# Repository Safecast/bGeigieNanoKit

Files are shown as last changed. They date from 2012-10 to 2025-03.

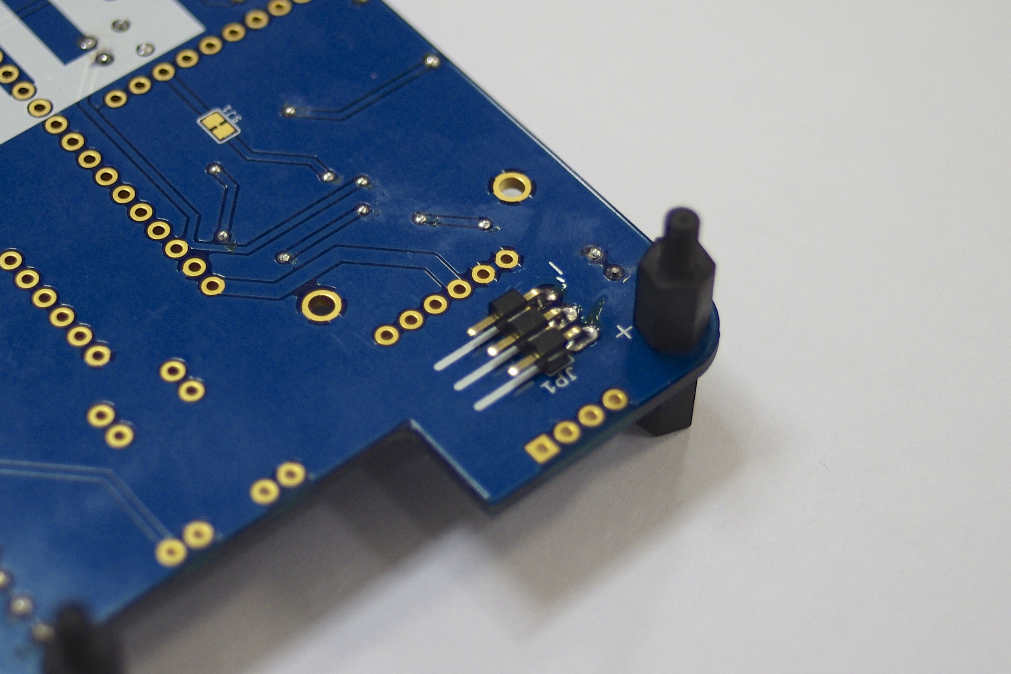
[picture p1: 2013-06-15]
nano manual named pics/iRover_header_tip.jpg

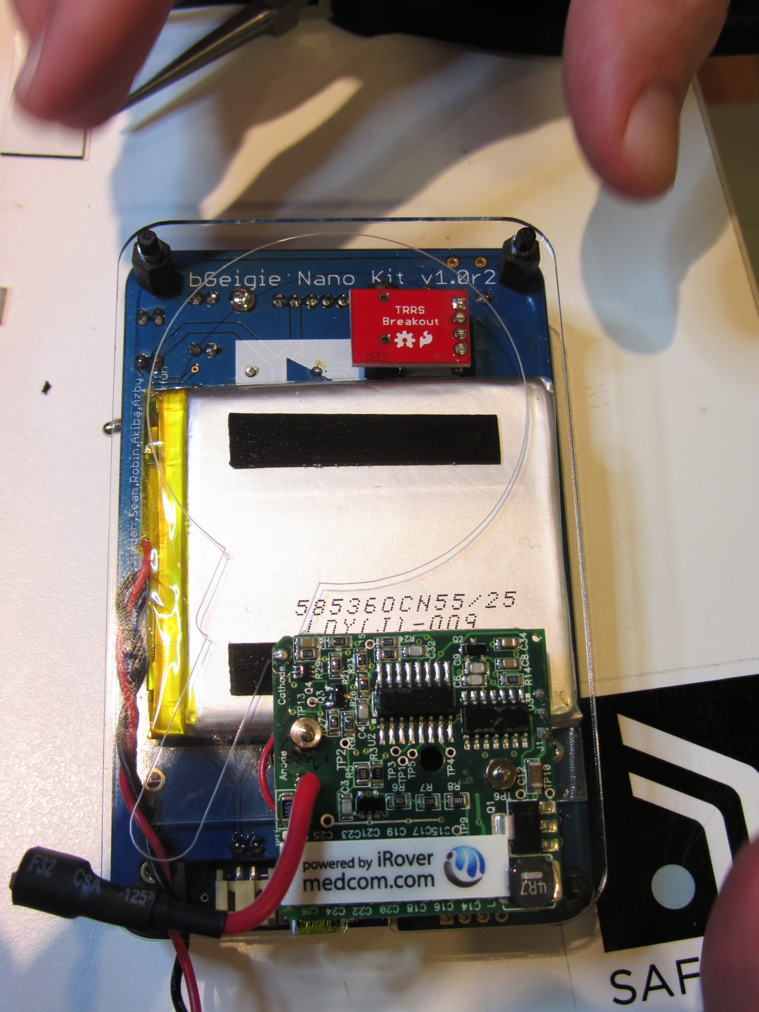
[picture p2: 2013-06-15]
nano manual named pics/iRover_placement_over_battery.jpg

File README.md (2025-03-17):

## bGeigie Nano Kit Operating Instructions (Updated March 2025)

# Table of Contents

1.  [Introduction](#introduction)
2.  [Powering the Device On](#powering-the-device-on)
3.  [Switching Between Modes](#switching-between-modes)
4.  [Measuring Ionizing Radiation in Logging Mode](#measuring-ionizing-radiation-in-logging-mode)
5.  [Measuring Ionizing Radiation in Surface Mode](#measuring-ionizing-radiation-in-surface-mode)
    1. [Alarm](#alarm)
    2. [Data Log](#data-log)
6.  [Uploading Data to the Safecast Database With the Safecast API](#uploading-data-to-the-safecast-database-with-the-safecast-api)
7.  [Uploading Data to Other Datasets](#uploading-data-to-other-datasets)
8. [Using Safecast With Mobile Apps](#using-safecast-with-mobile-apps)
9. [Troubleshooting](#troubleshooting)
    1. [Troubleshooting the iSafecast Geiger Bot App for iOS](#troubleshooting-the-isafecast-geiger-bot-app-for-ios)
    2. [Troubleshooting the iSafecast Geiger Bot App's API](#troubleshooting-the-isafecast-geiger-bot-apps-api)
    3. [Troubleshooting Other Issues](#troubleshooting-other-issues)
        1. [Firmware](#firmware)
    4. [Cleaning](#cleaning)
10. [Warranty Information](#warranty-information)
11. [Hardware Cautions](#hardware-cautions)
12. [Resources and Support](#resources-and-support)

## Introduction
The Safecast bGeigie Nano kit is a *geo-tagged mobile sensor of ionizing radiation*. It is equipped with Internet data sharing capability and optional wireless capability. 

The term "radiation" refers to energy emitted by a source. This includes light, heat, microwaves, and other types of energy. Ionizing radiation is a type radiation that has so much energy that it removes electrons from the atoms and molecules that make up air, water, and living tissue. This activity can harm the molecules in our bodies, leading to diseases like cancer. Radiation can come from either natural or human-made sources. Natural sources include radioactive rocks, elements, and a radioactive gas called radon. Human-made sources include nuclear power plants and medical diagnostic tests, such as x-rays.

The bGeigie Nano measures alpha, beta, and gamma radiation. 

| Type | Description |
| ---- | --- |
| Alpha Radiation | Alpha particles are charged particles that have a large mass and charge. As a result, they don't penetrate materials as easily as other types of ionizing radiation. They also don't travel very far. |
| Beta Radiation | Beta particles are similar to electrons. They are lighter than alpha particles and travel farther, up to a few feet through air. |
| Gamma Radiation | Gamma particles are the most powerful form of ionizing radiation. They travel very far at the speed of light and penetrate most materials easily. Thick layers of concrete, lead, steel, or similar materials are required to stop gamma particles. |

The Nano's maximum operating range is about 350,000cpm, or 1mSv/h (1 millisievert per hour dose rate or 1000µSv/h microsieverts per hour). 

The Nano can be mounted on a car window, or used for static or spot radiation detection. Nano users can submit their mobile radiation measurements to Safecast, an online global mapping system developed by Safecast and MIT Media Lab. 

The Nano also records location, date, and time. The location data allows Safecast to map the measurements and understand the distribution of ionizing radiation. Safecast uses the date and time information to track how ionizing radiation concentrations change over time. The do-it-yourself kit enables customization, cost savings, and learning. 

## Powering the Device On

To turn the unit on, slide the switch at the lower right to the up position. 

The SAFECAST logo will appear on the display for approximately one second. The next start-up screen displays the name of model (bGeigie Nano), the firmware version number, battery charge level, basic settings, and the user’s name (or other customizable information).  

## Switching Between Modes

* The bGeigie Nano has two operating modes, "display" and "recording". To alternate between them, use the toggle switch at the upper right. Label on the transparent top panel: (to the right) "bq/m^2; uS/h", (to left) "log; cpm".

+ The “up” position (to the right) switches the unit into display mode (in which there is no data logging). The fields on the OLED indicate uSv/h dose-rate (Cs137), max dose-rate, dosimeter, Bq/m2 display (Cs137), time stamp, and alarm. 

+ The “down” position puts the Nano into recording mode. The OLED shows indicators for CPM and µSv/h, the number of satellites locked, altitude (meters), distance traversed (km), total duration of measurement (h:m), and time stamp (dd:hh:mm:ss). When the Nano is in recording mode, the OLED shows whether a micro-SD memory card is currently inserted. 

## Measuring Ionizing Radiation in Logging Mode

While in recording mode, the OLED display also shows a GPS lock indicator. When the device locks onto a GPS signal, it will show the number of satellites found, and a small red LED will glow. If the device isn't getting a lock, try placing it near a window for a few minutes.

The small red LED will only glow if the GPS is locked, the SD card is present, the battery has more than 10% charge left, the unit has been on for one minute, and the Geiger tube is providing a pulse. It can be dimmed by setting DIP switch #2 to "Off."

The speaker "clicks" and a small blue LED blinks with each pulse from the Geiger tube. It can be dimmed by setting DIP switch #1 to "Off."

The red LED on the GPS unit blinks every 1 second when the GPS is not locked. Once locked, it blinks every 10 seconds.

The date and time are in __UTC__ (formerly called GMT), rather than local time. The __date/time stamp__ refreshes when log data is written to the card. The LOG's file name is based on the time stamp   (e.g., 21080716.LOG).  The UTC log filename may be +/- one day off from the local date of the measurement, depending on the difference between time zones and distance from the International Date Line (IDL). The file metadata is not updated, which means the log's file creation date may appear with a default date, such as 01/01/2000. For this reason, we recommend that you sort your logs by filename instead of the date field.  When uploading a log, please enter its metadata in the required fields, and submit it for approval. 

**GPS Reset Procedure** (ver 1.3.0 and later)

To reset the GPS device: 

1) Turn off the bGeigie
2) Remove the SD card
3) Turn the bGeigie back on and leave it on for one minute 

    After approximately 10 seconds, the display will show the message "NO SD CARD/GPS Reset." Note that powering the unit on without the SD card will cause an error and **re-initialize the unit, including the GPS controller**.

4) Turn the device off again
5) Insert the SD card

## Measuring Ionizing Radiation in Surface Mode

Use surface mode to detect surface contamination. Removing the Nano from its case while in surface mode can increase the Nano's ability to detect alpha and beta radiation.

1. Remove the Nano from its case (with or without the rubber liner). Use both thumbs to push the unit in and then swivel it out. When you reinsert the Nano into the case later on, you can do it either above or inside the removable rubber liner.

While in uSv/Bq mode, the display also shows the peak dose rate (in uSv/h), total accumulated dose (in uSv), and CPM. 

The mode switch sets the bGeigie Nano into "Log Mode" (switch down "log cpm"). In Log Mode, the largest area of the display ("the big numbers") shows the count rate in CPM, and data will be written to the SD card.  In "Survey Mode" (switch up "Bq/m2 uSv/h"), the main part of the display will show the dose rate in microsieverts per hour.

- To measure the uSv dose rate accurately, put the Nano in the case, hold it 1m above the ground, tilt it around 45 degrees, and then wait for approximately one minute for a stable reading.

- To measure bQ accurately, take the Nano out of the case, keep it within 5cm to 1cm from the surface, and wait approximately one minute for a stable reading. Then, read the value on the second line in Bq/m2. The Nano will emit a speaker sound to aid in finding hotspots.

- The dose rate is based on the assumptions that the Nano is in its case; it is about 1 meter (3ft) away from any object or surface; any gamma rays are of moderate energy (600~700KeV); and the unit has met the previous conditions for at least one minute.

- Also in Survey Mode, the second line on the display ("the small numbers") will rotate through several other values. One of those will be Bq/m2. That is only a locally displayed interpretation of the data, and requires very different conditions to be correct: the Nano is _out_ of its case and held 1cm (~half inch) from a surface contaminated with radio cesium. This usage probably only works in Fukushima and Chernobyl.

### Limitations  

The grid on the pancake sensor is only useful when you remove the unit from the case to look for surface contamination. The grid itself has a very small shielding effect, mostly for alpha/beta and weak gamma radiation. The effect is minimal, and can be ignored.

When averaging readings from two different Nanos, you should only compare long-term counting (e.g. number of counts for 10 minutes).
 
### Alarm
- A speaker "clicks" and a small blue LED “Count” blinks with each pulse from the Geiger tube. It can be dimmed by setting DIP switch #1 to "Off."
- A small Red LED “Log/Alarm” flickers on pulse, and remains lit on alarm. It will only glow if the GPS is locked, the SD card is present, the battery has more than 10% charge left, the unit has been on for one minute, and the Geiger tube is providing a pulse. It can be dimmed by setting DIP switch #2 to "Off."
- The Piezo buzzer may not loud enough for all users. There are solder pads available on the Nano main board for an optional audio-out connector that can be used to connect an amplifier or sound recorder to get louder clicks, if desired.

### Data Log

In recording mode, the data log file writes to the micro-SD card. A key to the fields in the Data Log is available in the [bGeigie library README.md by fakufaku](https://github.com/Safecast/SafecastBGeigie). 

The data is formatted similarly to the NMEA sentences that GPS uses. It begins with a dollar sign ($) and ends with an asterisk (*). A checksum follows the star.

>Radiation Data Sentence: This is the basic message containing the geo-located radiation measurement.

>EXAMPLE:

>$BNRDD,300,2012-12-16T17:58:31Z,30,1,116,A,4618.9612,N,00658.4831,E,443.7,A,5,1.28*6D

**KEY**

| Field | Description | Example|
| ----- | --- | ---- |
| Header | the device model header | Mini=BMRDD, Nano=BNRDD, NX=BNXRDD |
| Device ID | the device serial number | 300 |
| Date  | the date, formatted according to the ISO-8601 standard, usually in UTC | 2012-12-16T17:58:31Z |
| Radiation 1 minute  | the number of pulses given by the Geiger tube in the last minute | 30 |
| Radiation 5 seconds  | the number of pulses given by the Geiger tube in the last 5 seconds | 1 |
| Radiation total count | the total number of pulses recorded since startup |  116  |
| Radiation count validity flag  | 'A' indicates the counter has been running for more than one minute, and the one-minute count is not zero. Otherwise, the flag is 'V' (void) | A |
| Latitude | as given by GPS; the format is ddmm.mmmm, where dd is decimal degrees and mm.mmmm is decimal minutes |  4618.9612 |
| Hemisphere |  'N' (north), or 'S' (south) | N |
| Longitude | as given by GPS; he format is dddmm.mmmm where ddd is decimal degrees and mm.mmmm is decimal minutes | 00658.4831 |
| East/West | 'W' (west) or 'E' (east) from the Prime Meridian | E |
| Altitude |  the altitude (above sea level), as given by the GPS, in meters | 443.7 |
| GPS validity | 'A' = Available or OK, 'V' = Void or invalid | A |
| Number of satellites | the number of satellites used by the GPS | 5 |
| HDOP | the Horizontal Dilution of Precision (HDOP), or relative accuracy of the horizontal position | 1.28 |
|Checksum |  | *6D |

*(For possible updates, see the current [README.md](https://github.com/Safecast/SafecastBGeigie/blob/master/README.md) in the technical GitHub repository)*

The data log file name is comprised of three parts: The DID number, the month the log was initiated, and the day the log was initiated. For example, "21080716.LOG" is the data log for unit 2108 from 16 July. Due to space constraints, the file date property is 01/01/2000. However, every line has UTC time date stamp reading.  The log file name may appear to be a day off due to time zone differences.

A data log or section begins with several comment lines, which begin with hash signs (#).

EXAMPLE:

>\# NEW LOG

>\# format=1.2.9nano

>\# deadtime=on

>$BNRDD,2108,2013-12-06T13:03:58Z,22,2,115,A,3145.7607,N,03510.1975,E,734.90,V,3,908*64

One of the comment lines contains the deadtime. [Deadtime](http://en.wikipedia.org/wiki/Dead_time) is "the time after each event during which the system is not able to record another event."  You can find the *ENABLE_LND_DEADTIME compensation formula* in the [bGeigieNano.ino master repository](https://github.com/Safecast/bGeigieNanoKit/blob/master/src/bGeigieNano.ino). 

### Uploading Data to the Safecast Database With the Safecast API

Your device is designed to submit data to the Safecast database through the Safecast API. To enable data submission, you’ll need to obtain an API key. The key is a credential that gives you access to the API, much like a username and password give you access to an email account.

You can [register on the Safecast site](https://api.safecast.org/en-US/users/sign_up) to get an API key. 

You can learn about how the Safecast API works by visiting the [API documentation](https://api.safecast.org/).

### Uploading Data to Other Datasets

Nano data can be submitted to other radiation mapping datasets. For example, the free [Geiger Bot iOS app](https://sites.google.com/site/geigerbot/) allows you to upload data to servers other than the [Safecast API dataset](https://api.safecast.org/). To do so, you'll need to configure the app with the details of your device, the particular sensor, data format, connection, and other information.  

### Using Safecast With Mobile Apps 

The official (currently not availble)[Safecast app for iOS](https://itunes.apple.com/us/app/safecast/id571167450?mt=8) brings our extensive dataset of radiation measurements to your mobile device, and provides a full toolset to help you perform measurements with your own instrument such as a Geiger or scintillation counter (not included). The app functions as a virtual Geiger counter, allowing you to see your location on a map while displaying radiation readings that have been taken nearby. The app is currently for iOS only. 

In addition, the Safecast Drive app [Android](https://github.com/Safecast/bGeigie-Drive) enables you to:

- Connect with your bGeigieNano (if you have the [bGeigeCast](https://bgeigiezen.safecast.jp/store-2/bgeigiecast-build-for-bgeigienano/) module installed), record data, and upload the data to Safecast directly, without removing your MicroSD card
- Access previous logs and update their status

**Common Issues**

1. Wrong cable - A "null modem" cable that swaps wires internally may cause problems. The cable should be straight/passthrough.
2. Input voltage too high - Interferes with the audio route and the audio engine's watchdog timer.
3. Mic-ground in the cable not shorted correctly - The app will report an audio route change to "Headphones" on the console. The audio route required for a line input cable is "Headset."

>>Nick Dolezal is working hard on the new version of the Safecast app (which will allow on demand refreshing of the map data) decided to whip up these alternate visualizations of the Safecast data. These maps show the frequency of samples taken – NOT READINGS OF THOSE SAMPLES – just showing how often a specific place has been measured. In this example, a location (like Fukushima) that has been measured repeatedly would show hot. Thought this was a really interesting look at the work Safecast has done over the last 2+ years

#### Troubleshooting the iSafecast Geiger Bot App's API

On the main numeric display of the app, you can tap on the top part of the screen to show detailed log messages containing information on connection attempts, and which input device is selected. If successful, the API upload will return HTTP 201 CREATED.

**Verify Input**

1. Tap the min/max arrow button in the lower-right hand corner of the map to resize it into a small window. The interface will display fixed buttons at the bottom, and four possible display screens at the top. These four screens are "Main Numeric Display," "CPS/CPM graph," "Audio input monitor graph," and "Map."

2. Tap the "<" button next to the white page dots under the map. The audio input monitor will appear.

3. Verify that the counts from the Onyx appear and that they're correct. The black line represents the input. The stationary red line represents the threshold the input volume must exceed for it to be counted. The black line will appear blue when it has been counted as a pulse.

If you're unable to verify input, you may have a defective serial cable. A "Geiger Pulse" setting on the Onyx of other than the default value of 6 may also cause problems. 

4. Configure the App's Settings

a. Tap the "Settings" icon on the fixed button panel (the machine gear). Scroll to the bottom of the list and select "Safecast."
b. Enter your API key. Change the upload interval as desired, but do not change the Safecast device back to Nano. 

#### Troubleshooting Other Issues

If you experience problems with the display, check all solder joints carefully to verify that you haven't missed a joint, or that you don't have a cold solder joint. These issues can cause the display to act unpredictably.

You can report bugs and other issues at the [issues page](https://github.com/Safecast/bGeigieNanoKit/issues) of the Safecast GitHub repository. Volunteer users report problems and bugs in the devices discussion group. 

##### Firmware
* For the current version of the firmware, see the the .hex file in the [bGeigieNanoKit repository](https://github.com/Safecast/bGeigieNanoKit).

* To learn how to update the firmware of the Fio via FTDI, see the ["How to Update the Firmware" page](https://github.com/Safecast/bGeigieNanoKit/wiki/How-to-Update-the-Firmware) of this wiki.

### Cleaning

To clean the unit:

1. Remove the Nano from the case. Never wet the Nano's interior. 
2. Use a soft brush and air blower on the Nano, carefully. A vacuum may be another option (electronics labs use unheated air blowers for dusting off parts.)
3. Rinse the liner in clean water, if necessary. 
4. The case may be rinsed with a clean, slightly damp microfiber cloth. 
5. Turn the screen display off and wait until it's cool before wiping the LEDs. Wipe the screen using light pressure.  Use clean, lint-free cotton, microfiber cloths or low-lint wipes. 

### Warranty Information

For warranty information, email [contact@safecast.org](contact@safecast.org). 

**Calibration** 

“The sensor is pre-calibrated. The calibration of the unit for Bq for Cs assumes the grid is in front of the pancake. The difference is around 5%. For gamma only, the grid has a negligible effect on the measured value.

The uSv/h conversion from CPM is calibrated assuming the grid is on the tube. As all Safecast measurements are done with the pancake WITH grid, please keep the grid on the tube. The grid itself will not block alpha or beta radiation, but will reduce the sensitivity slightly, as the grid covers a small portion of the sensor. In practice, the difference with and without grid will be around 4-5% for a beta source, and less for a gamma source, according to bGeigie Nano user Jam.

The software we have preloaded on the device takes the sensor type into account and calibrates readings for Cs137. All bGeigie Nanos have the same configuration and can be compared against one other. A bGeigie Nano's calibration should never change, unless the device is broken. 

### Hardware Cautions

- The Pelican micro case is shockproof and water-resistant. However, it is not waterproof and it cannot be used underwater. Condensation can build up inside the case, due to temperature differences. While this condensation will evaporate with time, you can also remove it by opening the unit and drying it with fiber-free cloth. 

- Do not use the unit outside of its water-resistant case with wet hands, in the rain, or close to a dripping tap. 

- The Micro-SD cannot be read through a USB port. Use a micro-SD card reader instead.

**Battery Cautions:** 

Charge the unit with the mini-USB cable. The yellow LED will dim once the unit is fully charged. A full charge takes 5-6 hours. The bGeigie Nano runs approx 35-40 hours on a full charge in recording mode. 

The main battery indicator is the icon at the bottom right of the display. The percent of battery charge appears on the startup screen.

**NEVER charge the bGeigie while the unit is on.** The power MUST be turned OFF before charging to avoid permanent damage to the charge circuit. 

+ Replace a broken battery (that has a detached wire) with one that has the same rating (2000mAh 3.7V Lithium Polymer (Li-Po, Li-Poly). The Nano charge circuit may overheat if you use a larger battery.

+ A Li-Po battery can be hazardous if the mylar membrane is punctured. Please handle batteries carefully! 

**SENSOR Cautions:**

Although the Nano sensor inside its closed Pelican micro-case is well protected from shock and pressure transients, sudden changes in pressure (such as slamming a car door) may damage the sensor. The pressure inside the tube is very low, and the membrane is under constant tension from atmospheric pressure. Being at altitude *reduces* the strain on it. Because the membrane is mica (basically extremely thin glass), it is low-density and very brittle. A sharp shock can shatter it, and it will pop if something pokes it. 

- To avoid damage to the pancake sensor, NEVER touch the membrane! 

**Onyx Hardware Precautions:**

To keep the Onyx™ in good condition, handle it with care, and observe the following precautions:

- Do not contaminate the Onyx™ by touching it to radioactive surfaces or materials. Instead, hold it just above the surface that is suspected of contamination to take readings. 

- Do not leave the Onyx™ in temperatures over 122° F (50° C), or in direct sunlight for extended periods of time. 

- If the surface of the mica on your pancake detector becomes scratched or loses its coating, avoid making measurements with the detector window in direct sunlight, as this could affect the readings. 

- Do not put the Onyx™ in a microwave oven. It cannot measure microwaves, and you may damage it or the oven. 

#### Resources and Support

- [Nano catch-all landing page](https://safecast.org/bgeigie-nano/)

- [Safecast website](https://safecast.org/) - articles, news, notices, API uploads, crowdsourced radiation data and maps, and more

- [Safecast Devices Discussions and Support group](https://groups.google.com/forum/?hl=en#!forum/safecast-devices)

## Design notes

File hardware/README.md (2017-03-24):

# HW development for bGeigieNanoKit has moved
## New V1.0r4 boards eagle files are in bGeigieNanoKit v1.0r4 folder 
## Older development can be found here [SafecastEagleHW] (https://github.com/Safecast/SafeCastEagleHW)

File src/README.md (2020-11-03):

# Welcome to bGeigie Nano Kit project  
[Main bGeigie Nano page](http://blog.safecast.org/bgeigie-nano/)  
Assembly and Operations Manual can be found on the [Wiki](https://github.com/Safecast/bGeigieNanoKit/wiki)  
  
The Safecast bGeigie Nano is a mobile, GPS enabled, logging, radiation sensor. It is designed for mounting on the outside of a car window but can be used on bicycles, trains, planes, and other modes of transportation.  
  
It can also be used for taking static readings and contamination findings. In logging mode, the Nano takes a measurement every 5 seconds and logs the time and location coordinates.  

# Acknowledgements
This work would not exist without the original development by [bidouilles] (https://github.com/bidouilles/bGeigieNano) and contributions of other [safecast] (https://github.com/Safecast/bGeigieNano) developers.

# Requirements
* bGeigieNanoKit can be bought online from [KitHub](https://shop.kithub.cc/products/safecast-bgeigie-nano)
* for programing/updating software you need a FTDI cable drivers are at http://www.ftdichip.com/Drivers/VCP.htm
* solder iron
* time to make the kit (3-4 hours is normal)

# Build process 
(Needs compiler for example Crosspack-AVR on Mac)
http://www.ladyada.net/learn/avr/setup-mac.html

## Using the Makefile
    export ARDUINODIR=/home/geigie/arduino-1.0.1/
    export SERIALDEV=/dev/ttyUSB0
    export BOARD=fio
    cp -r libraries /home/geigie/arduino-1.0.1/
    make
    make upload

## Using the prebuilt image
You can use directly the prebuilt image to flash the Arduino Fio. Here is an example with Arduino Fio connected to ttyUSB0:

    /usr/bin/avrdude -DV -p atmega328p -P /dev/ttyUSB0 -c arduino -b 57600 -U flash:w:bGeigieNano.hex:i
    
Or Windows Users can download a small program called Xloader (http://russemotto.com/xloader/) and can directly flash a HEX file to the bGiegieNano (assuming you have a FDTI connection. Can be bought at many places like Adafruit, Seeedstudio, Switch-science etc.
Download and installed X-loader. Do not use the USB charging port on the Nano, but the 6 pin FTDI connector on the edge of the CPU board.
Purchase a   https://www.sparkfun.com/products/9873      FTDI breakout adapter.
 
When you plug this little FTDI breakout board onto the 6 pin header and then plug in via a usb cable into your computer, the Nano will power up by itself (even though the power switch is off).  Be careful here as you can plug it in upside down, so match the pins on the FTDI board with the pins on the cpu module.
 
Monitor the device manager com ports to see the device appear and what com # Windows assigned to the device.
 
Then Run X-loader, select com port, browse to HEX file, and I selected in the drop down Duemilanove/nano(ATmega328) device.  Leave the baud rate at 57600 and hit upload.   When it is done, the Nano rebooted/restarted all by itself and is running the new code.     Remove the FTDI board and usb cable to computer, and the Nano will power off. 

# Assembly

## Pins assignment

# Power consumption

* **Fio**: 0.045mA sleep, 6mA at run time
* **OpenLog**: 2mA idle, 6mA at maximum recording rate
* **Adafruit Ultimate GPS**: 25mA acquisition, 20mA tracking
* **Monochrome OLED 128x32 0.91"**: 4mA 50% turn-on, 7.8mA 100% turn-on

## Estimation
The total current used at run time can be estimated around 36mA (= 6+6+20+4) per second which will result in a consumption of 0.01mAh (= 36mA/3600). So
the total log duration if using a battery of 1300mAh will be (1300/.01)/3600 = 36.11 = **36h06m**

## Summary table

| Battery capacity (mAh) | Estimated log duration (days hh:mm) |
| :---: | :---: |
| 1300 | 1d 12:06 |
| 2600 |  3d 00:13 |
| 6600 |  7d 15:19 |

# Usage
Once powered on the bGeigieNano will initiliaze a new log file on the SD card, setup the GPS and start counting the CPM.

# Sample log

    # NEW LOG
    # format=1.0.0nano
    $BNRDD,204,2012-09-20T16:53:58Z,776,63,33895,A,5641.7788,N,1411.8820,E,9861.20,A,109,9*46
    $BNRDD,204,2012-09-20T16:54:03Z,771,61,33956,A,5642.2047,N,1412.9433,E,9862.60,A,109,9*4D
    $BNRDD,204,2012-09-20T16:54:08Z,773,70,34026,A,5642.6305,N,1414.0053,E,9865.00,A,109,9*40
    $BNRDD,204,2012-09-20T16:54:13Z,768,59,34085,A,5643.0562,N,1415.0662,E,9866.80,A,108,9*4D
    $BNRDD,204,2012-09-20T16:54:18Z,765,59,34144,A,5643.4820,N,1416.1277,E,9868.10,A,108,9*4D
    $BNRDD,204,2012-09-20T16:54:23Z,776,70,34214,A,5643.9077,N,1417.1884,E,9870.40,A,90,10*4E
    $BNRDD,204,2012-09-20T16:54:28Z,790,69,34283,A,5644.3330,N,1418.2491,E,9871.30,A,90,10*44
    $BNRDD,204,2012-09-20T16:54:33Z,792,77,34360,A,5644.7576,N,1419.3115,E,9871.40,A,90,10*41
    $BNRDD,204,2012-09-20T16:54:38Z,800,73,34433,A,5645.1819,N,1420.3749,E,9872.60,A,90,10*4C
    $BNRDD,204,2012-09-20T16:54:43Z,784,57,34490,A,5645.6060,N,1421.4371,E,9873.10,A,89,10*4A
    $BNRDD,204,2012-09-20T16:54:48Z,787,58,34548,A,5646.0298,N,1422.4998,E,9874.10,A,89,10*40
    $BNRDD,204,2012-09-20T16:54:53Z,792,76,34624,A,5646.4534,N,1423.5620,E,9874.80,A,98,9*73
    $BNRDD,204,2012-09-20T16:54:58Z,804,75,34699,A,5646.8769,N,1424.6242,E,9874.30,A,98,9*74
    $BNRDD,204,2012-09-20T16:55:03Z,808,65,34764,A,5647.3011,N,1425.6873,E,9877.10,A,98,9*7F
    $BNRDD,204,2012-09-20T16:55:08Z,793,55,34819,A,5647.7236,N,1426.7514,E,9876.30,A,89,10*49
    $BNRDD,204,2012-09-20T16:55:13Z,799,65,34884,A,5648.1464,N,1427.8159,E,9876.10,A,98,9*7F
    $BNRDD,204,2012-09-20T16:55:18Z,795,55,34939,A,5648.5688,N,1428.8810,E,9877.80,A,98,9*7B
    $BNRDD,204,2012-09-20T16:55:23Z,774,49,34988,A,5648.9898,N,1429.9472,E,9878.50,A,85,10*46
    $BNRDD,204,2012-09-20T16:55:28Z,768,63,35051,A,5649.4098,N,1431.0137,E,9877.40,A,224,8*4A
    $BNRDD,204,2012-09-20T16:55:33Z,754,63,35114,A,5649.8297,N,1432.0798,E,9876.30,A,223,8*4F
    $BNRDD,204,2012-09-20T16:55:38Z,752,71,35185,A,5650.2496,N,1433.1447,E,9873.20,A,106,9*4C
    $BNRDD,204,2012-09-20T16:55:43Z,753,58,35243,A,5650.6698,N,1434.2092,E,9871.30,A,106,9*40
    $BNRDD,204,2012-09-20T16:55:48Z,765,70,35313,A,5651.0904,N,1435.2737,E,9869.50,A,106,9*4B

# Notes
## OpenLog config

The OpenLog should start listening at 9600bps and in Command mode. Here is the content of the CONFIG.TXT file you have to create on the microSD card:

    9600,26,3,2

## SAFECAST.TXT explanation.

The content of the SAFECAST.TXT file can be altered. Please be carefull not to insert CR/LF (windows edittor does that automatically)

    cpmf      cpm factor
    bqmf      bq/m2 factor
    nm        name  
    did       devide id  
    gt        geiger type  
    gm        geiger mode  
    al        alarm threshold  
    cn        country code  
    tz        timezone  
    st        sensor type   
    ss        sensor shield  
    sh        sensor height  
    sm        sensor mode  
    dose      Reset total dose  

## SoftwareSerial update

To make sure all of the NMEA sentences can be received correctly, we will need to update the _SS_MAX_RX_BUFF definition from arduino-1.0.1/libraries/SoftwareSerial/SoftwareSerial.h header file. Here is the modification:

    //#define _SS_MAX_RX_BUFF 64 // RX buffer size -- Old Value is 64
    #define _SS_MAX_RX_BUFF 128 // RX buffer size for TinyGPS

# Licenses
 Licenses for this repository can be found at [here][10]
 
 * [InterruptHandler and bGeigieMini code][5] - Copyright (c) 2011, Robin Scheibler aka FakuFaku
 * [TinyGPS][6] - Copyright (C) 2008-2012 Mikal Hart
 * [Makefile][8] - Copyright (c) 2012, Tim Marston

  [1]: https://github.com/sparkfun/OpenLog "OpenLog"
  [2]: https://www.adafruit.com/products/661 "Monochrome 128x32 OLED"
  [3]: https://www.sparkfun.com/products/10116 "Arduino Fio"
  [4]: http://www.lndinc.com/products/17/ "LND-7317"
  [5]: https://github.com/fakufaku/SafecastBGeigie-firmware "SafecastBGeigie-firmware"
  [6]: http://arduiniana.org/libraries/tinygps/ "TinyGPS"
  [7]: https://www.adafruit.com/products/746 "Ultimate GPS"
  [8]: http://ed.am/dev/make/arduino-mk "Arduino Makefile"
  [9]: http://www.pelican.com/cases_detail.php?Case=1010 "Pelican 1010"
  [10]: https://blog.safecast.org/faq/licenses/

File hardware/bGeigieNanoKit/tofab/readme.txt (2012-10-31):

Safecast
P/N bGeigie

Quantity: 10
Layers: 2
Copper: 1oz. base copper weight
Thickness: 0.062" FR4
Solder mask: blueOB
Silkscreen: white

Notes: 
N/A

Printouts:
bGeigieNanoKit.pdf - PDF of schematic
bGeigieNanoKit_brd.pdf - PDF of layout
bGeigieNanoKit_gerbers.pdf - PDF of gerbers

Apertures:
bGeigieNanoKit.gpi - Gerber Plot info

Board stackup:
bGeigieNanoKit.sst - Silkscreen Top
bGeigieNanoKit.smt - Solder Mask Top
bGeigieNanoKit.spt - Solder Paste Top
bGeigieNanoKit.top - Top
bGeigieNanoKit.bot - Bottom
bGeigieNanoKit.smb - Solder Mask Bottom

Drill info:
bGeigieNanoKit.dri - Drill rack
bGeigieNanoKit.drd - Excellon Drill

Assembly info:
bGeigieNanoKit.asm - Assembly drawing
bGeigieNanoKit.hls - Holes
bGeigieNanoKit.bom - Bill of materials

Misc:
bGeigieNanoKit.gwk - GC preview workspace
bGeigieNanoKit.rep - Eagle Statistics report for board
bGeigieNanoKit.cnt - Simple stats, counts of pads, components, pads, ...

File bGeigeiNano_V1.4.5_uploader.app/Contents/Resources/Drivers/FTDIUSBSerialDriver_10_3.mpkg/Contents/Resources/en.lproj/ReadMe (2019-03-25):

{\rtf1\ansi\ansicpg1252\cocoartf1038\cocoasubrtf360
{\fonttbl\f0\fswiss\fcharset0 ArialMT;}
{\colortbl;\red255\green255\blue255;}
\paperw12240\paperh15840\margl1440\margr1440\vieww9000\viewh9000\viewkind0
\pard\tx1440\tx2880\tx4320\tx5760\tx7200\ql\qnatural

\f0\fs36 \cf0 FTDIUSBSerialDriver ReadMe\

\fs24 \
FTDIUSBSerialDriver is an implementation of a serial driver for FTDI USB devices on Mac OS X.  It supports FT8U232AM, FT8U245AM, FT232BM, FT245BM, FT2232, FT232R, FT245R, FT2232H, FT4232H, FT232H and FT X Series devices.\
\

\fs28 Revision History\
\

\fs24 v2.2.17	(24th February 2012)\
	Corrected issue with custom port names.\
	Release for Lion.\
\
v2.2.16	(28th February 2011)\
	Added support for FT232H.\
	Force FT232R/FT245R endpoint size to 64 bytes.\
\
v2.2.15	(3rd February 2011)\
	Corrected baud rate requests using sub-integer divisors.\
\
v2.2.14	(25th August 2009)\
	Release for Snow Leopard.\
\
v2.2.13	(25th August 2009)\
	HiddenPort property now set as standard.\
\
v2.2.12	(7th July 2009)\
	Includes x86_64 support.\
\
v2.2.11	(17th April 2009)\
	Removed user notification dialog box.\
\
v2.2.10	(6th August 2008)\
	Added support for FT2232H and FT4232H.\
\
v2.2.9	(8th January 2008)\
	Added option to select serial port base name.\
\
v2.2.8	(9th November 2007)\
	Fixed open() problem with FT8U232AM.\
\
v2.2.7	(22nd August 2006)\
	Fixed send break problem.\
\
v2.2.6	(21st July 2006)\
	Fixed flow control problem.\
	Fixed close port problem after stall.\
\
v2.2.1	(14th April 2006)\
	Universal binary.\
\
v2.1.1	(14th April 2006)\
	Fixed problem with modem status.\
\
v2.1.0	(19th December 2005)\
	Added option to alias all standard baud rates to same value.\
\
v2.0.1	(24th August 2005)\
	Fix intermittent problem with receive data.\
\
v2.0.0	(15th August 2005)\
	Full release; new driver design.\
\
v2.0.0b18	(9th August 2005)\
	Beta release; new driver design.\
\
v1.1.2	(19th July 2005)\
	Fixed panic that could occur on opening device.\
\
v1.1.0	(30th June 2005)\
	Supports FT2232C.\
\
v1.0.10	(17th June 2005)\
	Fixed disconnect problem on 10.4.\
\
v1.0.9	(18th December 2003)\
	Fixed problem where B50 and B75 could not be selected.\
\
v1.0.8	(18th August 2003)\
	Supports non-standard baud rates.\
\
v1.0.7	(16th June 2003)\
	Fixed modem control line problem.\
	Fixed send break problem.\
\
v1.0.6	(7th March 2003)\
	Supports higher baud rates.\
\
v1.0.5	(13th January 2003)\
	Purge FIFOs on acquire port.\
\
v1.0.4	(17th December 2002)\
	Fixed CTS change state.\
\
v1.0.3	(9th December 2002)\
	Fixed flow control.\
\
v1.0.2	(6th December 2002)\
	Fixed USB surprise removal problem.\
	Fixed support for RTS/CTS flow control.\
\
v1.0.0	(5th November 2002)\
	Full release.\
	Supports re-enumeration during reboot.\
\
v1.0.0b6	(3rd November 2002)\
	Supports multiple device IDs.\
	Fixed device naming problem.\
\
v1.0.0b4	(12th September 2002)\
	Packaged for distribution and installation.\
\
\

\fs28 Contact Us\
\

\fs24 For more information, visit the FTDI web site at : http://www.ftdichip.com\
\
\
\
\
\
	\
}

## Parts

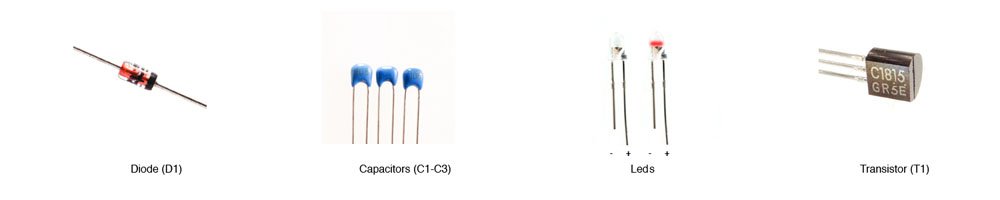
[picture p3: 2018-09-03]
nano manual named pics/manual update Aug 2018 small JPEG selects/006-SmallComponents011000px.jpg

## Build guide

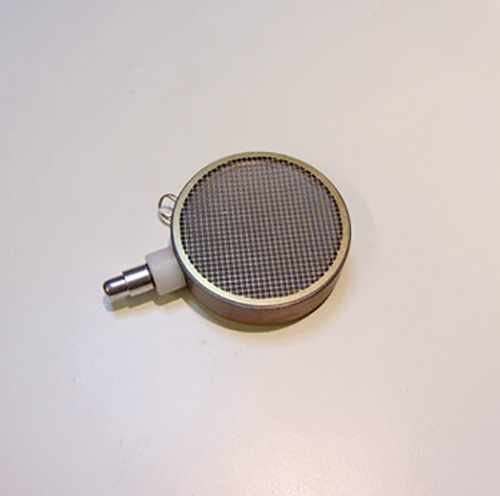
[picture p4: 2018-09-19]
nano manual named pics/manual update Aug 2018 small JPEG selects/sensor-screen-small01[new].jpg

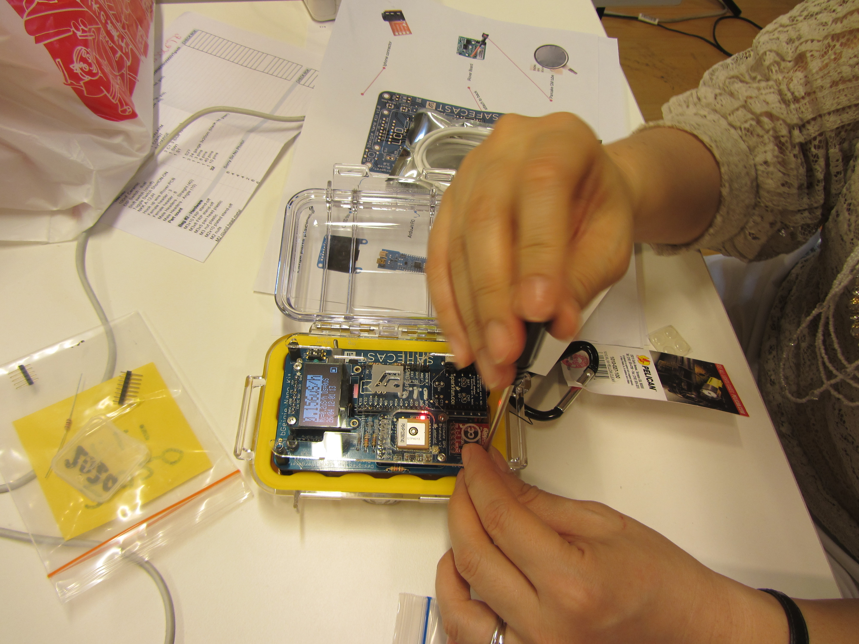
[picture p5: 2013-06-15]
nano manual named pics/front_plate_assembly.jpg

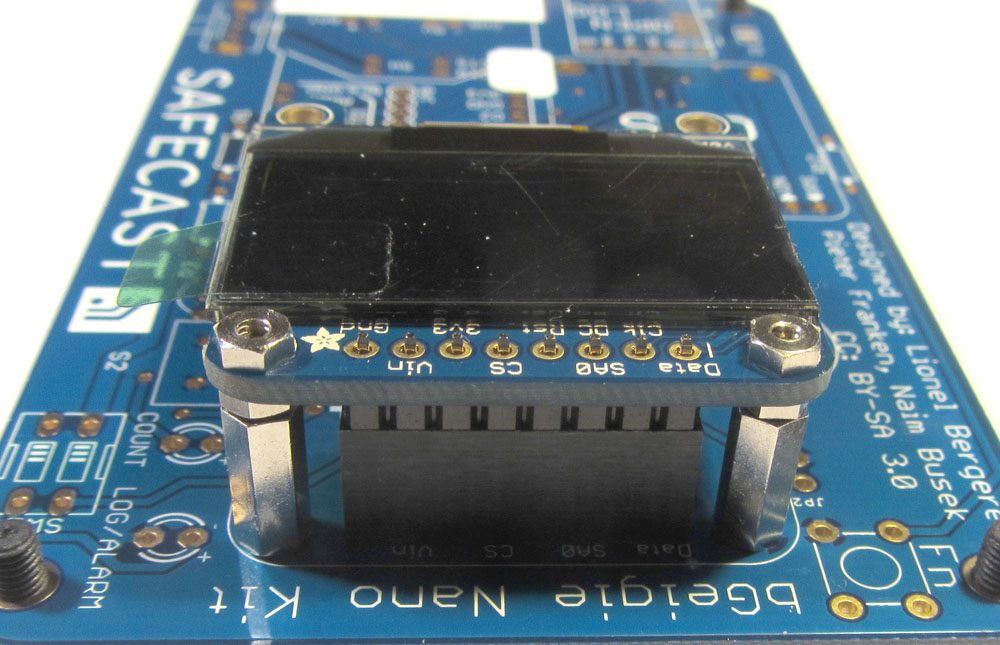
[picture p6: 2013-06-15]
nano manual named pics/lcd_placement_back.jpg

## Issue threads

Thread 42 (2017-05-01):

where is on and off positions of switches?

holretz, 2017-05-01:
It is written several times that circuits could be damaged if the power switch is not turned off, also the small under  the board with the sparkfun.com inscription should be turned off. But I can't find any description what the on and off positions are. So in order not to damage anything the project is temporarily haltet.
Can anyone by words or pictures or any other method tell me what are the on and off-positions of these switches ?  (f.ex. when the small switch is viewed from the side with the "safecast" text, it should be in the rightmost position to be switched off....or the leftmost....).

Schmidt
Greenland

dmwco, 2019-04-17:
The location of the on and off positions of the POWER SWITCH are (at least as of my kit, in April 2019) engraved on the top plastic plate.  I agree it's very hard to tell from the documentation.

3uky, 2020-05-25:
rightmost

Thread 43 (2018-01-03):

way to improving GPS Signals on bgeige nano

Lugulbanda, 2018-01-03:
hi short question, is there a way to improve that sattelite location for the bgeige nano,
i noticed that i sometimes have lots of measuringpoinst getting flagged out, some times not a single one sometimes half or more of the hole measurment walk/drive, i think most is because of blockign throught strucktures, like tunnels Roofs were the car is staying under, while getting food or fuel, so my questions

is there a way to strengthen the signalantenna?
on wich GPS is the Nano working?
i know there are new chips out wich dont adjust only on one system only, and use glonas gallileo or the chinese gps...
i know special the normal GPS is damped if, some Warstrickes are done in certain regions,
if there is a softwareupdate, for the nano were can i find it, if there is a improved singal calculation ?

seanbonner, 2018-01-04:
There is a little connector for an antenna on the GPS module if you feel the need to attach an antenna, but we use that Ultimate GPS breakout board and chip because it’s head and shoulders better than everything else we tried. There’s no new firmware to make it better, any GPS will stop working when you are inside a structure because it’s recalculating your position all the time and if it can’t see any satellites then it will not connect to any to get a reading. If you are having problems with your GPS getting readings when you are outside walking then you might just need to reset it, take the SD card out, turn the bGeigie on for 1 minute and then turn off and put SD card back in, that’ll force a hard reboot.

-s

Sean Bonner
Co-Founder, Director of Global Operations
Safecast.org | pgp key

On January 4, 2018 at 1:28:15 AM, Lugulbanda (notifications@github.com) wrote:

hi short question, is there a way to improve that sattelite location for the bgeige nano,
i noticed that i sometimes have lots of measuringpoinst getting flagged out, some times not a single one sometimes half or more of the hole measurment walk/drive, i think most is because of blockign throught strucktures, like tunnels Roofs were the car is staying under, while getting food or fuel, so my questions

is there a way to strengthen the signalantenna?
on wich GPS is the Nano working?
i know there are new chips out wich dont adjust only on one system only, and use glonas gallileo or the chinese gps...
i know special the normal GPS is damped if, some Warstrickes are done in certain regions,
if there is a softwareupdate, for the nano were can i find it, if there is a improved singal calculation ?

—
You are receiving this because you are subscribed to this thread.
Reply to this email directly, view it on GitHub, or mute the thread.

Lugulbanda, 2018-01-04:
thx for the info for reboot, problem is u notice it first if ur at home and look what u measured so far, and then its to late, when this xxx points are flagged out because of no GPS, and there is a lot more GPS over us then only one system...

seanbonner, 2018-01-04:
We are not using “one GPS system” this is an Ultimate GPS chip which can get a signal from any GPS satellite so it works very well everywhere in the world. The display will tell you if you don’t have GPS lock, but again if you are outside then it will work perfectly, inside no GPS will work. If it’s outside and not working then you might have a different problem going on with the soldering or something, but it’s not lack of GPS reception.

On January 4, 2018 at 4:15:47 PM, Lugulbanda (notifications@github.com) wrote:

thx for the info for reboot, problem is u notice it first if ur at home and look what u measured so far, and then its to late, when this xxx points are flagged out because of no GPS, and there is a lot more GPS over us then only one system...

—
You are receiving this because you commented.
Reply to this email directly, view it on GitHub, or mute the thread.

thinrope, 2018-01-04:
@Lugulbanda, yes there exists other non-GPS navigational systems (GNSSes), most useful being GLONASS, but the large field deployment and reliability tests of this particular unit has proven good enough for most purposes. When we test units inside buildings (office, home), we connect additional antenna to the uFL connector with a long cable and set the antenna near a window.
There is always an ongoing "navigational race" and may be one day in the future we can update the design with a navigational module that supports other GNSSes like GLONASS, Galileo, BeiDou, etc. Given the openness of the project, feel free to experiment yourself!

Lugulbanda, 2018-01-05:
thx :)

Closed 2018-01-05.

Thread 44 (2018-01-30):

Drive with ios APP strange Measurement

Lugulbanda, 2018-01-30:
today i made a drive, and uploaded it form my iphon, and as i wanted to edit its metadata, i notices something strange... https://api.safecast.org/en-US/bgeigie_imports/33852

Attention! This log file contains: 「Invalid timestamp(s): 1331, which may signify spatial error.」 「Invalid GPS location(s): 1082 flagged by device.」

3003-0130.LOG
Number Of Lines
0
Number Of Measurements
0

on the end of the drive, i noticed the app signals me GPS Signal not found, but this drive was open wide on air, i reseted the device a few times, also with sd card out, but the GPS didnt came back then as i was thinking something is not right the device and app were working like everyday...

any clue what could chause that ?

thinrope, 2018-01-30:
I looked at the data you submitted to the API as [33852/3003-0130.LOG](https://safecast-production.s3.amazonaws.com/uploads/bgeigie_import/source/33852/3003-0130.LOG) and indeed it contains very wrong timestamps...
````
$BNRDD,3003,2007-00-00T11:24:08Z,29,5,9991,A,5034.2987,N,00830.4857,E,138.40,V,8,103*58
$BNRDD,3003,2007-00-00T11:24:13Z,30,4,9995,A,5034.2861,N,00830.4760,E,139.40,V,8,105*5A
$BNRDD,3003,2004-00-00T11:24:18Z,30,2,9997,A,5034.2562,N,00830.4656,E,139.10,V,8,105*59
$BNRDD,3003,2004-00-00T11:24:23Z,29,3,10000,A,5034.2220,N,00830.4546,E,139.50,V,8,103*66
````

Was the file edited in some way (I don't see the usual header)? Did you submit it via https://api.safecast.org/en-US/bgeigie_imports/new with a browser or some other app?

Since the coordinates look OK most of the time, I am suspecting the GPS didn't catch the timestamp properly on init but decided to start logging.

What firmware are you using (should be displayed on power on)? Where from did you download it?

Lugulbanda, 2018-01-31:
Hi,

1.

no i just startet my bgeige nano, like everytime, then start my ios app, and after connection bootup is finished i press start measure..

2.

after i was on the drive back i took a small rest, and as i wanted to continue the drive i noticed the app had stopped the measurement,

because i noticed the ios app was in the discard upload map mode...

3.

so i pressed upload, and then the cloud button again..

4.

as i wanted to finish the rest of the drive, and started the the drive ap again i got the message "no GPS" , wich was imposible cuz my rest was open in the wide with no high mountains around me...

 5.

so i reseted the app, i reseted the nano, nothing same error, i took out the sd card, reseted it again and still no GPS, so i let e nano hang out and started the drive without starting of the app, as suddently the GPS came back and i made the short measurement after that one,

----------------------------------------
 

on that day i took 4 measurements, 3 were totaly ok no problems

only this one,

and this one was like the others directly uploaded from the ios drive-App,

without any changes in the data, 

actualy i droped my micro sd holder somewere. so i cant check if i had the button for store on nano active, if the holder appears, i take a look into the SD Card and if a file is present i will upload it to the github...

best wishes,

Frank

but ps, i dont know who had the problem, the ios app the nano or the ios drive app, but for some reason the ios drive app had the message NO GPS Signal. maybe a ios problem, as soon i find my SD holder i maybe

can digg deeper to give u more info...

Gesendet: Dienstag, 30. Januar 2018 um 21:50 Uhr
Von: "Kalin KOZHUHAROV" <notifications@github.com>
An: Safecast/bGeigieNanoKit <bGeigieNanoKit@noreply.github.com>
Cc: Lugulbanda <Starlord@gmx.de>, Author <author@noreply.github.com>
Betreff: Re: [Safecast/bGeigieNanoKit] Drive with ios APP strange Measurement (#44)

I looked at the data you submitted to the API as 33852/3003-0130.LOG and indeed it contains very wrong timestamps...

$BNRDD,3003,2007-00-00T11:24:08Z,29,5,9991,A,5034.2987,N,00830.4857,E,138.40,V,8,103*58
$BNRDD,3003,2007-00-00T11:24:13Z,30,4,9995,A,5034.2861,N,00830.4760,E,139.40,V,8,105*5A
$BNRDD,3003,2004-00-00T11:24:18Z,30,2,9997,A,5034.2562,N,00830.4656,E,139.10,V,8,105*59
$BNRDD,3003,2004-00-00T11:24:23Z,29,3,10000,A,5034.2220,N,00830.4546,E,139.50,V,8,103*66

Was the file edited in some way (I don't see the usual header)? Did you submit it via https://api.safecast.org/en-US/bgeigie_imports/new with a browser or some other app?

Since the coordinates look OK most of the time, I am suspecting the GPS didn't catch the timestamp properly on init but decided to start logging.

What firmware are you using (should be displayed on power on)? Where from did you download it?

—
You are receiving this because you authored the thread.
Reply to this email directly, view it on GitHub, or mute the thread.

Lugulbanda, 2018-02-01:
[30030130.log](https://github.com/Safecast/bGeigieNanoKit/files/1684485/30030130.log) thats the file from my nano SD Card

thinrope, 2018-02-01:
I see your device is:
````
# format=1.3.4nano
# deadtime=on
````
and here is the error (flipping `2018-01-30T17:07:54Z` into `2000-03-00T17:07:54Z`), while `GPS=A` with 7 satellites in view... then back to normal 28*5=140s later
````
$BNRDD,3003,2018-01-30T17:07:44Z,23,2,62,A,5051.6589,N,00804.8337,E,274.20,A,7,104*4B
$BNRDD,3003,2018-01-30T17:07:49Z,26,5,67,A,5051.6766,N,00804.8567,E,274.30,A,7,104*40
$BNRDD,3003,2000-03-00T17:07:54Z,25,2,69,A,5051.6950,N,00804.8819,E,274.30,A,7,104*41
$BNRDD,3003,2000-03-00T17:07:59Z,27,2,71,A,5051.7119,N,00804.9018,E,274.50,A,7,104*4D
$BNRDD,3003,2000-03-00T17:08:04Z,31,5,76,A,5051.7368,N,00804.8930,E,273.40,A,7,104*4D
$BNRDD,3003,2000-03-00T17:08:09Z,30,4,80,A,5051.7675,N,00804.8697,E,272.90,A,7,104*4E
$BNRDD,3003,2000-03-00T17:08:14Z,34,6,86,A,5051.7977,N,00804.8355,E,272.50,A,6,117*4B
$BNRDD,3003,2000-03-00T17:08:19Z,32,1,87,A,5051.8332,N,00804.8152,E,272.00,A,6,117*42
$BNRDD,3003,2000-03-00T17:08:24Z,29,0,87,A,5051.8667,N,00804.7902,E,271.50,A,7,104*45
$BNRDD,3003,2000-03-00T17:08:29Z,29,0,87,A,5051.9038,N,00804.7628,E,271.70,A,7,104*40
$BNRDD,3003,2000-03-00T17:08:34Z,34,6,93,A,5051.9440,N,00804.7606,E,270.70,A,7,104*45
$BNRDD,3003,2000-03-00T17:08:39Z,35,2,95,A,5051.9820,N,00804.7774,E,270.00,A,7,104*42
$BNRDD,3003,2000-03-00T17:08:44Z,34,1,96,A,5052.0175,N,00804.8009,E,270.00,A,7,104*48
$BNRDD,3003,2000-03-00T17:08:49Z,31,2,98,A,5052.0489,N,00804.8344,E,270.60,A,7,104*47
$BNRDD,3003,2000-03-00T17:08:54Z,29,0,98,A,5052.0739,N,00804.8724,E,270.30,A,7,104*4F
$BNRDD,3003,2000-03-00T17:08:59Z,28,1,99,A,5052.0813,N,00804.9018,E,269.70,A,7,104*41
$BNRDD,3003,2000-03-00T17:09:05Z,25,2,101,A,5052.0806,N,00804.9145,E,269.40,A,7,127*78
$BNRDD,3003,2000-03-00T17:09:10Z,21,0,101,A,5052.0730,N,00804.9627,E,269.00,A,7,184*7E
$BNRDD,3003,2000-03-00T17:09:15Z,17,2,103,A,5052.0688,N,00805.0282,E,267.30,A,8,94*4D
$BNRDD,3003,2000-03-00T17:09:20Z,18,2,105,A,5052.0737,N,00805.1001,E,268.70,A,8,94*44
$BNRDD,3003,2000-03-00T17:09:25Z,20,2,107,A,5052.0825,N,00805.1729,E,273.50,A,7,184*7E
$BNRDD,3003,2000-03-00T17:09:30Z,25,5,112,A,5052.0915,N,00805.2492,E,276.60,A,7,184*78
$BNRDD,3003,2000-03-00T17:09:35Z,24,5,117,A,5052.0997,N,00805.3192,E,279.60,A,7,184*78
$BNRDD,3003,2000-03-00T17:09:40Z,25,3,120,A,5052.1078,N,00805.3885,E,282.70,A,7,185*7B
$BNRDD,3003,2000-03-00T17:09:45Z,30,6,126,A,5052.1181,N,00805.4591,E,284.20,A,7,185*72
$BNRDD,3003,2000-03-00T17:09:50Z,32,4,130,A,5052.1409,N,00805.5246,E,284.80,A,8,93*4B
$BNRDD,3003,2000-03-00T17:09:55Z,32,0,130,A,5052.1761,N,00805.5779,E,288.70,A,8,93*4D
$BNRDD,3003,2000-03-00T17:10:00Z,38,7,137,A,5052.2185,N,00805.6287,E,291.40,A,7,185*75
$BNRDD,3003,2000-03-00T17:10:05Z,38,2,139,A,5052.2620,N,00805.6815,E,293.60,A,7,127*7A
$BNRDD,3003,2000-03-00T17:10:10Z,41,3,142,A,5052.2975,N,00805.7395,E,294.30,A,7,127*72
$BNRDD,3003,2018-01-30T17:10:15Z,41,2,144,A,5052.3214,N,00805.8075,E,293.60,A,7,185*7D
$BNRDD,3003,2018-01-30T17:10:20Z,41,2,146,A,5052.3385,N,00805.8805,E,291.70,A,7,127*74
````
Note that the XOR checksum (last 2 chars after *) is correct for all lines, thus (almost) eliminating Fio->SDcard error. It is a bug in the firmware :-(

I had another read of the code and I see something we added to TinyGPS.cpp which can be suspect...
https://github.com/Safecast/bGeigieNanoKit/blob/master/TinyGPS.cpp#L218
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
Lugulbanda, 2018-02-05:
ahm whats the difference into the batterie?

Gesendet mit der GMX Mail App

Am 01.02.18 um 12:25 schrieb Kalin KOZHUHAROV

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

thinrope, 2018-02-05:
The difference is ... I don't know. I am suspecting it may change the way GPS is being reset and the code I highlighted may do something else. But most devices are without a battery, as requested in the build instructions, so having a battery is "not well tested case".

Lugulbanda, 2018-02-05:
hm iam not shure what u mean, i just build in the GPS Module wich came with the nano, i didnt attach any other battery then the nano battery itself on the board.

Lugulbanda, 2018-02-08:
i uploaded the nano savelog, and saw the hole measurement wich chaused the problem was not present, so the only thing wich may be part of the Problem was, the right top switsch was set to Microsievert, and not logging, maybe this chaused the error in the Log on the iphone drive, is it possible??
that if the switsch is set to no write down data,  prevents the nano from writing gps data to the iphone ios drive app?

thinrope, 2018-02-08:
I am not sure the iOS app cares about the switch position...
May be @Frangible can confirm?

Lugulbanda, 2018-02-10:
dont think we have to contact @Frangible, i can simply pull out 2 drives in a street were i wasntn present , wone with set on and one with set off write data switsch, maybe thats the reasson for 2 annother meassurement i had in the past were the GPS was also very strange, just wait i think next week at a new customer i have a good chance for a short testdrive :) i will upload both measurements so we can see if there is a corelation to the swisch

Lugulbanda, 2018-02-19:
i uploaded both the one i measured with the app, and the one i did on that day, from the nano, its clearly seen the switsch was in position not write on nano for that drive, with the maximum error, but.. on the other hand the upload from the nano on that day shows a long drive with only 21 measurements wich is also very strange...

Lugulbanda, 2018-02-19:
all the measurements i did after that day looking good, always 100 plus measurements, even on short drives.. no clue what was causing that on that day, i think i will do tomorrow a drive, with the switch again on position µS not write down data... and will watch what comes out...

Lugulbanda, 2018-03-23:
hi i resumed my memory of that day, i guess the Problem was i switsched the write data switsch on the nano to mµsievert for a surfacemeasurement and forgot to switsch it back to write mode, thats, why my upload from the nano direc has not a single data of that drive... 30030130 from nano upload, looks like the switsch not only prevent data from wirte to sd card, it also stops the timelogdata from transfering to the ios drive app.... @Azby @thinrope

Lugulbanda, 2018-04-14:
wrote it in the problemematic uploads, i think i found the issue, if u work with IOS Drive app and shut down the Nano over a longer time and then activate it again, cuz of the not shut down IOS Drive App wich isnt doing a fresh new Handshake,  there is a bad feedbackloop wich builds up over time untill it distrubs the GPS Data and Sattellite find, tryed it alot of times, and now can say its repeatable and its lead to all those Errors on GPS i had, if i work only with the nano no problems, if i workd with nano and drive app, its important that both have a fres reset on the next measurement... if not something strange happens that enven desturb the GPS funktion on the nano...

Lugulbanda, 2018-05-10:
https://github.com/Safecast/Drive-ios/issues/12 @Azby @matschaffer @thinrope @Frangible @seanbonner

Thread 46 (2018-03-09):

Wrong overlay text on the PCB ?

oz1cxp, 2018-03-09:
Hi

I just bought a kit from kithub, and have soldered the passive component on the pcb, and then i find a problem.
I have been working in electronics for 40+ years, so i know colorcodes by heart, and just placed the resistors according to the text on the PCB, but then when i compared to the picture in the wiki of a PCB with resistors, R8 and R9 are swapped. I have placed them correct according to the text on the PCB, but not according to the placement guide in the wiki, so am I right in thinking that the text is wrong on the PCB ?

jamoross, 2018-03-23:
oz1cxp -

The text is not wrong on the PCB. The positions of R8 and R9 got swapped some time ago.  The image you saw was likely of a unit with a mainboard version V1.0r2, I'm guessing you have the most recent board (V1.1r5) with R8 to the right of R9 (farther from the buzzer).

oz1cxp, 2018-03-27:
thank you, yes it seems like  have a newer PCB than shown in the assembly wiki. I finished the build and it works fine.

Closed 2018-03-27.

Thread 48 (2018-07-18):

bBeigie Nano Mac Uploader 1.4.1 Issue

diehl, 2018-07-18:
Hello,

When I run the latest uploader, I'm seeing the following in the details. Any suggestions?
```
TERM environment variable not set.
Safecast

Firmware Uploader Mac

The following is a list of the available serial ports:

No relevant port
```

diehl, 2018-07-18:
Well I realized one issue. I shouldn't be plugging it into the computer with the power switch set to the on position. Now I'm seeing the following:
```
TERM environment variable not set.
Safecast

Firmware Uploader Mac

The following is a list of the available serial ports:

1. /dev/tty.usbserial-FT9QCYW2

One relevant port so selecting it automatically : /dev/tty.usbserial-FT9QCYW2
1. bGeigieNano.hex
TERM environment variable not set.
Safecast firmware Updater

Writing - bGeigieNano.hex
to port - /dev/tty.usbserial-FT9QCYW2
IC      - atmega328p

avrdude: stk500_recv(): programmer is not responding

avrdude done.  Thank you.
```

robouden, 2018-07-18:
Chris,

Did you remove the BLE Xbee?

regards
rob

Regards,
Rob Oudendijk Yuka Hayashi
http://yr-design.biz   http://oudendijk.biz  http://about.me/robouden
tel +81 80-22605966  Skype: robouden  Facebook:robouden
<http://on.fb.me/QeKw2P> linkedin:robouden
<https://www.linkedin.com/in/roboudendijk>

On Wed, Jul 18, 2018 at 1:18 PM Chris Diehl <notifications@github.com>
wrote:

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

diehl, 2018-07-20:
Thanks Rob. That's exactly the step I was missing.

Best regards,

Chris

Closed 2018-07-20.

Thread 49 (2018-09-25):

Code correction needed? - bGeigie-nano.ino  missing two braces at end of Main loop.

dbgitter, 2018-09-25:
Reviewing the code revealed that first and second braces for Main loop were not matched (using ultraedit ctrl-B to match braces).  Adding two right braces at the end of the loop allowed all braces to match.

fakufaku, 2018-09-25:
Hi @dbgitter , thanks for pointing this out. This is very puzzling. Indeed, it seems if two braces are missing it shouldn't compile at all.

The confusion with the braces matching might be due to the large number of #if/#endif statements throughout the code.
I think the outer brace of the (Main) `loop` (line 611) is matched with the opening brace of the `for` loop line 453. However, the matching closing brace of this for loop is in fact on line 477. Within this `for` loop, the following piece of code
```
 460 #if ENABLE_SOFTGPS
 461     while (gpsSerial.available())
 462     {
 463       char c = gpsSerial.read();
 464 #else
 465     while (Serial.available())
 466     {
 467       char c = Serial.read();
 468 #endif
```
adds two opening braces, but only one of these is used at compile time due to the pre-compiler options. This might be what throws off the parenthesis matching algorithm of the text editor.

dbgitter, 2018-09-25:
Sorry, I’m not familiar with the details of conditional compile statements as used here, but I would think the braces should go in and out of the code in pairs.
And because no one really ever knows exactly how a compiler may be affected by errors this may cause a seemingly random error every once in a while when a block of code is added or removed.

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

robouden, 2018-09-25:
There is are some very long routines with if in there. If as Robin
mentioned the options are selected in the config file. It all should be
fine. Compiling would be stopped when it was not correctly close.

regards
rob

Regards,
Rob Oudendijk Yuka Hayashi
http://yr-design.biz   http://oudendijk.biz  http://about.me/robouden
tel +81 80-22605966  Skype: robouden  Facebook:robouden
<http://on.fb.me/QeKw2P> linkedin:robouden
<https://www.linkedin.com/in/roboudendijk>

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

fakufaku, 2018-09-25:
@dbgitter Sorry, I made a small terminology mistake, this is not a precompiler, but a preprocessor ("The" C preprocessor). It will parse the code and do some automatic modifications based on instructions starting with a `#` (`#define`, `#include`, etc). In the case of `#if`/`#else` statement, either set of instructions will be removed _prior_ to compilation. At compile time, all braces are thus matching in the above code statement.

As Rob emphasized, were some parenthesis missing, the compiler should fail with some error. Was it the case for you ?

The above code fragment provides evidence for one extra opening brace, and I'm pretty sure that if we look close enough, we can find the second one.

dbgitter, 2018-09-26:
Would appreciate any comments on the code snippet for the Main loop attached.  I placed closing comments on all the conditional statement blocks so they can be better understood.  Please have a look and let me know if any are incorrect.  Thanks.

[mainloopdbgitter.txt](https://github.com/Safecast/bGeigieNanoKit/files/2418293/mainloopdbgitter.txt)

dbgitter, 2018-09-26:
@robouden Attached is a snippet of the Main loop with closing comments added for all the conditional blocks.  Could you please have a look and comment on any that are wrong?  Thank you.
[mainloopdbgitter.txt](https://github.com/Safecast/bGeigieNanoKit/files/2418424/mainloopdbgitter.txt)

fakufaku, 2018-09-27:
@dbgitter That makes the code much easier to read! Thanks for doing that. I checked the file you provided and it seemed correct to me.

robouden, 2018-09-27:
@dbgitter thanks. Yes, much nicer. Good job!!

dbgitter, 2018-09-27:
@robouden @fakufaku   You are most welcome!  My original intent was to try to make a small version of the code to load into an Arduino NANO that I could program with the Arduino IDE so I could troubleshoot my bgeigie nano kit #3106.  The kit works and Safecast data was uploaded, but the display is intermittent.  Do either of you know who might be able to help with signal tracing?

robouden, 2018-09-27:
@bdgitter... I made much smaller versions with using ASCII only versions.
That leaves about 7K over and complies fine in Arduino IDE 1.8.5. It also
allows for full 128x64 use of the SSD1306. Also allows you to add other
sensors like gas/temp/humidity/shocks sensors etc.  Let me know me know if
you want to have the code.

regards
rob

Regards,
Rob Oudendijk Yuka Hayashi
http://yr-design.biz   http://oudendijk.biz  http://about.me/robouden
tel +81 80-22605966  Skype: robouden  Facebook:robouden
<http://on.fb.me/QeKw2P> linkedin:robouden
<https://www.linkedin.com/in/roboudendijk>

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

dbgitter, 2018-09-28:
@robouden Yes that would be very helpful to have a smaller scale set of software that works with the Arduino IDE.
Thank you.

Dan

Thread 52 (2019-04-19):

It doesn't work after a few hours of operation.

AshiChu, 2019-04-19:
A few hours worked nicely OLED displayed a record on MicroSD worked. Now, but the OLED does not display and LED flashes on the GPS module. And the red LED does not light on the main board with Atmel chip. Charging works and battery voltage is 3.8V when charging is disconnected.

hinner, 2019-04-19:
Is it any difference with or without SD-card? Is something written to
the card? Does the blue LED flash from time to time and ticking is
audible? GPS flashing LED does not mean anything special but tells you
there is no problem with DC. If there is something written to the
SD-card and the blue LED flashes, check OLED display connection. If not,
check processor soldering.

Happy easter

Kajetan
–
Dr. K. Hinner, Dr. Hinner GmbH, Kochelseestr. 11, D-81371 München,
St.-Nr: 143/130/60382
       --- Unternehmensberatung mit Schwerpunkt IT - IT-Sicherheit -
Datenrettung  ---
                 -- Handel mit EDV und -Teilen, Windows Server - Linux -
IT-Speziallösungen --
                 -  HR München, HRB 242301 Geschäftsführer: Dr. Kajetan
Harald Hinner -

Am 19.04.19 um 08:57 schrieb AshiChu:
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

AshiChu, 2019-04-20:
I desoldered apart the main board and the Arduino Fio board and the Arduino Fio board doesn't really react. The red LED is off only the orange LED is on when charging. I don't own FTDI serial converter so I ordered and try to do upgrade FW according to instructions. Maybe the Arduino Fio board will start working.

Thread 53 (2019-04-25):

Problems with my device

Lugulbanda, 2019-04-25:
hi i have issues with my device, last year i did the update, everything looks ok that time, then i got ill and as i was otw to my health center i tryed a few measurements, but all were very strange, first i regotniced the blue flash didnt appear and the green light also not appered, so i took out the SD Card reseted the device, and restarted it again, but with not much effort, i drove 5 hours, and collected 2k Data, wich cant be, i did a few measurements in the City i was in the hospital, but also not much measurments, today i traveled back and again i got nearly no measurments, and strangely a full measurement set from 10AM to 2 PM was completly missing, i have no idea whats wrong with my device but the issues make all measurements nearly meaningless..

Lugulbanda, 2019-04-25:
41495 | 2019/04/25 12:57 +0000 | Lugulbanda | 30030404.log | 16 | Processed (Not Approved) |   |  
41496 | 2019/04/25 12:58 +0000 | Lugulbanda | 30030410.log | 0 | Processed (Not Approved) |   |  
41497 | 2019/04/25 12:58 +0000 | Lugulbanda | 30030411.log | 8 | Processed (Not Approved) |   |  
41498 | 2019/04/25 12:59 +0000 | Lugulbanda | 30030412.log | 9 | Processed (Not Approved) |   |  
41499 | 2019/04/25 12:59 +0000 | Lugulbanda | 30030414.log | 164 | Processed (Not Approved) |   |  
41500 | 2019/04/25 13:00 +0000 | Lugulbanda | 30030416.log | 47 | Processed (Not Approved) |   |  
41501 | 2019/04/25 13:00 +0000 | Lugulbanda | 30030420.log | 297 | Processed (Not Approved) |   |  
41502 | 2019/04/25 13:01 +0000 | Lugulbanda | 30030424.log | 27 | Processed (Not Approved) |   |  
41503 | 2019/04/25 13:01 +0000 | Lugulbanda | 30030425.log | 129 | Processed (Not Approved)

the measurement 41495 was a 5 hour traindrive, and 41503 to

i had some issues in the past on my device to, but not that much since i upgraded the FW on it...

Lugulbanda, 2019-04-25:
i remember i saw in the past a blue flash from time to time on the sd card, atm tho only thing that flashes is the red counter LED, and from time to time the FIX LED on the GPS, but no longer the blue flash from the SD Card, the log alarm light comes sometimes and is mostly off, if i start the device, i see thr right green and blue led on the SD card flashing, and th GPS is blinking Red, if i remember the past the green log light was allways on, now its sometimes on mostly not and the blue light from the SD Card is allways off.

Lugulbanda, 2019-04-25:
FW Version 1.4.2 Bgeige Nano. cc by sa 3.0 b geige nano kit  v1.1r4a

Lugulbanda, 2019-04-28:
if i remember from the past the device has some issues if u drive with high speed and i think thats some issue with GPS and how u get the GPS Signal, some Messurements in Bad Kissingen were between higher Houses in small streets, but to see on both travels with the Train seeing nearly 5 measurement points, and a 5h Dataset with 2k size cant be...

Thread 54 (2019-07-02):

Read data live from serial/uart

Engineer-of-Stuff, 2019-07-02:
I'd like to read the data collected live via serial/uart instead of having to collect the SD card. Is this possible (maybe by modifying firmware)?

Engineer-of-Stuff, 2019-07-05:
Bump???

cw1812, 2020-09-02:
The function is already there. Look for Serial.print() or Serial.println()inside the main file bGeigieNano.ino you will see what will send.

robouden, 2020-09-02:
So you can install a bGiegieCast (soon tp be released [)](https://github.com/Safecast/bGeigieCast) or BLEBee and read the data thought BLEE, WiFI or both.

robouden, 2020-09-02:
[https://github.com/Safecast/bGeigieCast](https://github.com/Safecast/bGeigieCast)

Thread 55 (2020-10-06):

SAFECAST.TXT setting

cw1812, 2020-10-06:
Hi there,

Anyone can tell how to setup SAFECAST.TXT? tried google but no result.

Thanks.

nokton, 2020-10-07:
Below is the file format and explanation for the most relevant parameters. The definition should be on GitHub as well.

SAFECAST.TXT

==============
nm=NNNNNNN
did=XXXX
gt=0
gm=0
cpmf=334
cpmn=Cs137
bqmf=37
bqmn=Cs137
al=100
tz=9
cn=JPN
st=0
ss=0
sh=100
sm=0
cw=60
================

Nm - your name without a space - shows up when booting up
did - the device ID - should match the number on the bGeigie top plate

cpmf - conversion factor for CPM
cpmn - nuclide for cpm conversion factor
bqmf - conversion factor for Becquerel/cm2
Bqmn - nuclide for Becquerel conversion factor
al - level at which ALARM LED starts to blink (in CPM)

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

cw1812, 2020-10-26:
I know "al=100" is alarm level.

I can guess "tz=9" and "cn=JPN" refer to time zone.

But seems no reference to other setting...

robouden, 2020-11-02:
cw1812,

Sorry for the late reply. I had to dig into the source code to figure out myself what the other options are. Hereby the part of the code that "decode" the SAFECAST.TXT file. Check the DEBUG_PRINTLN statements in bold for the "cpmf" part of the file:

   _//
    // Process matching keys
    //
    if(strcmp(key, "**cpmf**") == 0) {
      // Update cpm factor
      float factor = atoi(value);
      if (mConfig.cpm_factor != factor) {
        mConfig.cpm_factor = factor;
        config_changed = true;
        DEBUG_PRINTLN("   **- Update cpm factor**");
      }
    }
    else if(strcmp(key, "bqmf") == 0) {
      // Update bq/m2 factor
      float factor = atoi(value);
      if (mConfig.bqm_factor != factor) {
        mConfig.bqm_factor = factor;
        config_changed = true;
        DEBUG_PRINTLN("   - Update bq/m2 factor");
      }
    }
    else if(strcmp(key, "nm") == 0) {
      // Update name in EEPROM
      if (strcmp(mConfig.user_name, value) != 0 ) {
        strcpy(mConfig.user_name, value);
        config_changed = true;
        DEBUG_PRINTLN("   - Update name in EEPROM");
      }
    }
    else if(strcmp(key, "did") == 0) {
      // Update device id in EEPROM
      if (mConfig.device_id != (unsigned int)atoi(value)) {
        mConfig.device_id = atoi(value);
        config_changed = true;
        DEBUG_PRINTLN("   - Update devide id in EEPROM");
      }
    }
    else if(strcmp(key, "gt") == 0) {
      // Update geiger type in EEPROM
      if (mConfig.type != atoi(value)) {
        mConfig.type = atoi(value);
        config_changed = true;
        DEBUG_PRINTLN("   - Update geiger type in EEPROM");
      }
    }
    else if(strcmp(key, "gm") == 0) {
      // Update geiger mode in EEPROM
      if (mConfig.mode != atoi(value)) {
        mConfig.mode = atoi(value);
        config_changed = true;
        DEBUG_PRINTLN("   - Update geiger mode in EEPROM");
      }
    }
    else if(strcmp(key, "al") == 0) {
      // Update alarm threshold in EEPROM
      if (mConfig.alarm_level != (unsigned int)atoi(value)) {
        mConfig.alarm_level = atoi(value);
        config_changed = true;
        DEBUG_PRINTLN("   - Update alarm threshold in EEPROM");
      }
    }
    else if(strcmp(key, "cn") == 0) {
      // Update country code in EEPROM
      value[3] = '\0'; // force 3 characters code
      if (strcmp(mConfig.country_code, value) != 0 ) {
        strcpy(mConfig.country_code, value);
        config_changed = true;
        DEBUG_PRINTLN("   - Update country code in EEPROM");
      }
    }
    else if(strcmp(key, "tz") == 0) {
      // Update timezone in EEPROM
      if (mConfig.timezone != atoi(value)) {
        mConfig.timezone = atoi(value);
        config_changed = true;
        DEBUG_PRINTLN("   - Update timezone in EEPROM");
      }
    }
    else if(strcmp(key, "st") == 0) {
      // Update sensor type in EEPROM
      if (mConfig.sensor_type != atoi(value)) {
        mConfig.sensor_type = atoi(value);
        config_changed = true;
        DEBUG_PRINTLN("   - Update sensor type in EEPROM");
      }
    }
    else if(strcmp(key, "ss") == 0) {
      // Update sensor shield in EEPROM
      if (mConfig.sensor_shield != atoi(value)) {
        mConfig.sensor_shield = atoi(value);
        config_changed = true;
        DEBUG_PRINTLN("   - Update sensor shield in EEPROM");
      }
    }
    else if(strcmp(key, "sh") == 0) {
      // Update sensor height in EEPROM
      if (mConfig.sensor_height != (unsigned int)atoi(value)) {
        mConfig.sensor_height = atoi(value);
        config_changed = true;
        DEBUG_PRINTLN("   - Update sensor height in EEPROM");
      }
    }
    else if(strcmp(key, "sm") == 0) {
      // Update sensor mode in EEPROM
      if (mConfig.sensor_mode != atoi(value)) {
        mConfig.sensor_mode = atoi(value);
        config_changed = true;
        DEBUG_PRINTLN("   - Update sensor mode in EEPROM");
      }
    }

regards,
Rob Oudendijk

robouden, 2020-11-02:
**cw1812,**

I took the code out and left the comments (much easier to read):

"cpmf"    "   - Update cpm factor"
"bqmf"    "   - Update bq/m2 factor"
"nm"      "   - Update name in EEPROM"
"did"     "   - Update devide id in EEPROM"
"gt"      "   - Update geiger type in EEPROM"
"gm"      "   - Update geiger mode in EEPROM"
"al"      "   - Update alarm threshold in EEPROM"
"cn"      "   - Update country code in EEPROM"
"tz"      "   - Update timezone in EEPROM"
"st"      "   - Update sensor type in EEPROM"
"ss"      "   - Update sensor shield in EEPROM"
"sh"      "   - Update sensor height in EEPROM"
"sm"      "   - Update sensor mode in EEPROM"
"dose"    "   - Reset total dose in EEPROM"

Closed 2021-02-05.

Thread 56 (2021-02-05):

Cannot compile

cw1812, 2021-02-05:
Cannot compile with arduino software. Here is the error:

Sketch uses 33942 bytes (110%) of program storage space. Maximum is 30720 bytes.text section exceeds available space in board

Global variables use 1317 bytes (64%) of dynamic memory, leaving 731 bytes for local variables. Maximum is 2048 bytes.
Sketch too big; see http://www.arduino.cc/en/Guide/Troubleshooting#size for tips on reducing it.
Error compiling for board Arduino Fio.

robouden, 2021-02-05:
Correct. Can not do that. You need to use the make file. Or use the branch I made for ACSII use only that is 11k smaller.[https://github.com/Safecast/bGeigieNanoKit/tree/ASCII_new]( https://github.com/Safecast/bGeigieNanoKit/tree/ASCII_new)

Or follow the guide in the read me.:

```
export ARDUINODIR=/home/geigie/arduino-1.0.1/
export SERIALDEV=/dev/ttyUSB0
export BOARD=fio
cp -r libraries /home/geigie/arduino-1.0.1/
make
make upload
```

cw1812, 2021-02-05:
Hi robouden,

The ASCII_new work for me.

Thanks for your effort!

robouden, 2021-02-05:
But the display is not "standard" if you flash the file to the bGeigieNano.

robouden, 2021-02-05:
The ASCII new version is a work in progress to ad shock sensor for bGeigeiCast dimming of the display.

Closed 2021-02-05.

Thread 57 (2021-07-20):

Compling on Mac BigSur and Windows 10

robouden, 2021-07-20:
It seems our software repo is a way of alignment of the current versions of the most used OS's.
We need to fix this if we want other developers to work with the repo.

dittohead, 2024-02-17:
@robouden
faced with issue, that can't build FW with arduino 1.0.1, coz it not support in Macos 10.4
will try some refactoring for able to work with modern version (1.8)

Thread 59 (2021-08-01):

bGeigie Nano 1.4.3 not locking GPS

pawelngei, 2021-08-01:
I just bought and assembled a bGeigie Nano kit following [the assembly manual](https://github.com/Safecast/bGeigieNanoKit/wiki/Assembly-Manual) and flashed it with 1.4.3 firmware (last version from 8 days ago). I ran the [power on test](https://github.com/Safecast/bGeigieNanoKit/wiki/Assembly-Manual#power-on-test) successfully.

After installing the tube and inserting the SD card I can't get the GPS to lock to any satellite. I left the bGeigie outside for 20 minutes - nothing, in any of the modes. Tried resetting the GPS a few times (by removing the SD card), to no avail. Copied the SD configs from [this repo](https://github.com/Safecast/bGeigieNanoKit/tree/master/SD%20card), no change.

The red FIX LED on the GPS module keeps blinking. All the other functions seem to work properly.

What is the proper way to debug it? Is it possible to re-flash the GPS firmware?

jamoross, 2021-08-01:
Hello -

If the red LED on the GPS unit is blinking slowly (1sec on, 1sec off) then
it is in acquisition mode and should eventually get a location fix.  The
parameter settings the bGeigie sends it after a reset control how it
communicates and saves its place for a “warm start”.  After reset, or just
not being turned on for many days, it must do a “cold start” and needs a
wide clear view of the sky.

It’s possible an external antenna would help it get an initial fix, but
that’s not necessary.   I would put it outside in a wide open space, on a
roof if in a city, and let it sit. The bGeigie should not be in log mode
(put the mode switch up).

It’s also possible you have a defective GPS module but it would be the
first.  I’ve seen bad displays, FIOs, and plenty of bad logger modules, but
not a GPS.  Always a first time I guess…

If there is a Bluetooth module, remove it until the GPS gets a first fix.
Also make sure there are no SD card errors as that can cause the main
processor to repeatedly reset the GPS controller.

Let me know how it goes.

- jam

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

pawelngei, 2021-08-01:
Thanks a lot @jamoross !

Once I set it to the Surface Mode (up), the GPS no longer blinks every few seconds, but the LOG red LED on the motherboard does. A short video:

https://user-images.githubusercontent.com/4021653/127784926-784e3614-7b9a-4353-9815-8467882aede6.mp4

Is this normal for the device?

jamoross, 2021-08-01:
No, that is definitely not normal.  It looks like the FIO is constantly
resetting itself. I’d check all your connections looking for “cold” solder
joints and inadvertent bridges.

I’m also worried that the component leads weren’t trimmed short enough on
the back of the main board and something is shorting out.

- jam

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

pawelngei, 2021-08-02:
Thank you @jamoross !

How can I know FIO is resetting? Is the red light indicating a restart? Blinking of the other components?

I cut all the components leads, re-soldered one resistor and it's not blinking as often. I'll keep it on today and see if it'll find a satellite.

In the Surface mode, is the second line supposed to be blinking constantly?

Short vids of my today's down mode:

https://user-images.githubusercontent.com/4021653/127841227-9306ece1-f0d8-4965-9098-6e87d5232f93.mp4

And up mode:

https://user-images.githubusercontent.com/4021653/127841278-253fa072-2b34-420e-837f-3f27203ba581.mp4

pawelngei, 2021-08-02:
(the screen flickering above is caused by the camera, the screen looks okay to the human eye).

Another interesting thing I noticed: In LOG mode, each "minute" is counted each 2-3 seconds, so after 3 hours it's showing about 60h.

pawelngei, 2021-08-02:
Looking at https://youtu.be/AgJoYGkN70E?t=50 , in the Surface mode the second line on the display changes every few seconds, while in my hardware it keeps flickering. Is the hardware clock broken? Is it a firmware issue?

https://user-images.githubusercontent.com/4021653/127909667-84c2b563-3e47-4c72-a2b2-dffdce0376ae.mp4

robouden, 2021-08-03:
Seeing the flicking, and the time issues with logging I am wondering what firmware did you use? Did you compile by yourself the code from a few days ago?

Regards,
Rob

pawelngei, 2021-08-03:
Thanks @robouden ! I used the .hex available in Github from this commit: https://github.com/Safecast/bGeigieNanoKit/commit/69b7a3aa9df2c30b8ecb55c01f806e7af7c3ccef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

Should I compile it myself, or try the new .hex from yesterday?

pawelngei, 2021-08-03:
Update: it looks like flashing the new firmware 1.4.4 fixed the issue. The screen no longer flickers and the GPS works correctly. The only issue is that switching between modes takes a few seconds.

robouden, 2021-08-03:
Happy V1.4.4 works. You seem to be the first one to use it.
Switching mode is delay is "normal". Due to the 5 seconds updates on the main code.

Regards,
Rob

robouden, 2021-08-03:
> Update: it looks like flashing the new firmware 1.4.4 fixed the issue. The screen no longer flickers and the GPS works correctly. The only issue is that switching between modes takes a few seconds.

You used this hex?https://github.com/Safecast/bGeigieNanoKit/blob/master/.pio/build/fio/firmware.hex

pawelngei, 2021-08-03:
@robouden correct! It might be that the previous one was flashed wrong too, not necessarily broken.

I just completed a walk with this one and the log seems to be correct.

pawelngei, 2021-08-03:
I just submitted my first set of coordinates at https://api.safecast.org/en-US/bgeigie_imports/52867 ! Thank you all for the help!

For all the future visitors in this thread, what I learned:

- If the GPS doesn't lock in after half an hour, something is probably wrong.
- The bGeigie Surface Mode second line is not supposed to flicker. Check the time in the Logging mode, it might mean that it's off.
- Firmware 1.4.3 might potentially not work on some devices / I might have flashed it wrong.
- Upgrading to 1.4.4 helped me
- I upgraded from https://github.com/Safecast/bGeigieNanoKit/blob/master/.pio/build/fio/firmware.hex file with a command `avrdude -DV -p atmega328p -P /dev/ttyUSB0 -c arduino -b 57600 -U flash:w:firmware.hex:i` (please remember to download the raw HEX file, not the html with it).
- The bottom of the bent connectors used to program Arduino Fio should be cut so that they don't touch the motherboard
- The 3-5s lag when switching between Logging and Surface mode is normal
- If the GPS works but you can't see any radiation readings, check the iRover connection as per [this image](https://raw.githubusercontent.com/Safecast/bGeigieNanoKit/master/nano%20manual%20named%20pics/manual%20update%20Aug%202018%20small%20JPEG%20selects/016-TripleConnect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).

I think with that, we can close the issue

hinner, 2021-08-04:
Thank you for this summary!

All the best,

Kajetan

Am 03.08.21 um 23:13 schrieb Paweł Ngei:
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

Closed 2021-08-03.

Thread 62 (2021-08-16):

Problema con GPS

kevinangulo99, 2021-08-16:
Buenas noches, tengo problema al iniciar el interfaz, conecto la sd, prendo el dispositivo pero no me reconoce el GPS, lo dejo un tiempo pero no registra, adjunto imagen del error.
Si me pueden brindar alguna ayuda o solución lo agradezco.
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

nokton, 2021-08-16:
Hi Kevin,

Can you start the bGeigie while there’s no SD card inserted. You should see a message “GPS Reset” - please wait for a minute. Them switch off, insert SD card and go outside. Switch on and wait till you get a GPS lock - it may take unto 20-30 min depending on location, weather, time and access to open sky.

Let us know if that solved the problem.

Best,
Pieter

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

kevinangulo99, 2021-08-18:
Thank you very much, the problem is solved.

nokton, 2021-08-18:
That’s great and we look forward to see your measurements come in on api.safecast.org!

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

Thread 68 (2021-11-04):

connect safecas with internet

kevinangulo99, 2021-11-04:
Hello, my name is Kevin Angulo, I am a co-investigator of a project of sensing radiation in Antarctica with a safecast nano kit device.
We are trying to make an internet connection to this sensor, and we are trying to do it by replacing the Xbee Bluetooth, by an Xbee wifi, which already has, however, we have not been able to interpret the code of the safe to modify it and make the connection to the web page that we are also creating to make this scientific station.
I would be very grateful for any hint or support to be able to complete this mission, since the scientific station that is going to be made should be ready by the end of this month and it has not been possible to be concretized.
Thank you very much for your attention, I remain attentive to the answer.

robouden, 2021-11-05:
Hi Kevin,

Think what you need is a  [bGeigieCast ](https://github.com/Safecast/bGeigieCas).
Soon to be released. If you need one in a hurry I can build one for you.

Regards,
Rob Oudendijk

kevinangulo99, 2021-11-11:
Great, I'm interested, I have the bGeigie Nano, I do not know if you can make an improvement to this that I already have or an update to make it a little faster, if you want to share me your WhatsApp number to talk a little better, or I share mine for better communication and to define something.
My WhatsApp number is ((+57) 320 240 0661) I look forward to your response thank you very much.

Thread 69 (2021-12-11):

Request detail specification for Small Part

vin89423, 2021-12-11:
I am looking for small parts from my local market but I am little bit confused.

- Resistors, there is multiple size of resistors with the same ohm. May I confirm that it is 1/4W resistor.

- Capacitors, I find there is 50V, 100V and 500V of 100nF Ceramic Capacitor, I cannot find any detail specification in project wiki. May I know the correct Volt used on this project.

Many thanks.

Closed 2021-12-14.

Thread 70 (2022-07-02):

Question: where can I buy bgeigie nano?

margre8, 2022-07-02:
Dear Safecast developers,

I would like to buy the Safecast bgeigie nano kit but when I try to look at kithub shop I am constantly unable to connect with the server and it looks like the shop does not work. Is the shipping of the kit suspended or is there some other way?

Thank you for help

robouden, 2022-07-03:
Dear Magre8,

- Are you in  a hurry to get one?
- We could offer a bGeigieZen that is already build by me, and working correctly for measurements and for creating bGeigieNano  compatible  log file. (still very beta), but much more modern and flexible to work with and off it at about the same price as bGeigieNano as mentioned on GitHub. You may need to update the firmware later to get the updates. But that should be very easy. Just a USC C cable and one file, More information at [](https://bgeigiezen.safecast.jp/). Website for bGeigieZen is also still in development.
- Let me know what you want to do.

Regards,
Rob Oudendijk

margre8, 2022-07-03:
@robouden I appreciate your offer, but I am not currently hurry to get one because I have one device borrowed. May I contact you later if I would buy bGeigieZen?
I would like to ask you, am I understand that the bGeigieZen will replace the bGeigie nano and this is the reason why bGeigie nano is not for sale?

Thank you for your Willingness

robouden, 2022-07-03:
You can contact me anytime.

The reason that the bGeigieNanokit is not available is that the parts are hard to get these days. And also Kithub stopped completely. Owner closed it.

Yes, bGeigieZen will replace the bGeigieNano.

Regards,
rob Oudendijk

margre8, 2022-07-03:
Thank you for answer, if I would like to contact you regarding bGeigieZen should I use another GitHub issue, or via Safecast website?

robouden, 2022-07-03:
You can contact me through any of my emails.

Regards,
Rob

Regards,
Rob Oudendijk Yuka Hayashi
https://yr-design.biz <http://yr-design.biz/>   https://oudendijk.biz
<http://oudendijk.biz/>  https://about.me/robouden
<http://about.me/robouden>
tel +81 80-22605966  Skype: robouden  Facebook:robouden
<http://on.fb.me/QeKw2P> linkedin:robouden
<https://www.linkedin.com/in/roboudendijk>

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

Closed 2023-08-23.

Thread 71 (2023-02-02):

http://nano.safecast.org/ is down

abitrolly, 2023-02-02:
Link http://nano.safecast.org/ that is written in repository description doesn't work anymore.

robouden, 2023-02-02:
Thanks for noting it. Now it is fixed.

abitrolly, 2023-02-02:
Still down for me. Maybe needs some time to update.

robouden, 2023-02-02:
That site is not there anymore. A new link is in the description now.[Click here](https://safecast.org/devices/bgeigie-nano/)

abitrolly, 2023-02-02:
Oh. I see now. Then it is fixed. )

Closed 2023-02-02.

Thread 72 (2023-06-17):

Mac App not working

cw1812, 2023-06-17:
Hi there,

Is there any advice for the "Bad CPU type in executable" error?

Thanks.
____________________________________________________________________________________________________
TERM environment variable not set.
Safecast

Firmware Uploader Mac

The following is a list of the available serial ports:

1. /dev/tty.usbserial-AQ00PL19

One relevant port so selecting it automatically : /dev/tty.usbserial-AQ00PL19
1. firmware.hex
TERM environment variable not set.
Safecast firmware Updater

Writing - firmware.hex
to port - /dev/tty.usbserial-AQ00PL19
IC      - atmega328p

/private/var/folders/f1/4br1j83n78l1r1rtpck4gyrc0000gn/T/AppTranslocation/07ADACCA-1224-4FA2-B575-8EE18E49CE57/d/bGeigeiNano_V1.4.5_uploader.app/Contents/Resources/script: line 175: /private/var/folders/f1/4br1j83n78l1r1rtpck4gyrc0000gn/T/AppTranslocation/07ADACCA-1224-4FA2-B575-8EE18E49CE57/d/bGeigeiNano_V1.4.5_uploader.app/Contents/Resources/bin/avrdude: Bad CPU type in executable

____________________________________________________________________________________________________

robouden, 2023-06-17:
Hi,

What Mac OSX version?

Regards,
rob Oudendijk

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

dittohead, 2024-02-15:
got same on 14.2.1 intel

robouden, 2024-02-15:
ditohead,

Seems you are using an older version (32 bit only) of the uploader script.  Can you try the V1,4,5 uploader for Mac? That should be 64 bit.

Regards,
Rob

dittohead, 2024-02-16:
thats for 1.4.5
I pull `Resources` folder and replace avrdude, with fresh one, but now got problem with
```
avrdude: stk500_recv(): programmer is not responding
avrdude: stk500_getsync() attempt 1 of 10: not in sync: resp=0x00
```

robouden, 2024-02-16:
Arsen,

You do seem to understand a bit about programming.
Can you try to extract the binary and use avrdude to flash the Nano?

Regards
Rob Oudendijk

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

dittohead, 2024-02-16:
@robouden

I just try to start avrdude from 1.4.5 uploader, but receive

```
bad CPU type in executable: ./avrdude
```

Quick googling says, that for ARM macbooks need to be install Rosetta2, but for Intel this is solution is not suitable.
Quick way to fix:
1. Unpack 1.4.5 uploader
2. `cd ./Resources/bin`
3. Put into `/bin` fresh `avrdude` and `avrdude.conf` (I take from Arduino app v6.3, trying using v7.3 from brew , but it don't have config for arduino programmer in `avrdude.conf`, and config from 1.4.5 uploader not suitable for 7.3)
4. `cd ..`
5. `chmod +x script`
6. `./script`
...
Voila!

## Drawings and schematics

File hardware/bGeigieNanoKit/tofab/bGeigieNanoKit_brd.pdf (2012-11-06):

ON

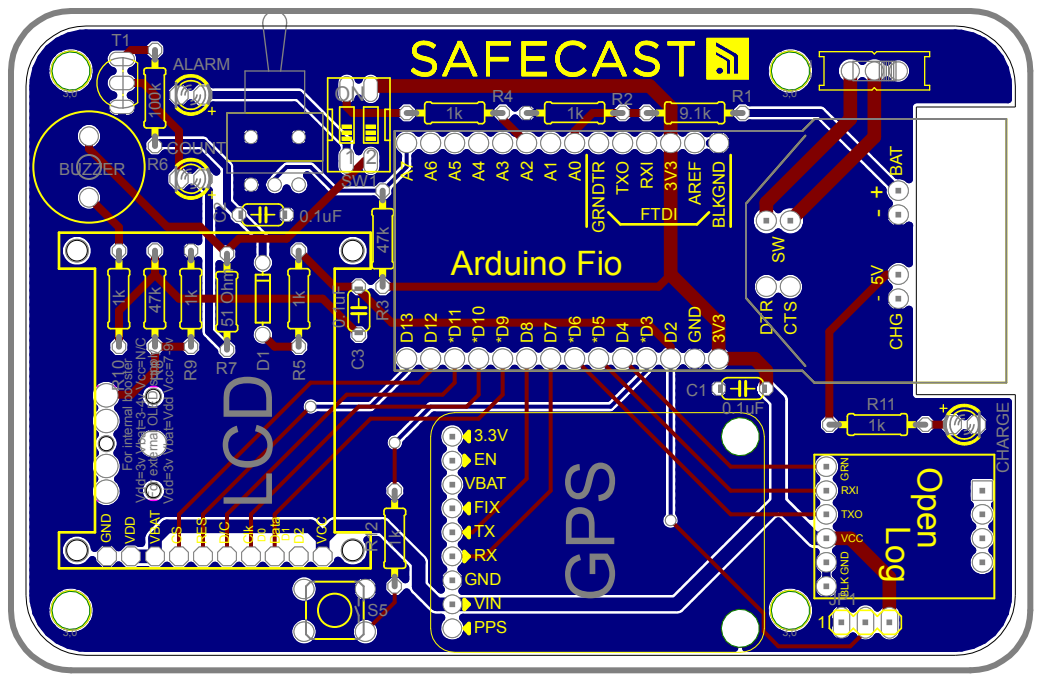
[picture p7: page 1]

Vdd=3v Vbat=Vdd Vcc=7-9v

For external OLED supply

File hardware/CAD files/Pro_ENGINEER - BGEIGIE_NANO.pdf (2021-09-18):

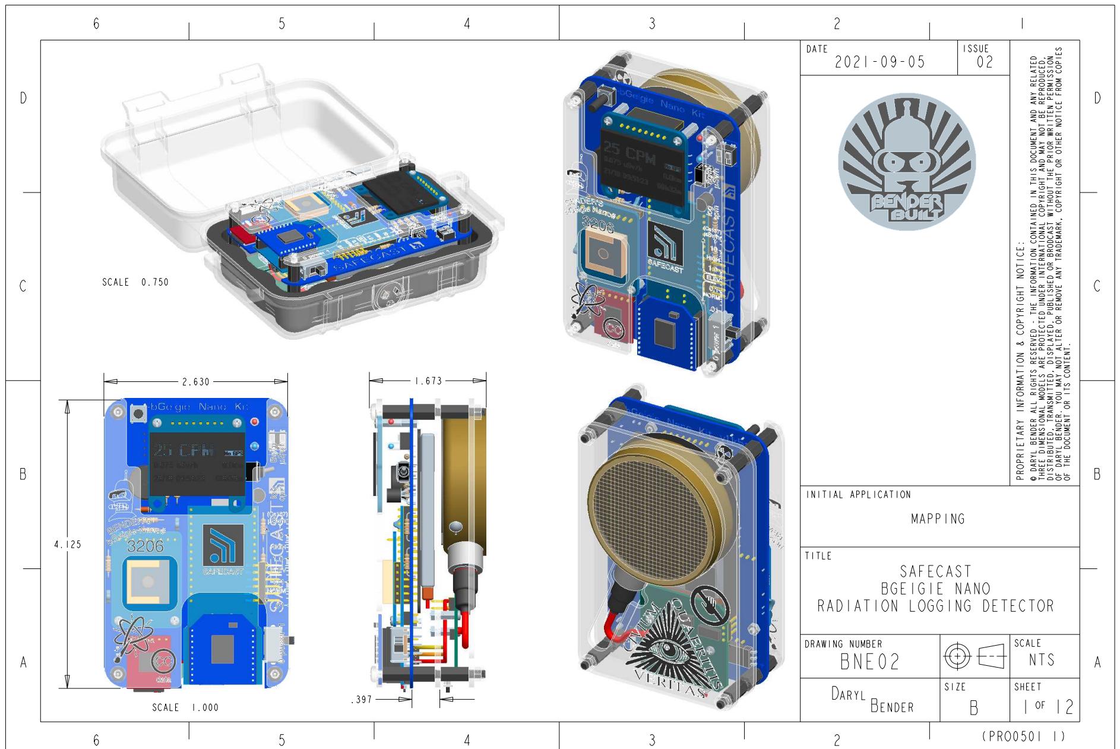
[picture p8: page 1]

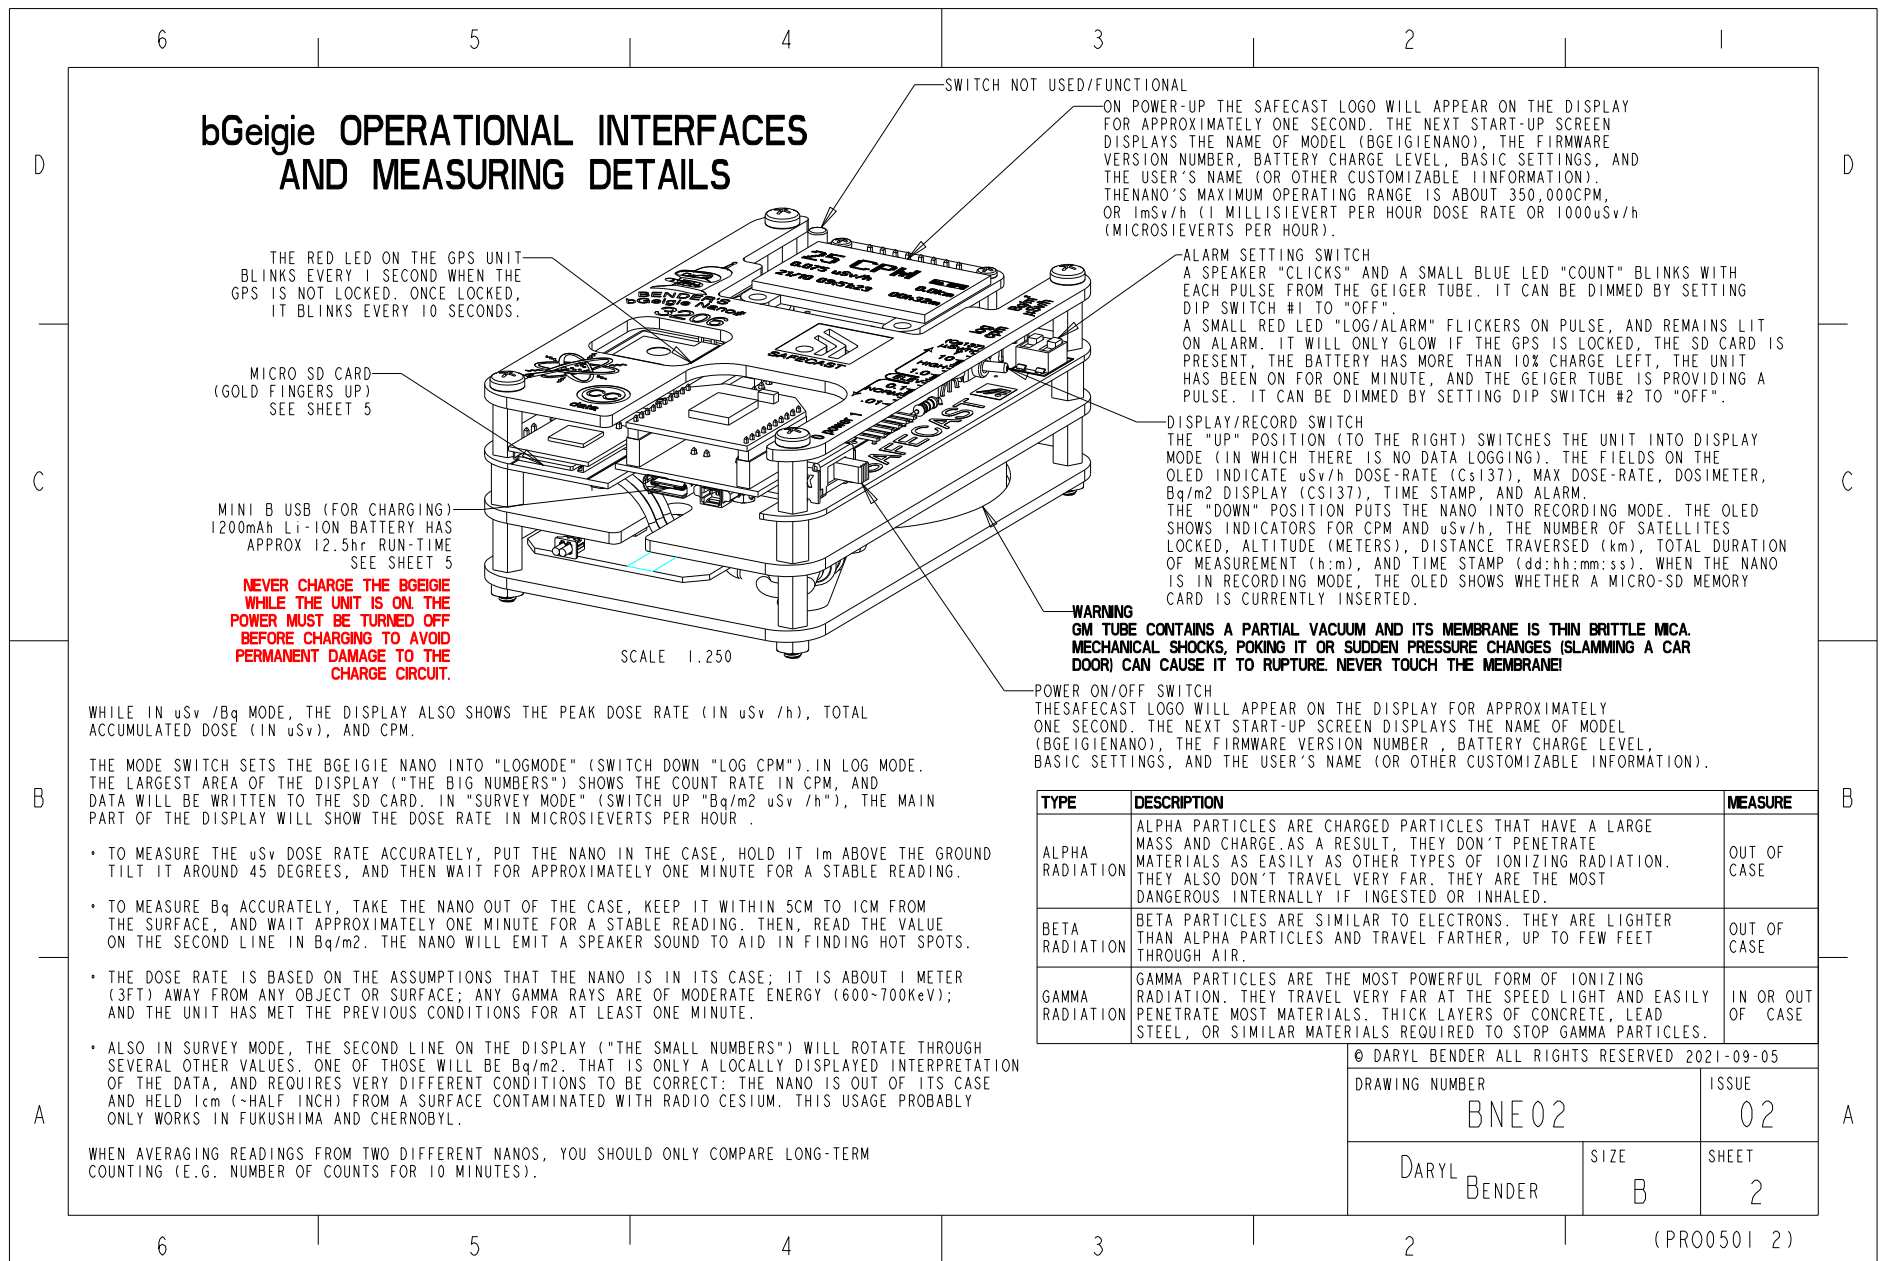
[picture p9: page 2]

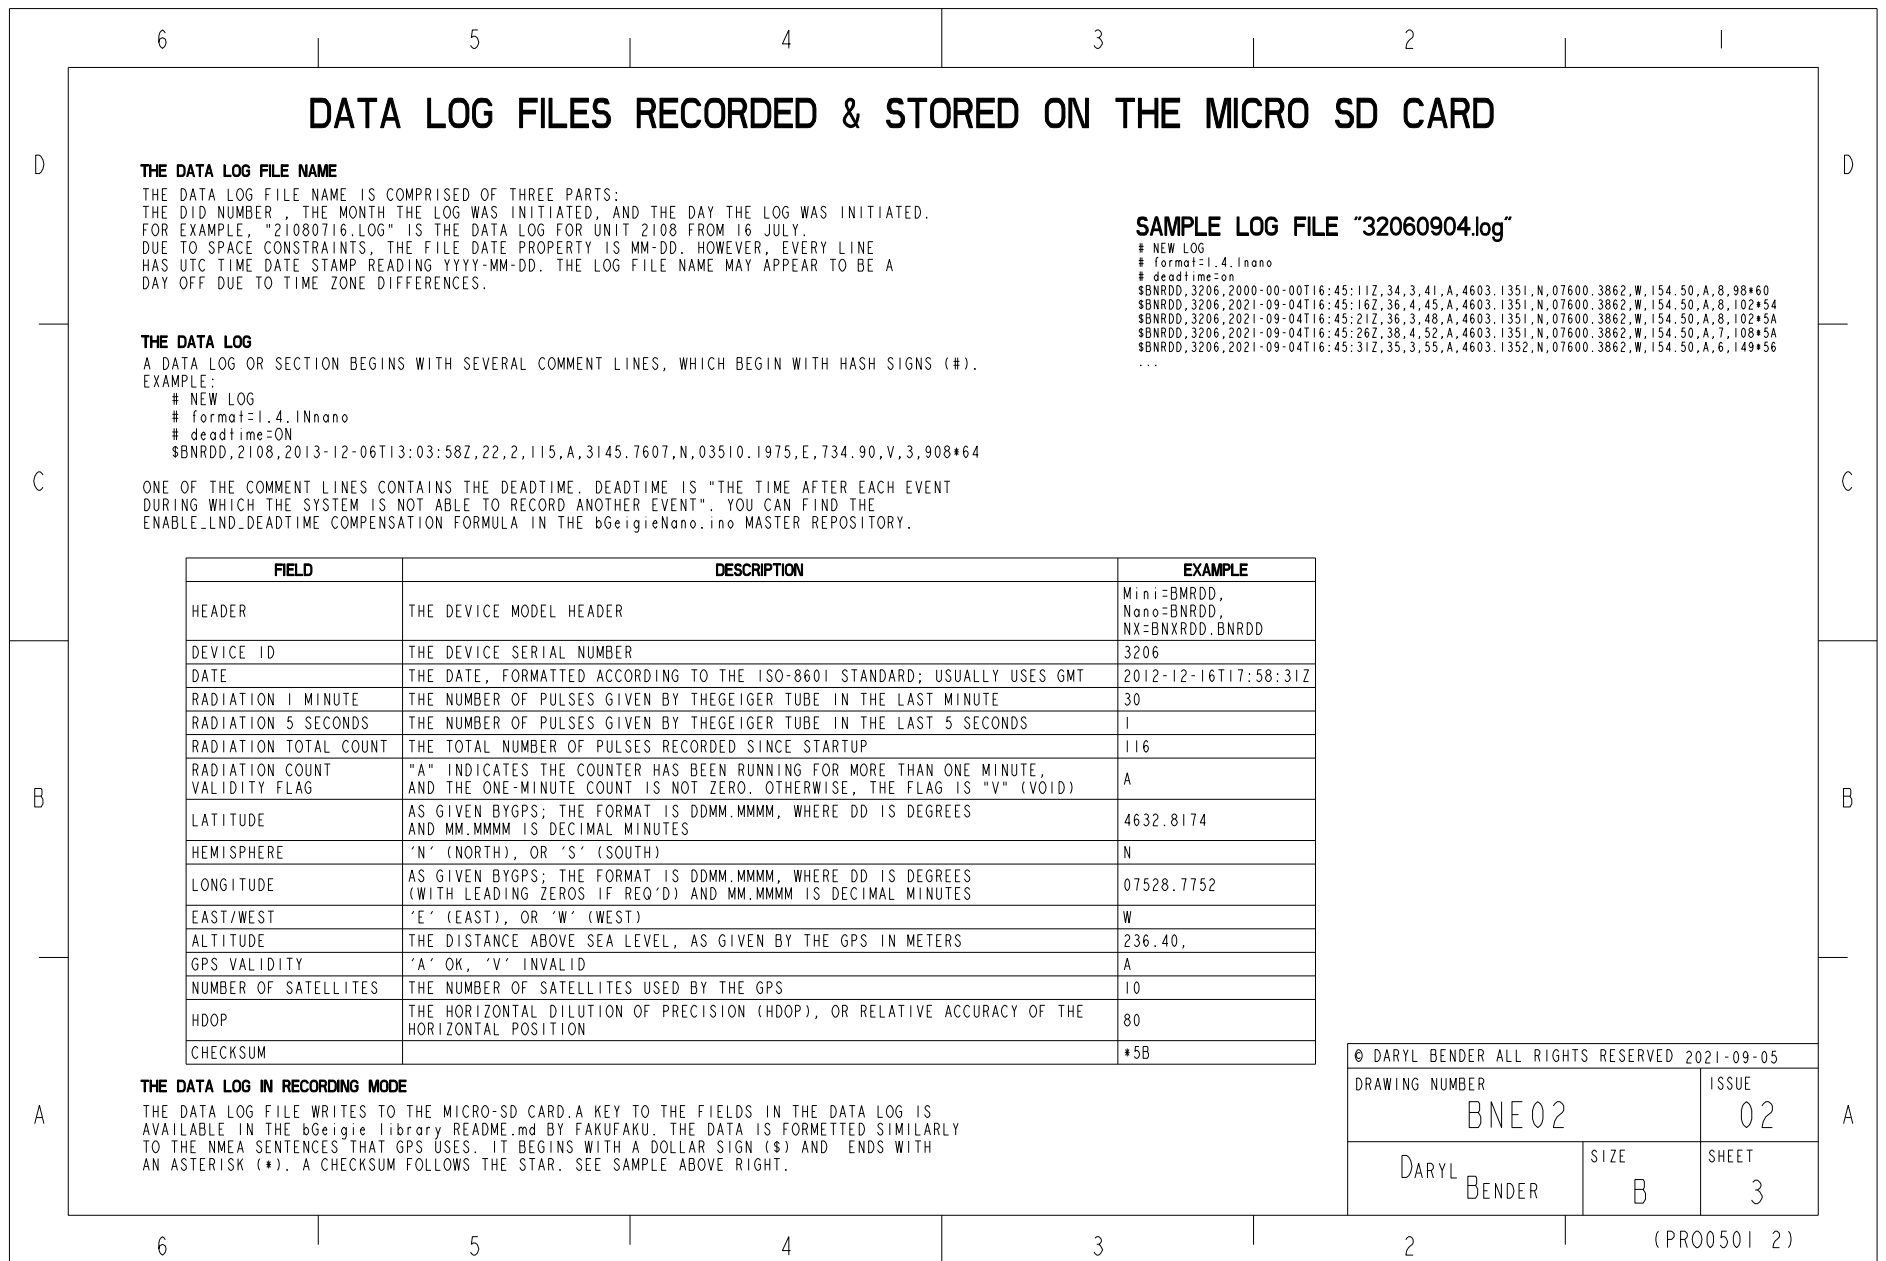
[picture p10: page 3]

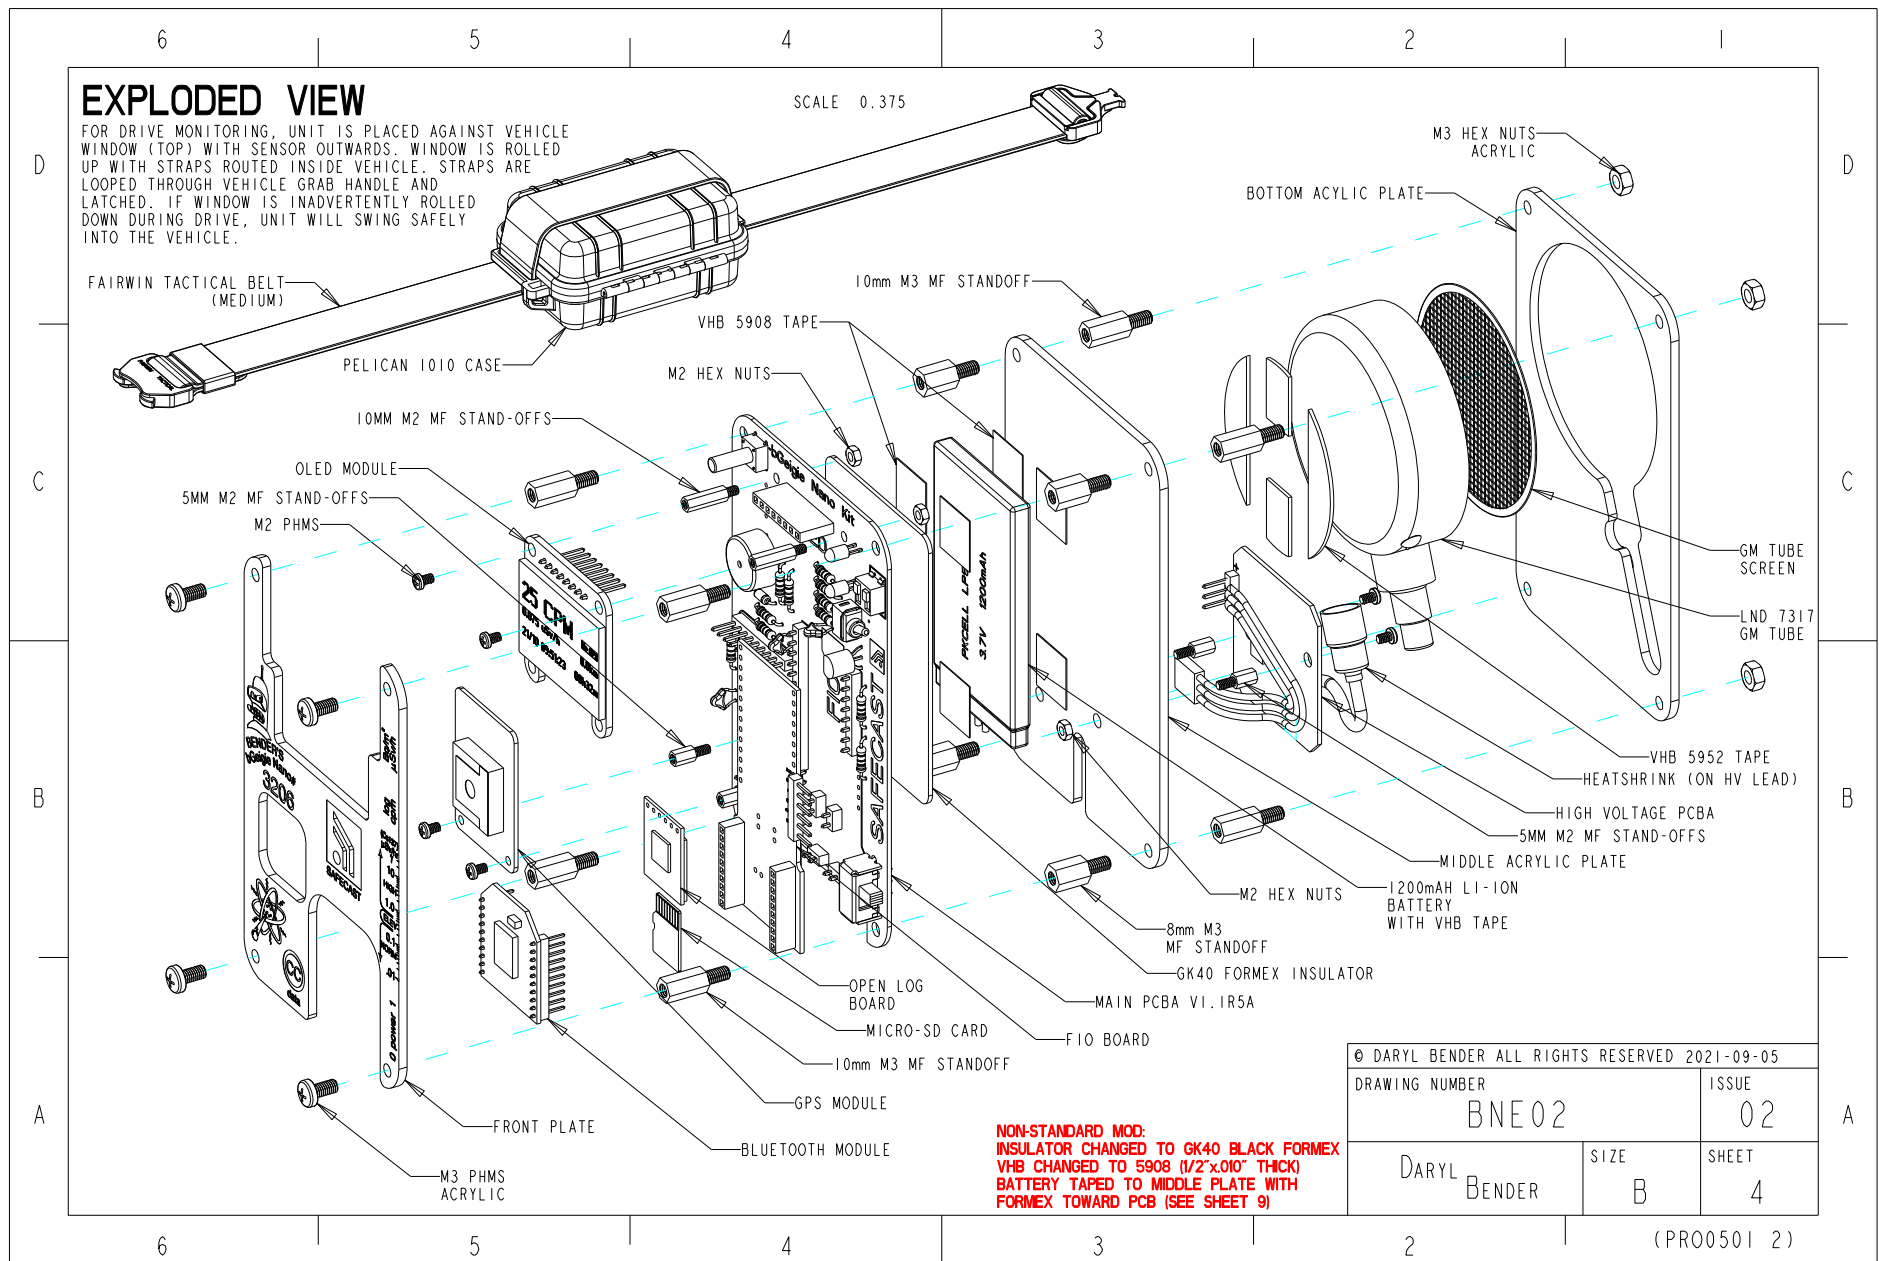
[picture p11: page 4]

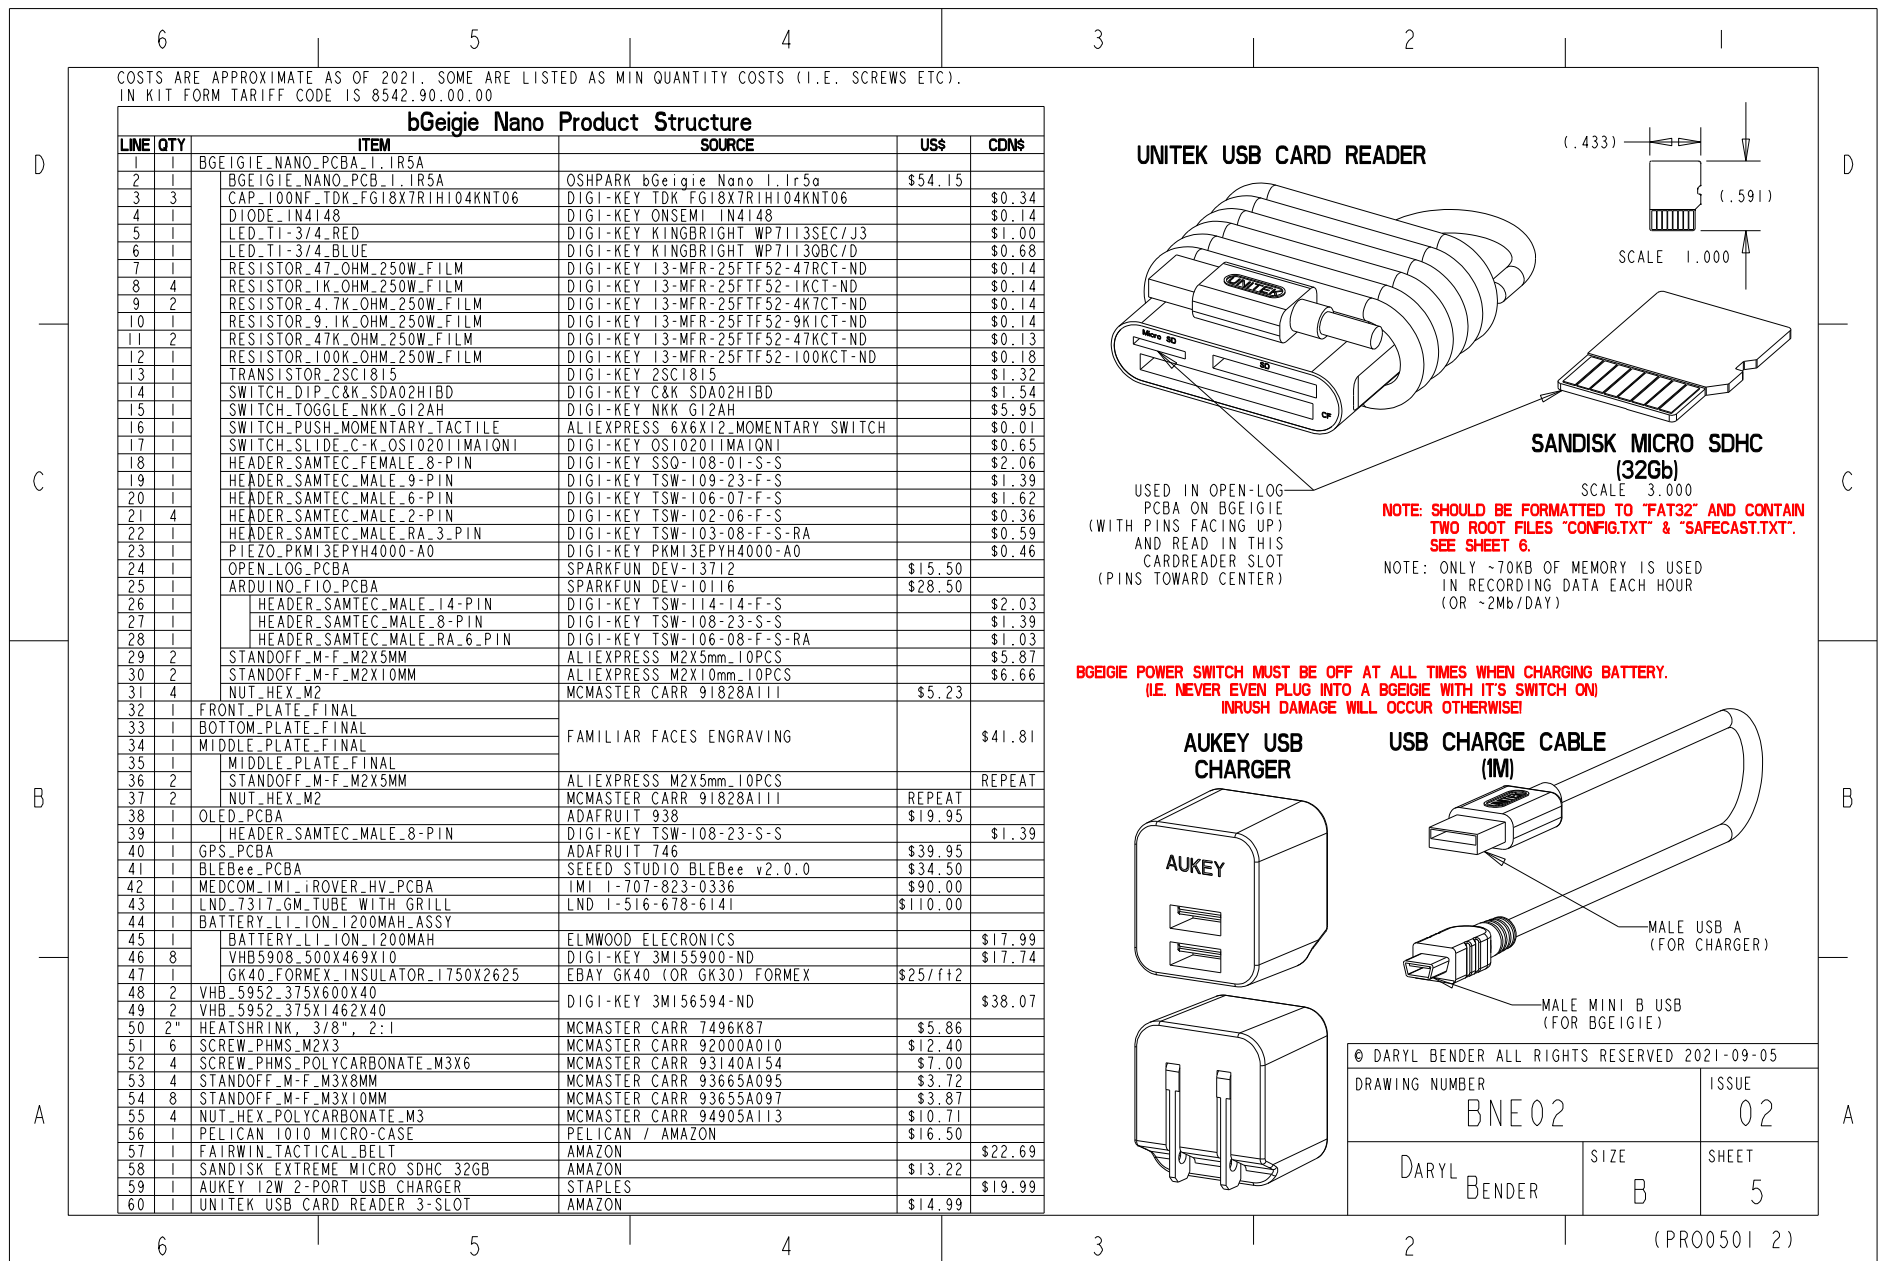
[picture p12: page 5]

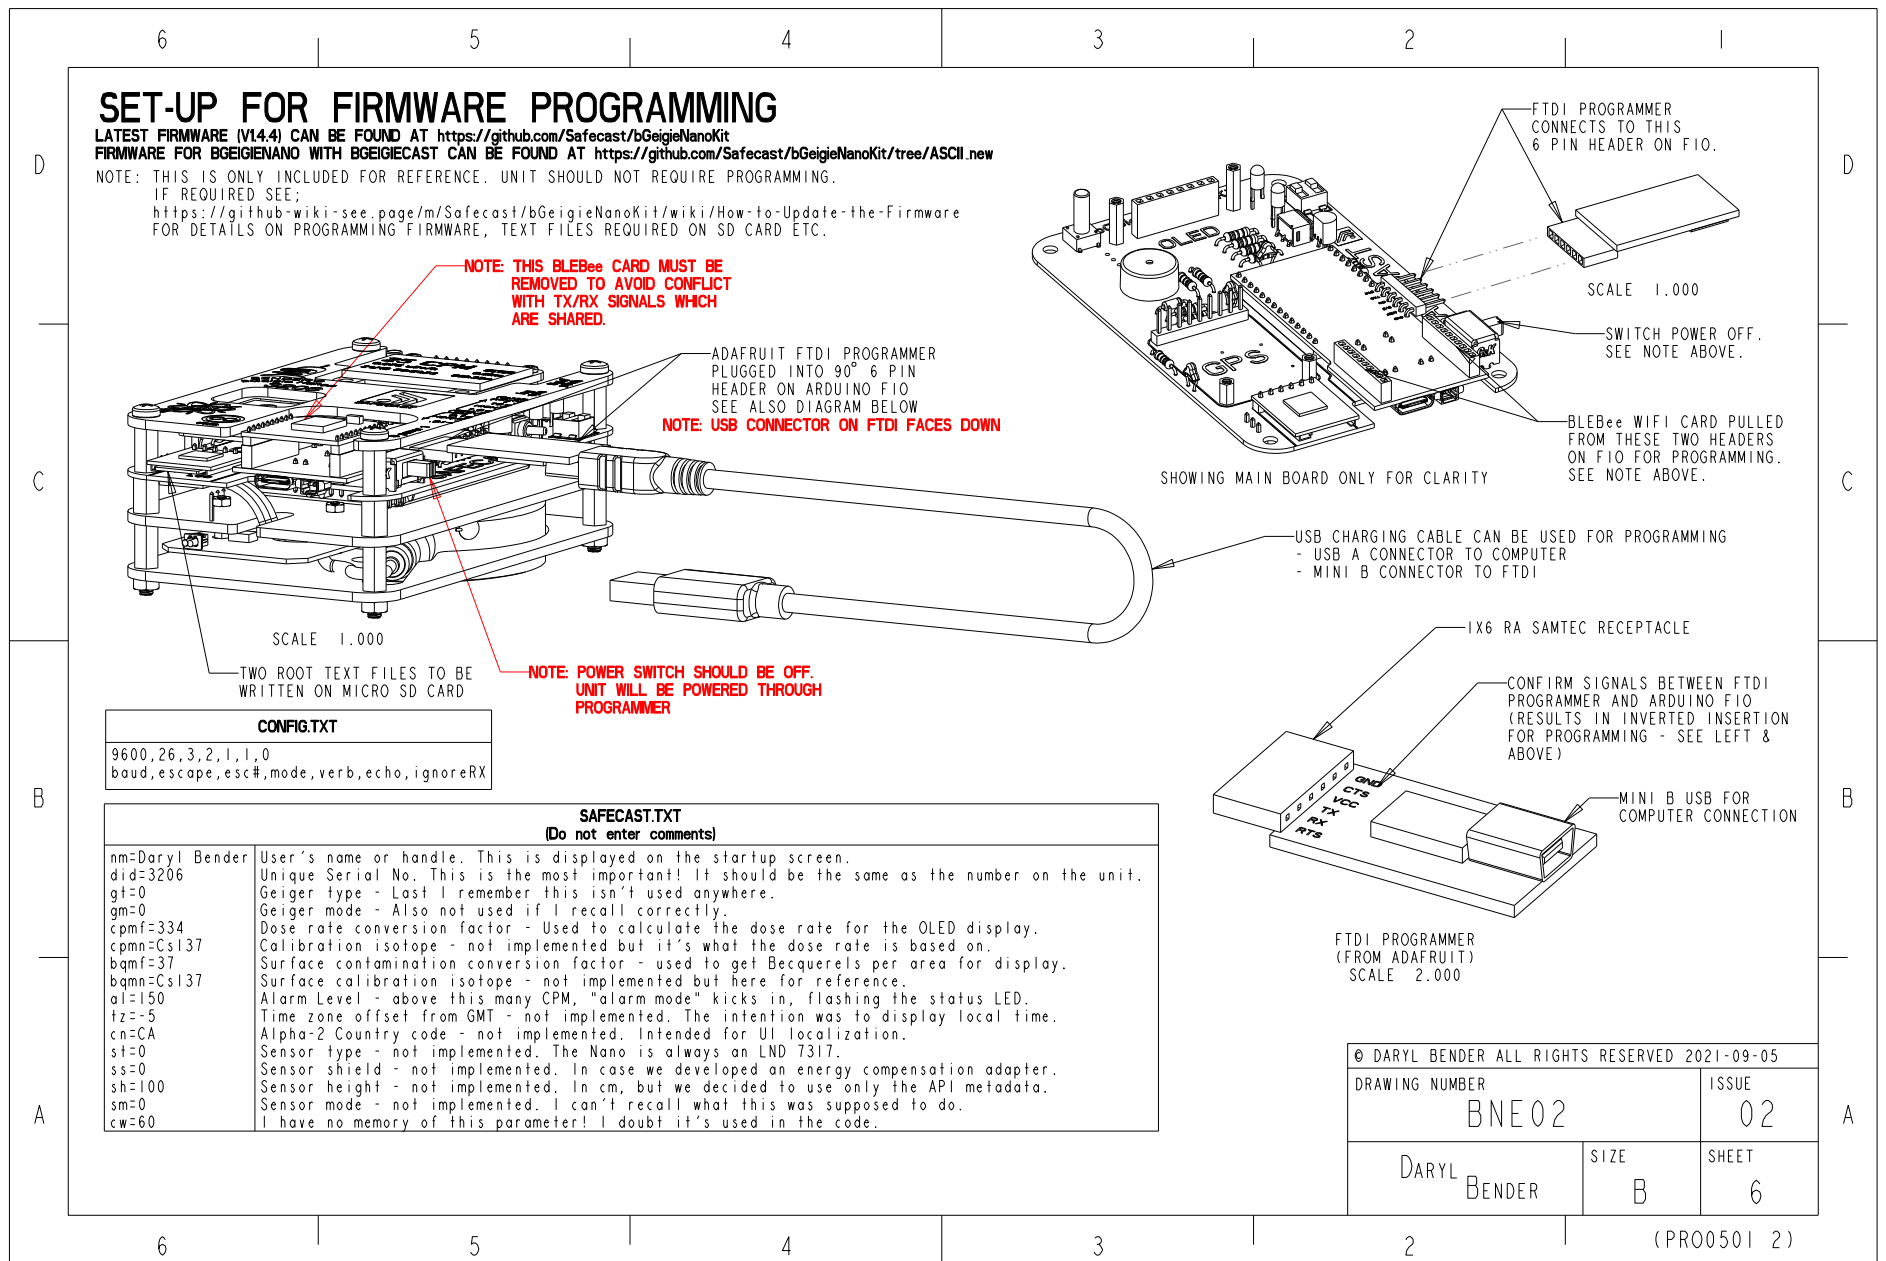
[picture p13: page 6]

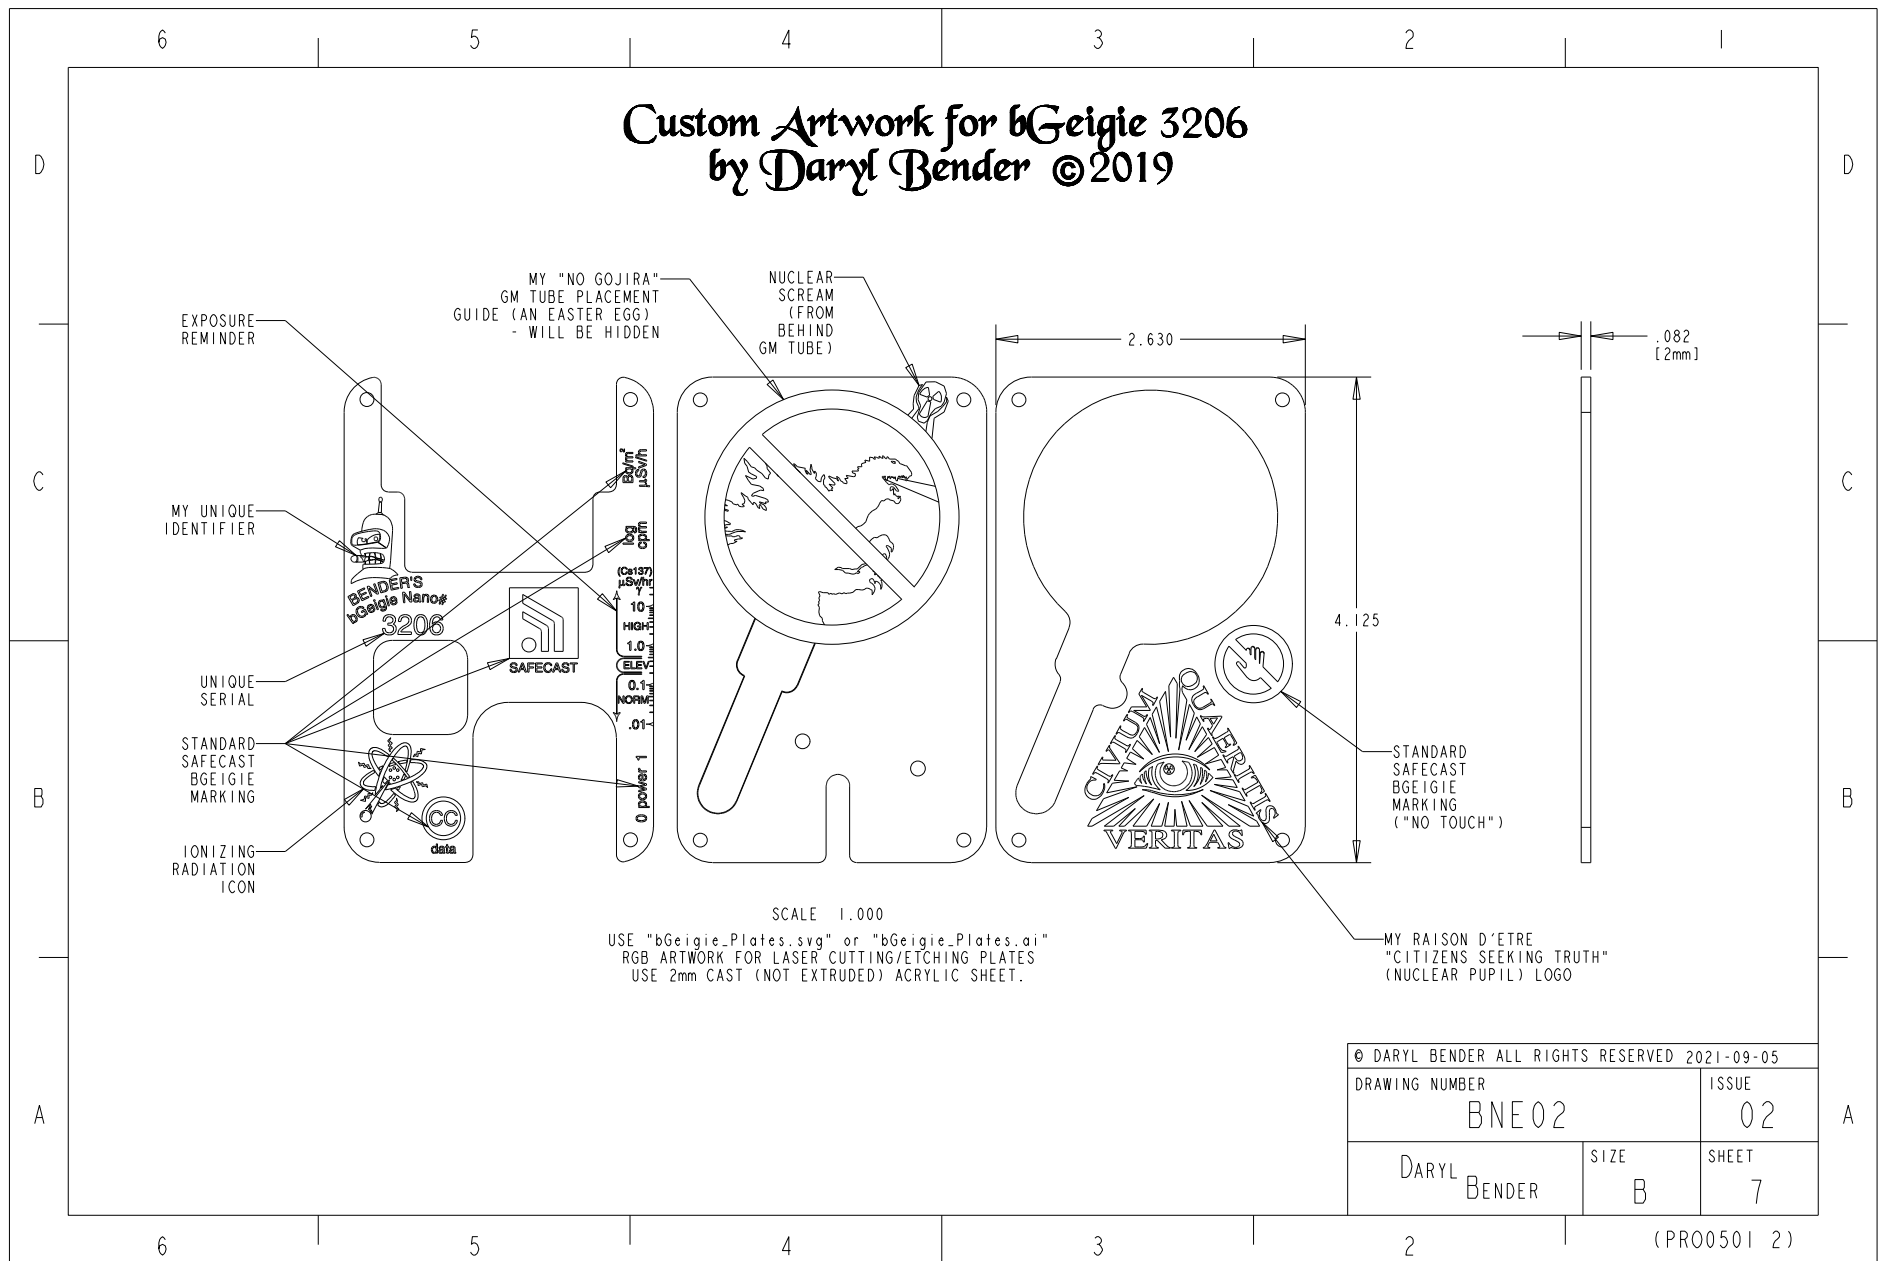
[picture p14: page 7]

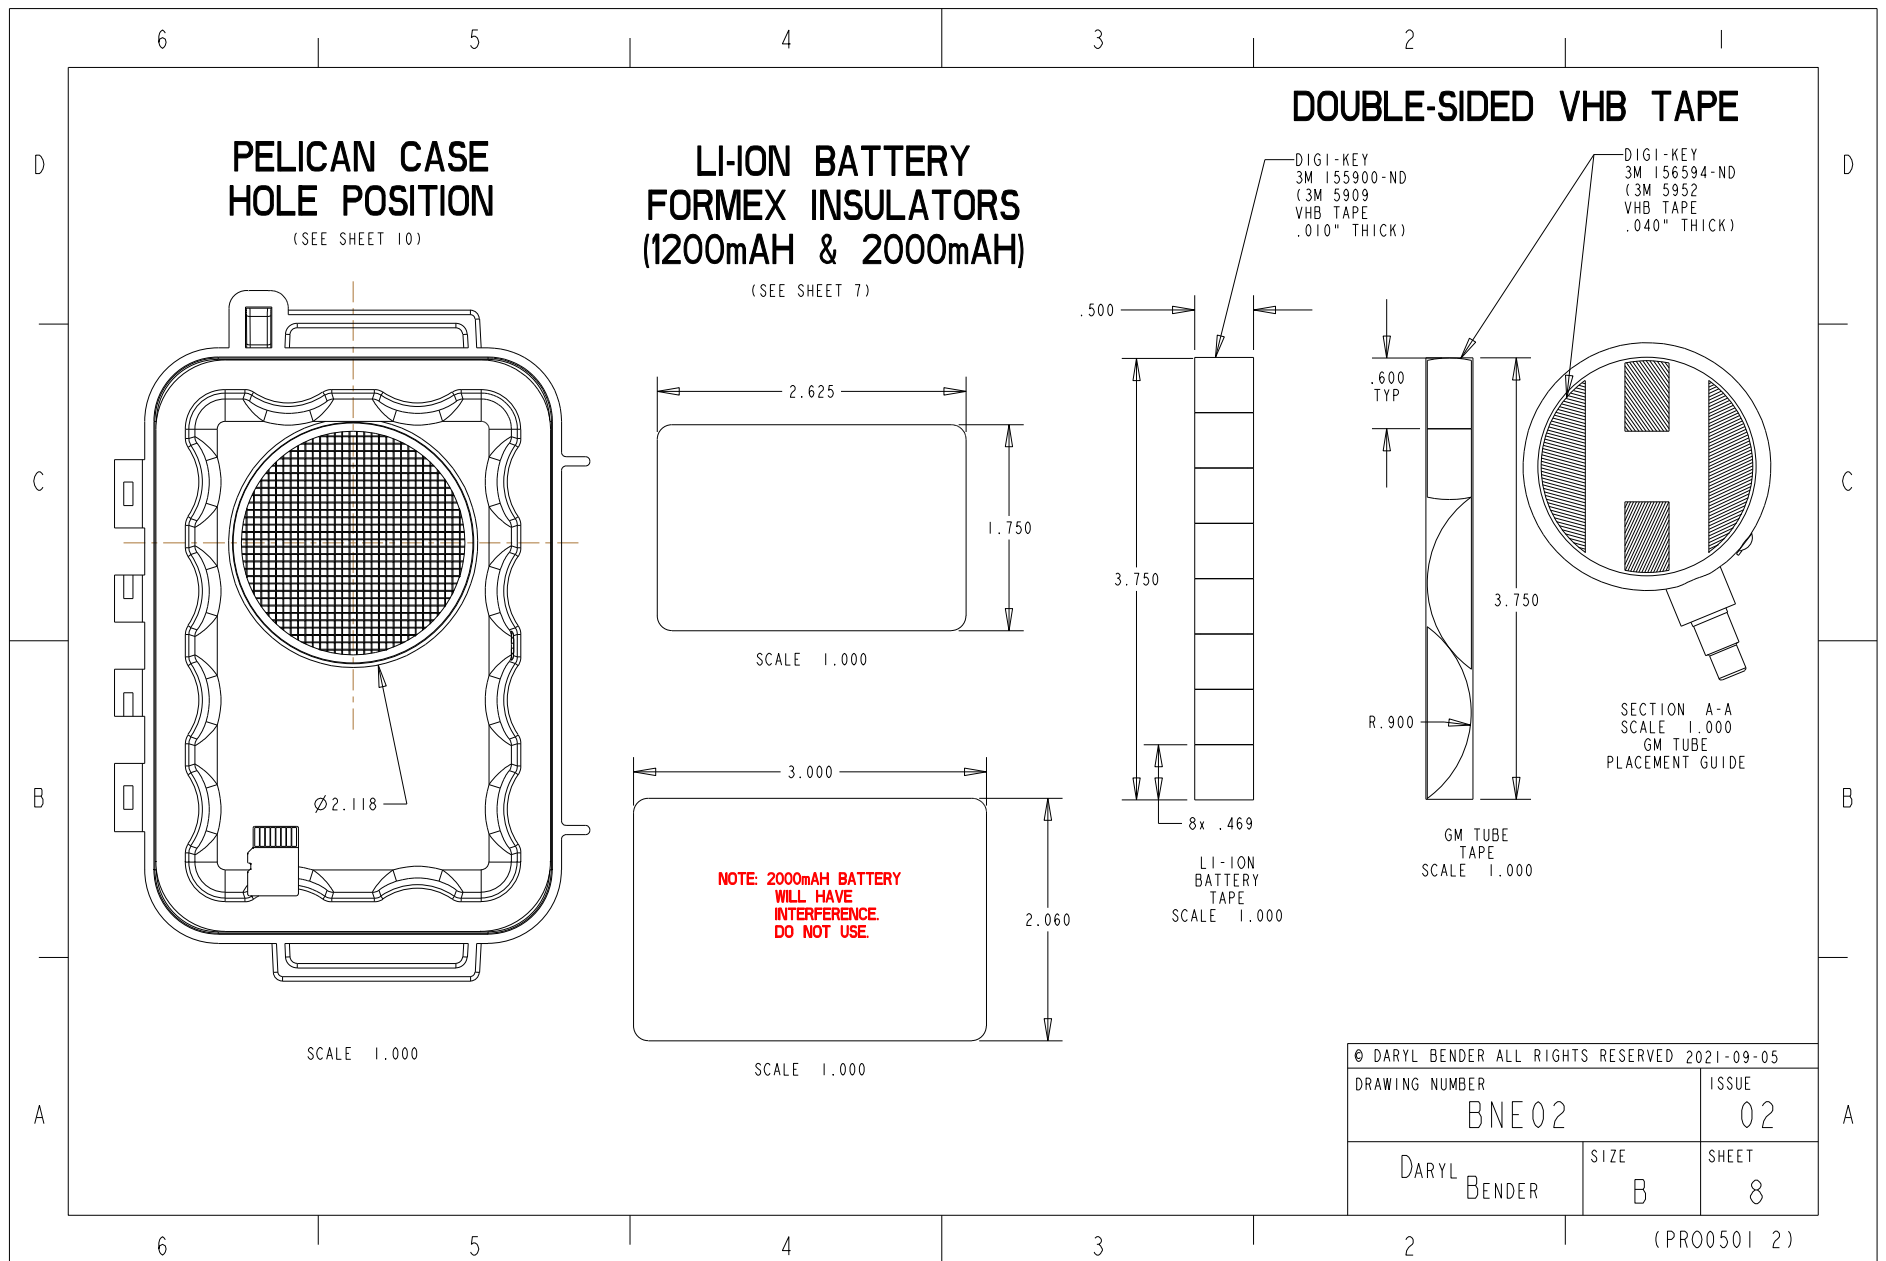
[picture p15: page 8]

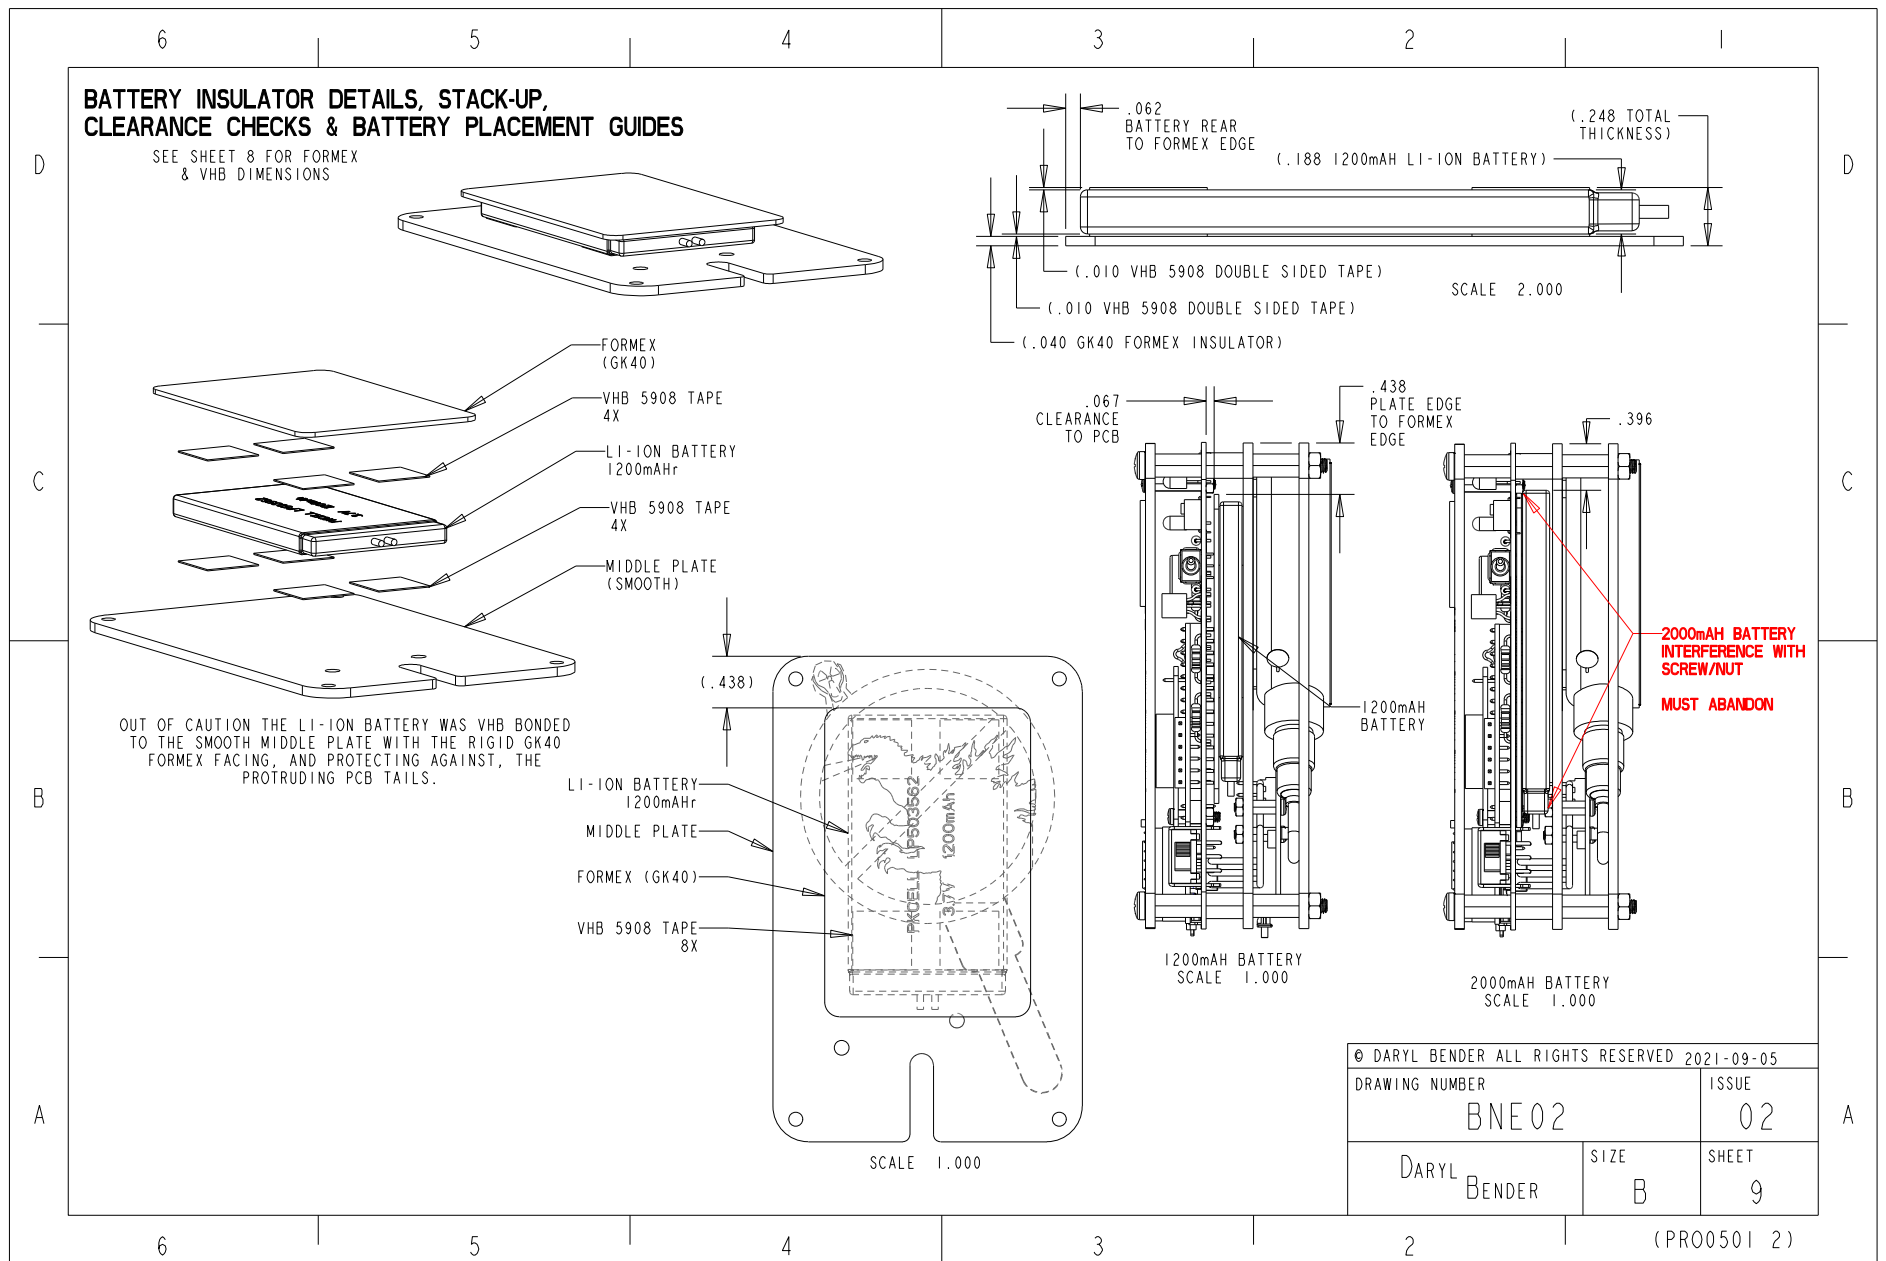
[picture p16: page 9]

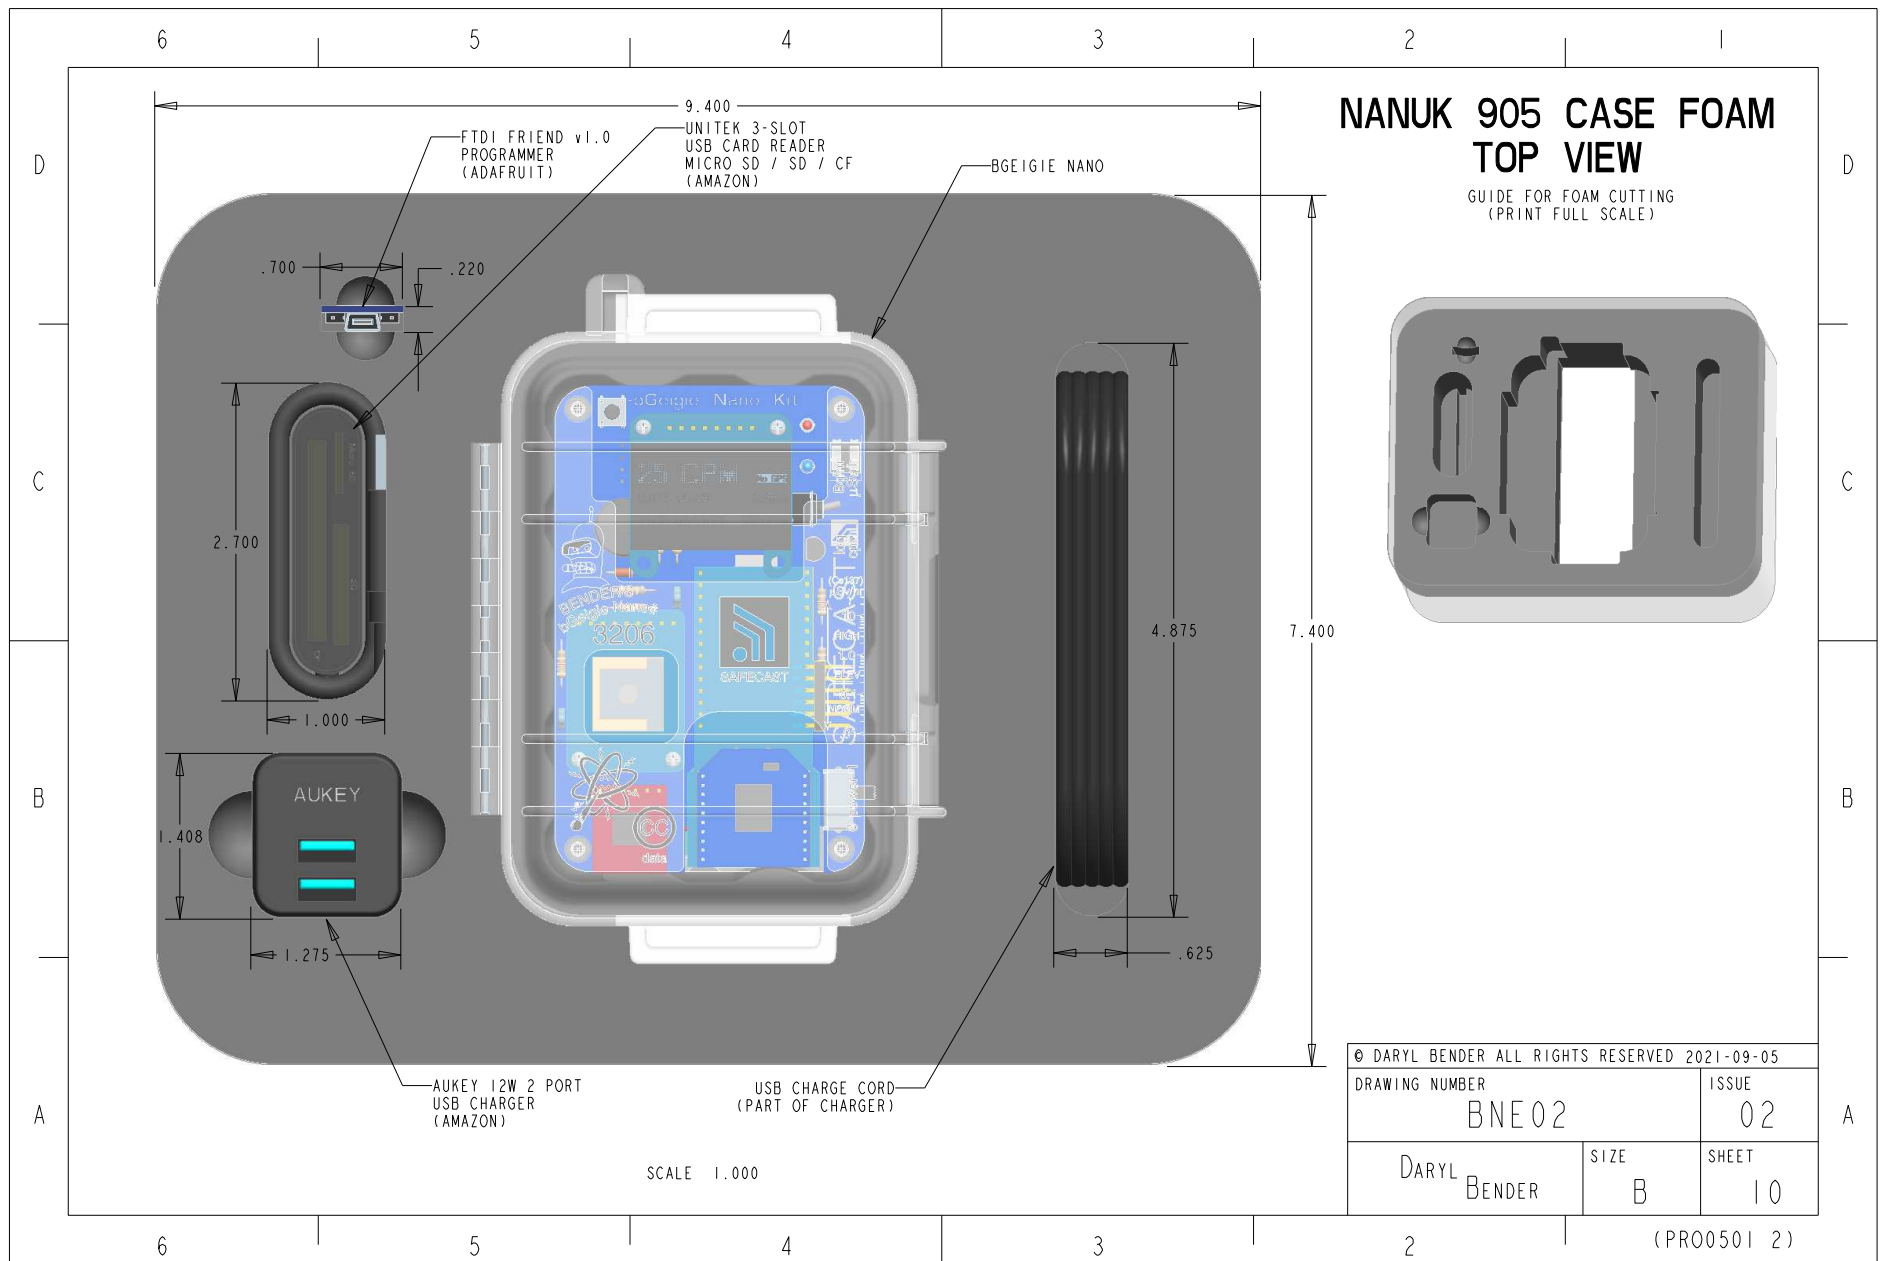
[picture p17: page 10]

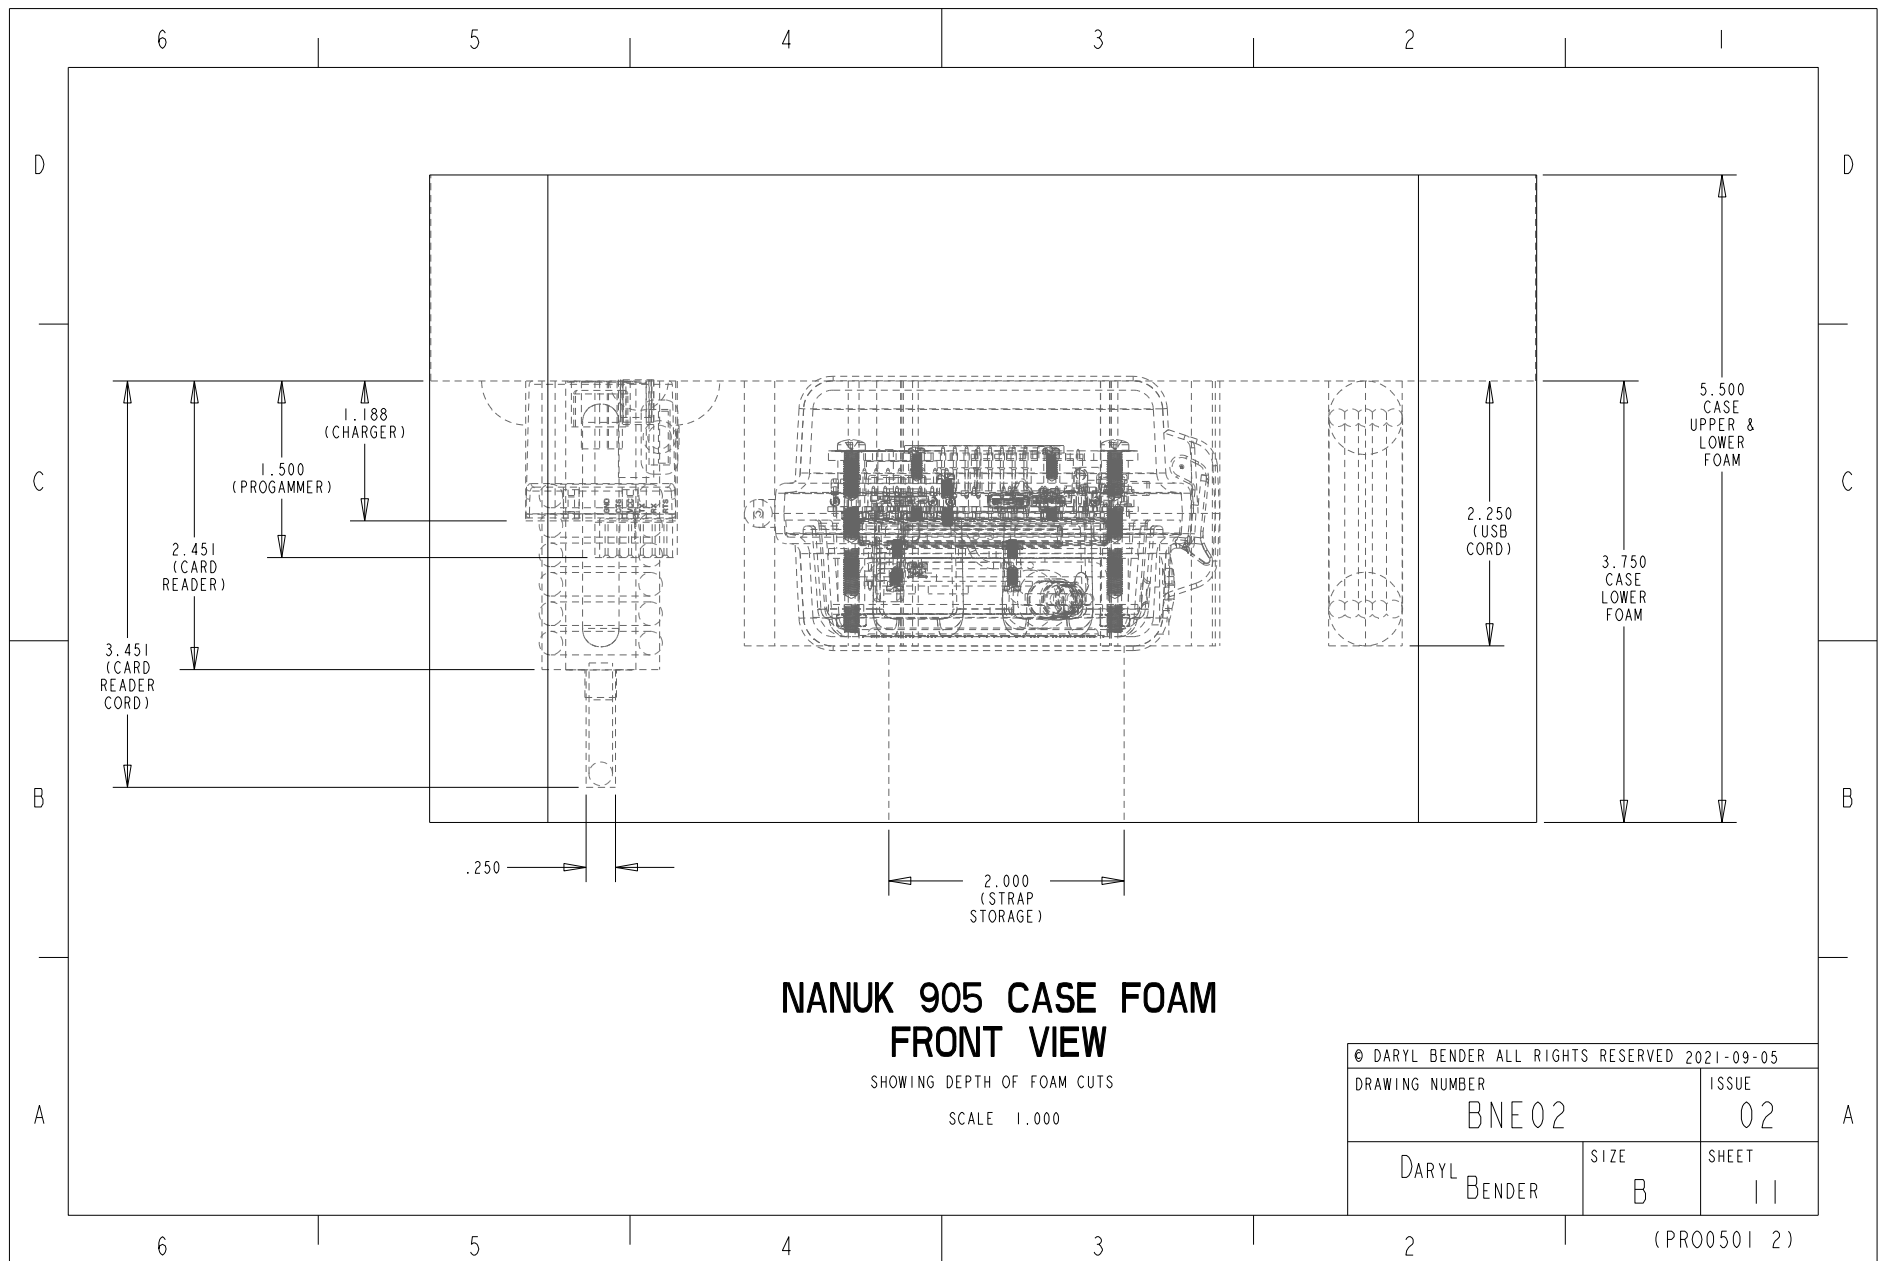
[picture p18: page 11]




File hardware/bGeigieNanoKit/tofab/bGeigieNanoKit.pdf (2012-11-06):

A

A


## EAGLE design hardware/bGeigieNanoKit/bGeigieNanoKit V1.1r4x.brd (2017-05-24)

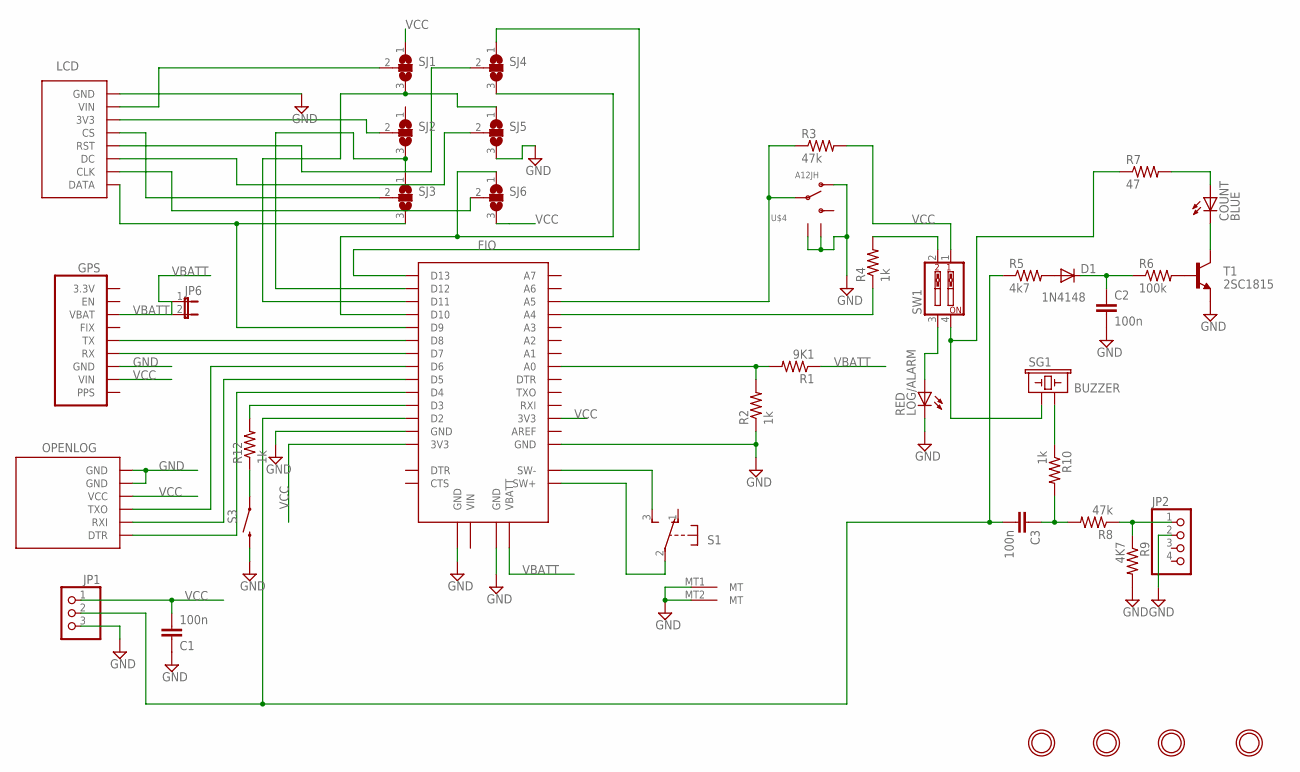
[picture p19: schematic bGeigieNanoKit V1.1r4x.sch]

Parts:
C1, C2, C3: 100n; C025-024X044
COUNT: BLUE; LED3MM
D1: 1N4148; DO35-7
FIO: FIO_SOCKETBOT; FIO_V23_SOCKET_BOT
GPS: ULTIMATE_GPSTOP; ULTIMATE_GPS_V3_TOP
JP1: PINHD-1X3/90; 1X03/90
JP2: HEADER-1X4ROUND; 1X04_ROUND
JP6: JUMPER-2SMD-NC; SJ_2S
LCD: SSD1306_128X64_V2_LCD1.3IN_LEVER; SSD1306_128X64_1.3IN_LCD_LEVER
LOG/ALARM: RED; LED3MM
OPENLOG: OPENLOG
R1: 9K1; 0207/10
R2, R4, R10, R12: 1k; 0207/10
R3, R8: 47k; 0207/10
R5: 4k7; 0207/10
R6: 100k; 0207/10
R7: 47; 0207/10
R9: 4K7; 0207/10
S1: S1; EG1206
S3: SWITCH-MOMENTARY-2PTH; TACTILE-PTH
SG1: BUZZER; BUZZER-12MM
SJ1, SJ2, SJ3, SJ4, SJ5, SJ6: SJ2W; SJ_2
SW1: SW_DIP-2; EDG-02
T1: 2SC1815; TO92-ECB
U$4: A12JH; A12AH
U$6, U$7, U$8, U$9: MOUNTINGHOLE3.0THIN; MOUNTINGHOLE_3.0_PLATEDTHIN

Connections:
GND: C1.1, C2.2, FIO.JP1$2 (GND), FIO.JP2$1 (GND), FIO.JP5$1 (GND), FIO.JP6$1 (GND), GPS.JP1$3 (GND), GPS.U$8$P$1 (GND), GPS.U$9$P$1 (GND), JP1.3, JP2.2, LCD.JP1$8 (GND), LCD.U$23$P$1 (GND), LCD.U$26$P$1 (GND), LOG/ALARM.K (C), OPENLOG.JP1$5 (GND), OPENLOG.JP1$6 (GND), R2.1, R9.2, S1.MT1 (MT), S1.MT2 (MT), S3.3 (2), SJ5.3, T1.E, U$4.P$1, U$4.P$4 (GND), U$4.P$5 (GND)
unnamed: FIO.JP1$10 (D9), LCD.JP1$1 (DATA), SJ3.3
unnamed: FIO.JP1$11 (D10), SJ4.3, SJ6.1
unnamed: FIO.JP1$12 (D11), SJ1.3, SJ5.1
unnamed: FIO.JP1$13 (D12), SJ2.3, SJ3.1
unnamed: FIO.JP1$14 (D13), SJ4.1
unnamed: FIO.JP1$9 (D8), GPS.JP1$5 (TX)
unnamed: FIO.JP1$8 (D7), GPS.JP1$4 (RX)
unnamed: FIO.JP1$7 (D6), OPENLOG.JP1$3 (TXO)
unnamed: FIO.JP1$6 (D5), OPENLOG.JP1$2 (RXI)
unnamed: FIO.JP1$5 (D4), OPENLOG.JP1$1 (DTR)
unnamed: FIO.JP5$7 (A0), R1.2, R2.2
unnamed: FIO.JP7$2 (SW+), S1.2
unnamed: FIO.JP7$1 (SW-), S1.3 (S)
unnamed: FIO.JP5$12 (A5), R3.1, U$4.P$2
unnamed: LOG/ALARM.A, SW1.3
unnamed: R4.2, SW1.2
unnamed: C3.2, FIO.JP1$3 (D2), JP1.2, R5.1
unnamed: COUNT.A, R7.2
unnamed: R12.1, S3.1
unnamed: COUNT.K (C), T1.C
unnamed: R10.1, SG1.- (2)
unnamed: C3.1, R8.2, R10.2
unnamed: JP2.1, R8.1, R9.1
unnamed: D1.A, R5.2
unnamed: C2.1, D1.C, R6.1
unnamed: R6.2, T1.B
unnamed: FIO.JP1$4 (D3), R12.2
unnamed: LCD.JP1$7 (VIN), SJ1.2
unnamed: R7.1, SG1.+ (1), SW1.4
unnamed: FIO.JP5$11 (A4), R4.1
unnamed: LCD.JP1$6 (3V3), SJ2.2
unnamed: LCD.JP1$5 (CS), SJ3.2
unnamed: LCD.JP1$4 (RST), SJ4.2
unnamed: LCD.JP1$3 (DC), SJ5.2
unnamed: LCD.JP1$2 (CLK), SJ6.2
VBATT: FIO.JP2$2 (VBATT), GPS.JP1$7 (VBAT), JP6.1, JP6.2, R1.1
VCC: C1.2, FIO.JP1$1 (3V3), FIO.JP5$3 (3V3), GPS.JP1$2 (VIN), JP1.1, OPENLOG.JP1$4 (VCC), R3.2, SJ1.1, SJ6.3, SW1.1

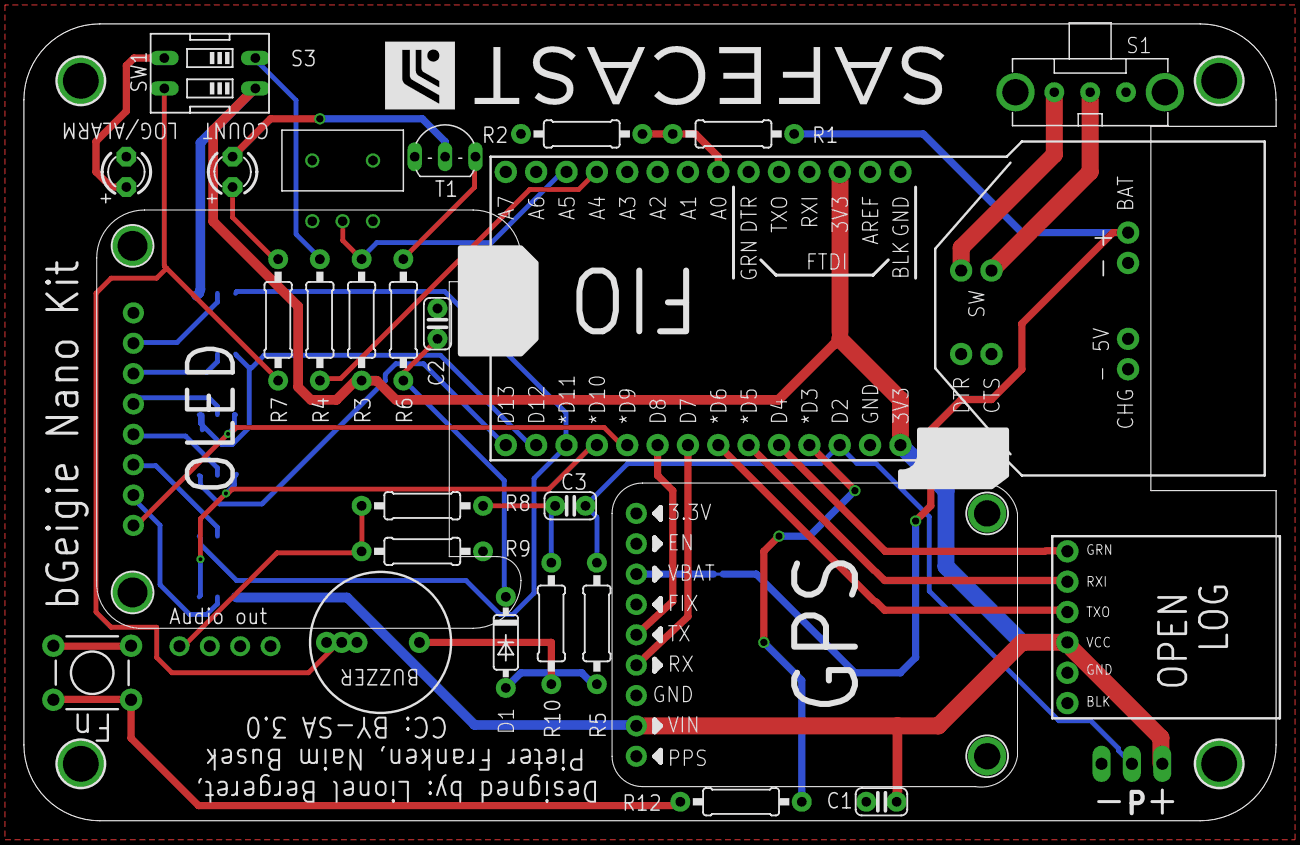
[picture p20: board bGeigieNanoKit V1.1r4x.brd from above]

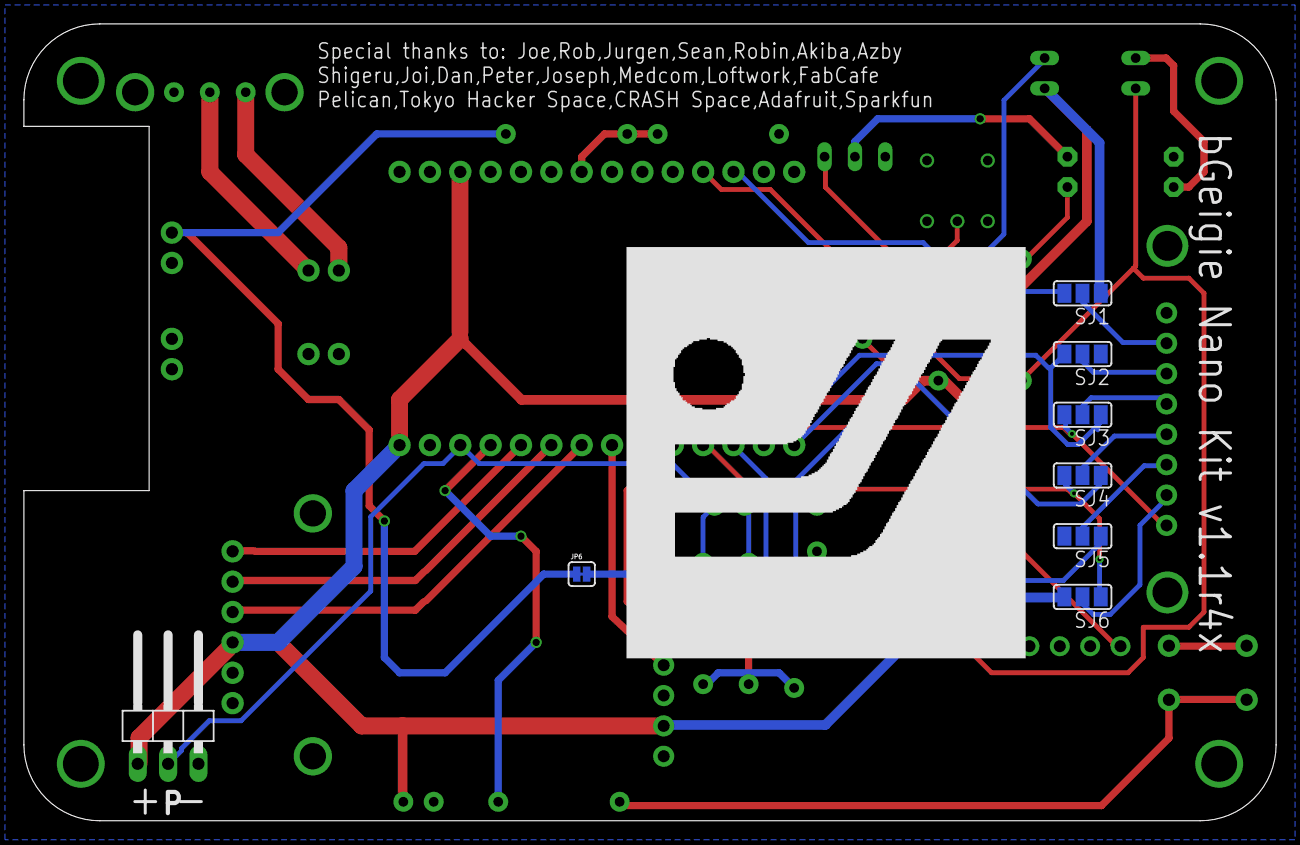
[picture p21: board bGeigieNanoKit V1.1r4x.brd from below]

Board: 2 copper layers, 104.8 x 66.7 mm, 42 parts (10 on the bottom side), 38 nets.

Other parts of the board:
U$1: SAFECAST_LOGO4
U$5: SAFECAST_LOGO2

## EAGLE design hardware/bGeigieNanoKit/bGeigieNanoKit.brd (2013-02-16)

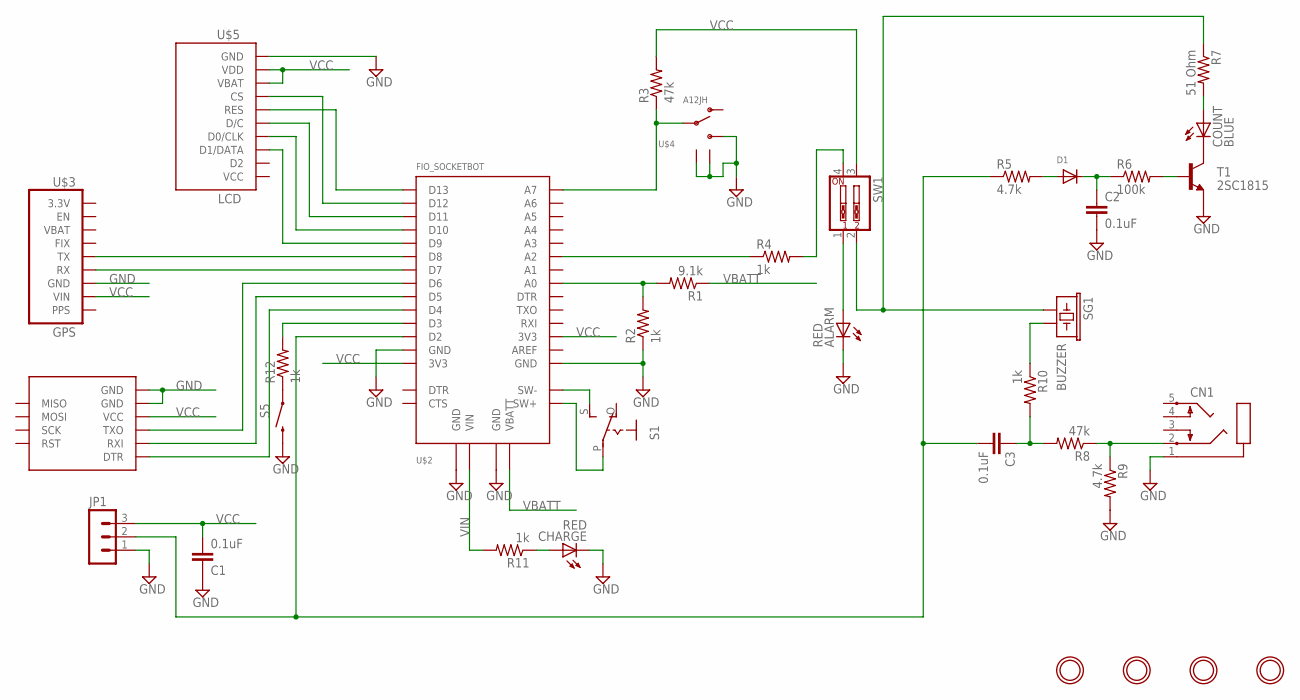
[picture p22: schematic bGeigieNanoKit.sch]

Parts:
ALARM: RED; LED3MM
C1, C2, C3: 0.1uF; C050-024X044
CHARGE: RED; LED3MM
CN1: AUDIO_STEREOJACK; STX3100
COUNT: BLUE; LED3MM
D1: DIODEDO-1N4148; DO-1N4148
JP1: MA03-1
R1: 9.1k; 0207/10
R2, R4, R10, R11, R12: 1k; 0207/10
R3, R8: 47k; 0207/10
R5, R9: 4.7k; 0207/10
R6: 100k; 0207/10
R7: 51 Ohm; 0207/10
S1: EG1218S; EG1218
S5: SWITCH-MOMENTARY-2PTH; TACTILE-PTH
SG1: BUZZER; BUZZER-12MM
SW1: SW_DIP-2; EDG-02
T1: 2SC1815; TO92-ECB
U$1: OPENLOG
U$2: FIO_SOCKETBOT; FIO_V23_SOCKET_BOT
U$3: GPS; ULTIMATE_GPS_V3_TOP
U$4: A12JH; A12AH
U$5: LCD; SSD1306_128X64_LCD_MIN
U$6, U$7, U$8, U$9: MOUNTINGHOLE3.0THIN; MOUNTINGHOLE_3.0_PLATEDTHIN

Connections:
GND: ALARM.K (C), C1.1, C2.2, CHARGE.K (C), CN1.1, JP1.1, R2.1, R9.2, S5.3 (2), T1.E, U$1.JP1$5 (GND), U$1.JP1$6 (GND), U$2.JP1$2 (GND), U$2.JP2$1 (GND), U$2.JP5$1 (GND), U$2.JP6$1 (GND), U$3.JP1$3 (GND), U$3.U$8$P$1 (GND), U$3.U$9$P$1 (GND), U$4.P$3, U$4.P$4 (GND), U$4.P$5 (GND), U$5.P0\$10 (GND)
unnamed: U$2.JP1$10 (D9), U$5.P0\$3 (D1/DATA)
unnamed: U$2.JP1$11 (D10), U$5.P0\$4 (D0/CLK)
unnamed: U$2.JP1$12 (D11), U$5.P0\$5 (D/C)
unnamed: U$2.JP1$13 (D12), U$5.P0\$7 (CS)
unnamed: U$2.JP1$14 (D13), U$5.P0\$6 (RES)
unnamed: U$2.JP1$9 (D8), U$3.JP1$5 (TX)
unnamed: U$2.JP1$8 (D7), U$3.JP1$4 (RX)
unnamed: U$1.JP1$3 (TXO), U$2.JP1$7 (D6)
unnamed: U$1.JP1$2 (RXI), U$2.JP1$6 (D5)
unnamed: U$1.JP1$1 (DTR), U$2.JP1$5 (D4)
unnamed: R1.2, R2.2, U$2.JP5$7 (A0)
unnamed: S1.P, U$2.JP7$2 (SW+)
unnamed: S1.S, U$2.JP7$1 (SW-)
unnamed: R3.1, U$2.JP5$14 (A7), U$4.P$2
unnamed: R4.1, U$2.JP5$9 (A2)
unnamed: ALARM.A, SW1.1
unnamed: R4.2, SW1.4
unnamed: C3.2, JP1.2, R5.1, U$2.JP1$3 (D2)
unnamed: COUNT.A, R7.2
unnamed: R12.1, S5.1
unnamed: R7.1, SG1.+ (1), SW1.2
unnamed: COUNT.K (C), T1.C
unnamed: R10.1, SG1.- (2)
unnamed: C3.1, R8.2, R10.2
unnamed: CN1.2, R8.1, R9.1
unnamed: D1.A, R5.2
unnamed: C2.1, D1.C, R6.1
unnamed: R6.2, T1.B
unnamed: CHARGE.A, R11.1
unnamed: R12.2, U$2.JP1$4 (D3)
VBAT: U$3.JP1$7 (VBAT)
VBATT: R1.1, U$2.JP2$2 (VBATT)
VCC: C1.2, JP1.3, R3.2, SW1.3, U$1.JP1$4 (VCC), U$2.JP1$1 (3V3), U$2.JP5$3 (3V3), U$3.JP1$2 (VIN), U$5.P0\$1 (VCC), U$5.P0\$8 (VBAT), U$5.P0\$9 (VDD)
VIN: R11.2, U$2.JP6$2 (VIN)

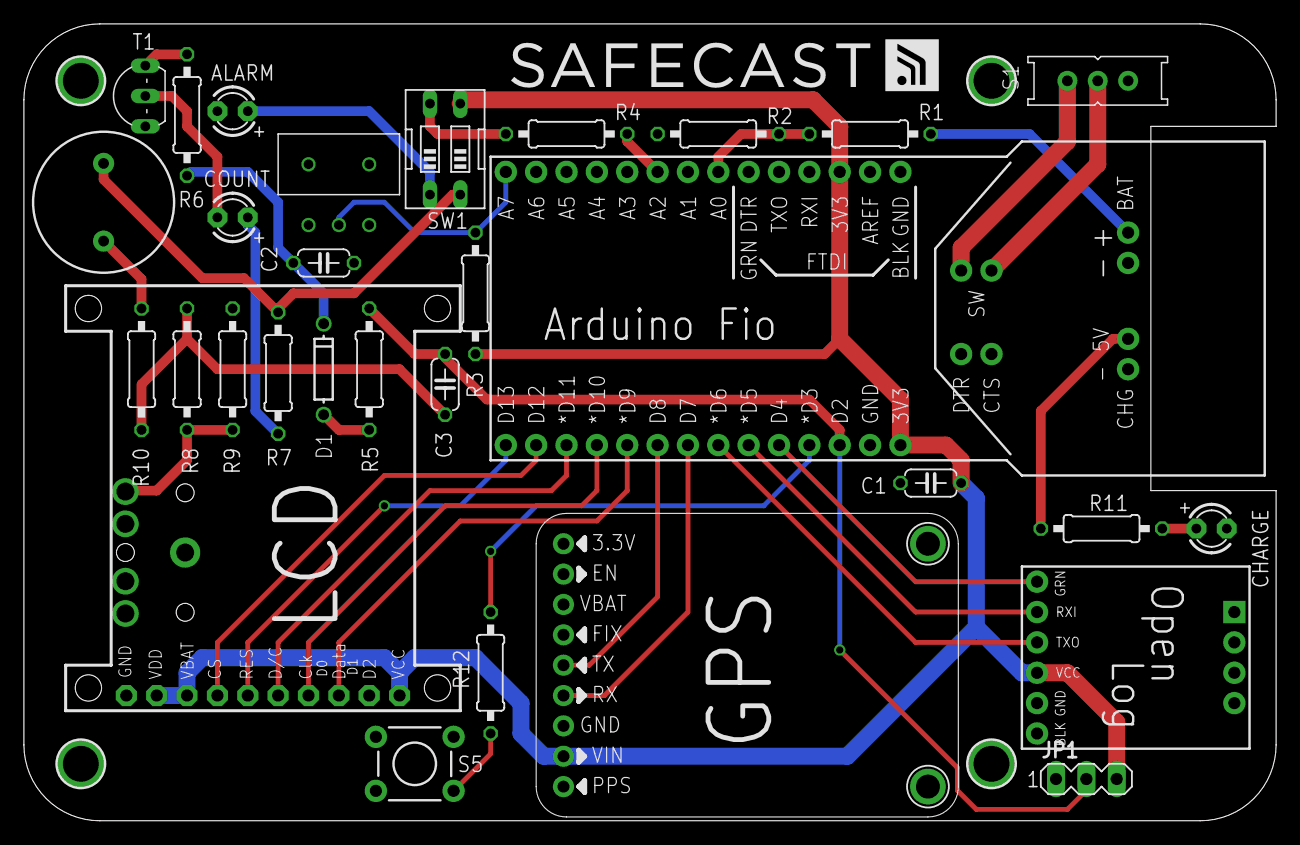
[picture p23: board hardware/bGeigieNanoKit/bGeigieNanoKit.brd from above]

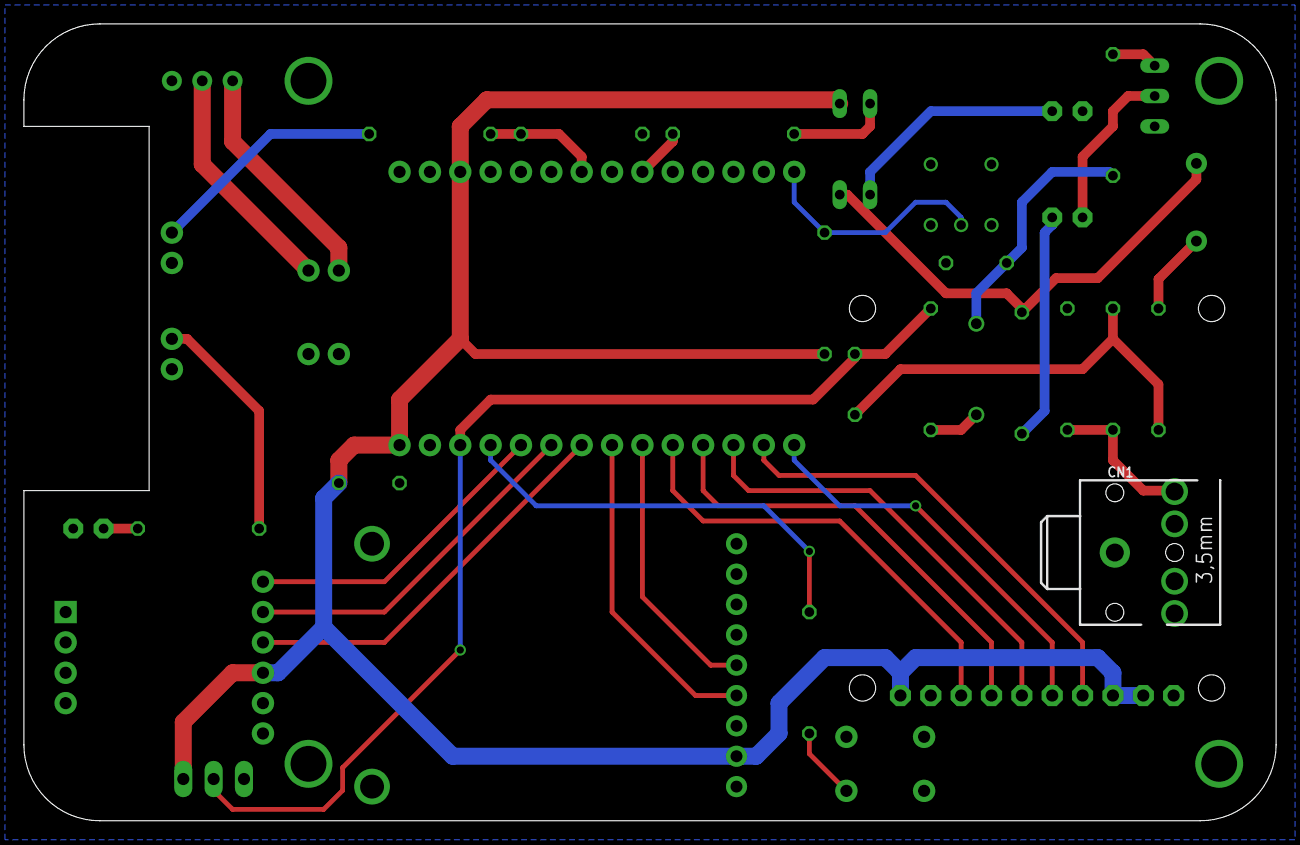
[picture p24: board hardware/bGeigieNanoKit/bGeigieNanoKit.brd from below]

Board: 2 copper layers, 104.8 x 66.7 mm, 36 parts (2 on the bottom side), 34 nets.

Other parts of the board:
U$10: SAFECAST_LOGO1

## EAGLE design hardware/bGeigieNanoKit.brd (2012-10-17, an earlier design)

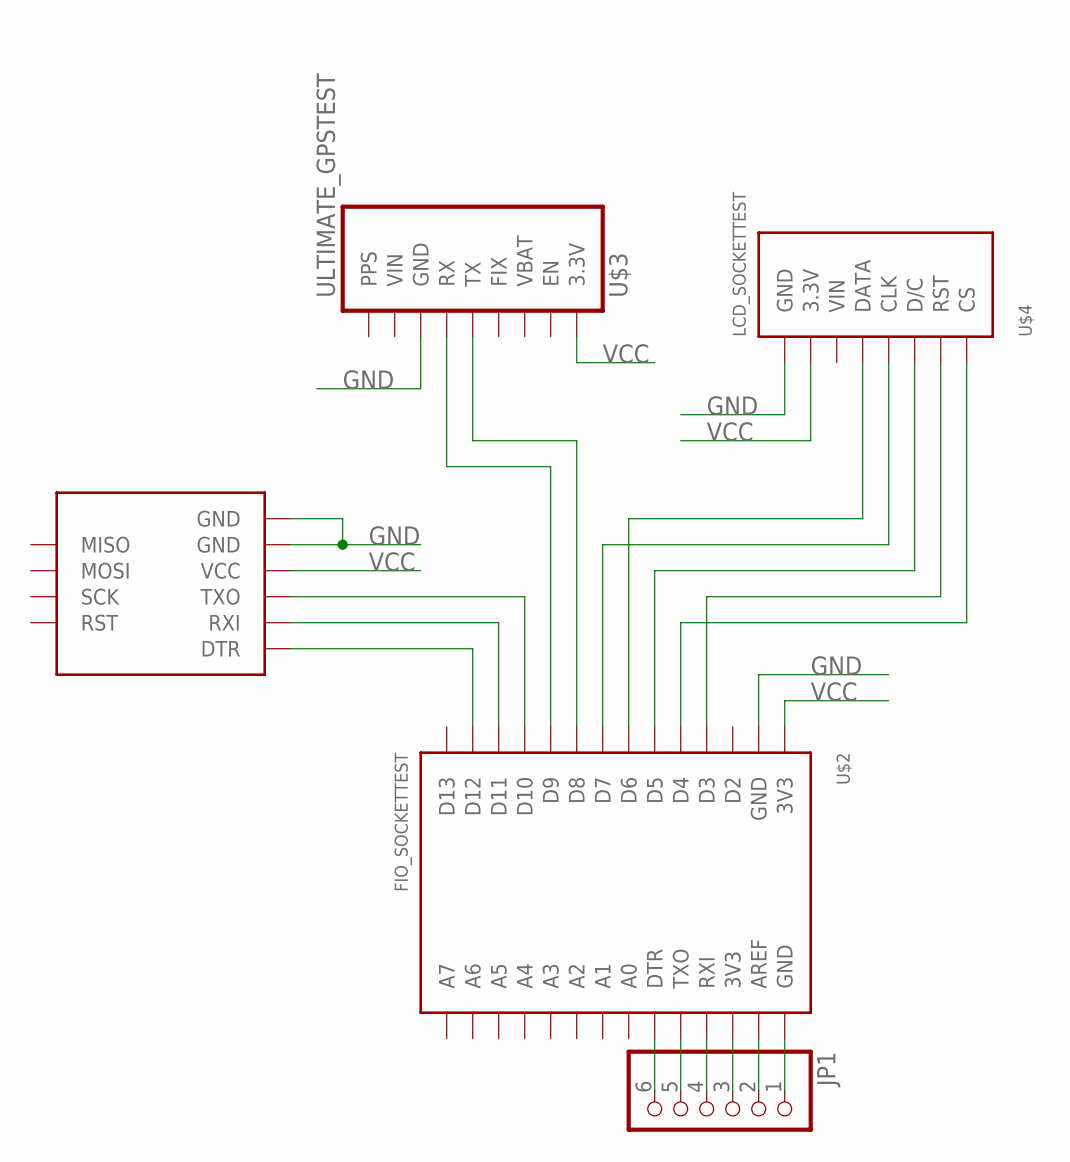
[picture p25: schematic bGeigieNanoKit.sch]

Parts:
JP1: PINHD-1X6; 1X06
U$1: OPENLOGTEST; TEST_OPENLOG
U$2: FIO_SOCKETTEST; TEST_FIO
U$3: ULTIMATE_GPSTEST; TEST_GPS
U$4: LCD_SOCKETTEST; TEST_LCD

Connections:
GND: U$1.JP1$5 (GND), U$1.JP1$6 (GND), U$2.JP1$2 (GND), U$3.JP1$2 (GND), U$3.U$8 (GND), U$3.U$9 (GND), U$4.8 (GND), U$4.U$2 (GND), U$4.U$3 (GND), U$4.U$4 (GND), U$4.U$5 (GND)
unnamed: U$1.JP1$1 (DTR), U$2.JP1$13 (D12)
unnamed: U$1.JP1$2 (RXI), U$2.JP1$12 (D11)
unnamed: U$1.JP1$3 (TXO), U$2.JP1$11 (D10)
unnamed: U$2.JP1$10 (D9), U$3.JP1$3 (RX)
unnamed: U$2.JP1$9 (D8), U$3.JP1$4 (TX)
unnamed: U$2.JP1$7 (D6), U$4.5 (DATA)
unnamed: U$2.JP1$8 (D7), U$4.4 (CLK)
unnamed: U$2.JP1$6 (D5), U$4.3 (D/C)
unnamed: U$2.JP1$4 (D3), U$4.2 (RST)
unnamed: U$2.JP1$5 (D4), U$4.1 (CS)
unnamed: JP1.1, U$2.JP5$1 (GND)
unnamed: JP1.2, U$2.JP5$2 (AREF)
unnamed: JP1.3, U$2.JP5$3 (3V3)
unnamed: JP1.4, U$2.JP5$4 (RXI)
unnamed: JP1.5, U$2.JP5$5 (TXO)
unnamed: JP1.6, U$2.JP5$6 (DTR)
VBAT: U$3.JP1$6 (VBAT)
VCC: U$1.JP1$4 (VCC), U$2.JP1$1 (3V3), U$3.JP1$8 (3.3V), U$4.7 (3.3V)
VIN: U$3.JP1$1 (VIN), U$4.6 (VIN)

Board: 2 copper layers, 5 parts (1 on the bottom side), 19 nets, no tracks yet.

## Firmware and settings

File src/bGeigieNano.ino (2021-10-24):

/*
   The bGeigie-nano
   A device for car-borne radiation measurement (aka Radiation War-driving).

   Copyright (c) 2013, Lionel Bergeret and Rob Oudendijk
   Copyright (c) 2012, Lionel Bergeret
   Copyright (c) 2011, Robin Scheibler aka FakuFaku, Christopher Wang aka Akiba
   All rights reserved.

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
   THIS SOFTWARE IS PROVIDED BY THE COPYRIGHT HOLDERS AND CONTRIBUTORS "AS IS" AND
   ANY EXPRESS OR IMPLIED WARRANTIES, INCLUDING, BUT NOT LIMITED TO, THE IMPLIED
   WARRANTIES OF MERCHANTABILITY AND FITNESS FOR A PARTICULAR PURPOSE ARE
   DISCLAIMED. IN NO EVENT SHALL <COPYRIGHT HOLDER> BE LIABLE FOR ANY
   DIRECT, INDIRECT, INCIDENTAL, SPECIAL, EXEMPLARY, OR CONSEQUENTIAL DAMAGES
   (INCLUDING, BUT NOT LIMITED TO, PROCUREMENT OF SUBSTITUTE GOODS OR SERVICES;
   LOSS OF USE, DATA, OR PROFITS; OR BUSINESS INTERRUPTION) HOWEVER CAUSED AND
   ON ANY THEORY OF LIABILITY, WHETHER IN CONTRACT, STRICT LIABILITY, OR TORT
   (INCLUDING NEGLIGENCE OR OTHERWISE) ARISING IN ANY WAY OUT OF THE USE OF THIS
   SOFTWARE, EVEN IF ADVISED OF THE POSSIBILITY OF SUCH DAMAGE.
*/


// 2017-11-24 V1.3.7   Setup for 5 seconds updates test.
// 2017-12-05 Setup mod for 5 seconds if cpm is bigger then alarm.
// 2018-06-02 fix for SDcard reading (ray)
// 2018-07-29 fixe for smaller display.

#include <limits.h>
#include <math.h>
#include <stdlib.h>
#include <avr/wdt.h>
#include <EEPROM.h>
#include "TinyGPS.h"
#include <SoftwareSerial.h>

#include "NanoSetup.h"
#include "NanoConfig.h"
#include "NanoDebug.h"


// OLED settings --------------------------------------------------------------
#if ENABLE_SSD1306
#include <Wire.h>
#include <Adafruit_GFX.h>
#include <Adafruit_SSD1306.h>

#ifdef OLED_SPI_MODE
Adafruit_SSD1306 display(OLED_DATA, OLED_CLK, OLED_DC, OLED_RESET, OLED_CS);
#else
Adafruit_SSD1306 display(OLED_RESET);
#endif

#if (SSD1306_LCDHEIGHT != 32)
#error("Height incorrect, please change Adafruit_SSD1306.h!");
#endif


#if (_SS_MAX_RX_BUFF < 128)
#error("Serial RX buffer to small, please change in SoftwareSerial.h!");
#endif

// For distance computation
bool gps_fix_first = true;
float gps_last_lon = 0, gps_last_lat = 0;
unsigned long int gps_distance = 0;
#endif

// Geiger settings ------------------------------------------------------------
#define LINE_SZ 100
#define BUFFER_SZ 12
#define STRBUFFER_SZ 32
#define AVAILABLE 'A'  // indicates geiger data are ready (available)
#define VOID      'V'  // indicates geiger data not ready (void)
#define DEFAULT_YEAR 2013
#define TIME_INTERVAL 5000
#define NX (60000/TIME_INTERVAL) // Number of bins in 1 minute (cpm_gen assumes 1 minute exactly)

// log file headers
#define LOGFILE_HEADER "# NEW LOG\n# format="
char logfile_name[13];  // placeholder for filename
bool logfile_ready = false;

// geiger statistics
unsigned long shift_reg[NX] = {0};
unsigned long reg_index = 0;
unsigned long total_count = 0;
unsigned long max_count = 0;
unsigned long uptime = 0;
int uphour = 0;
int upminute = 0;
int str_count = 0;
int maxLength_over_k = 3;
char geiger_status = VOID;

// the line buffer for serial receive and send
static char line[LINE_SZ];
static char strbuffer[STRBUFFER_SZ];
static char strbuffer1[STRBUFFER_SZ];

// Pulse counter --------------------------------------------------------------
#if ENABLE_HARDWARE_COUNTER
// Hardware counter
#include "HardwareCounter.h"
HardwareCounter hwc(HARDWARE_COUNTER_TIMER1, TIME_INTERVAL);
#else
// Interrupt counter
#include "InterruptCounter.h"
#endif

#if ENABLE_HARDWARE_COUNTER
#if ENABLE_SLEEPMODE
#define IS_READY (1)
#else
#define IS_READY (hwc.available())
#endif
#else
#define IS_READY (interruptCounterAvailable())
#endif

// previous hardware interrupt counter
COUNTER_TYPE prev_count = 0;

// OpenLog settings -----------------------------------------------------------
#if ENABLE_OPENLOG
#define OPENLOG_RETRY 200
SoftwareSerial OpenLog(OPENLOG_RX_PIN, OPENLOG_TX_PIN);
static const int resetOpenLog = OPENLOG_RST_PIN;
#endif
bool openlog_ready = false;

// Gps settings ------------------------------------------------------------
TinyGPS gps(true);
#define GPS_INTERVAL 1000
char gps_status = VOID;

#if ENABLE_SOFTGPS
SoftwareSerial gpsSerial(GPS_RX_PIN, GPS_TX_PIN);
#endif

// Gps data buffers
static char lat[BUFFER_SZ];
static char lon[BUFFER_SZ];

// MTK33x9 chipset
#define PMTK_SET_NMEA_UPDATE_1HZ "$PMTK220,1000*1F"
#define PMTK_SET_NMEA_OUTPUT_ALLDATA "$PMTK314,1,1,1,1,1,1,0,0,0,0,0,0,0,0,0,0,0,0,0*28"
#define PMTK_SET_NMEA_OUTPUT_RMCGGA "$PMTK314,0,1,0,1,0,0,0,0,0,0,0,0,0,0,0,0,0,0,0*28"
#define PMTK_HOT_START "$PMTK101*32"
#define PMTK_COLD_START "$PMTK104*37"
#define SBAS_ENABLE "$PMTK313,1*2E\r\n"
#define DGPS_WAAS_ON "$PMTK301,2*2E\r\n"

#if ENABLE_STATIC_GPS
#include <avr/pgmspace.h>
// GPS test sentences
char strGPRMC[] PROGMEM = "$GPRMC,201547.000,A,3014.5527,N,09749.5808,W,0.24,163.05,040109,,*1A";
char strGPGGA[] PROGMEM = "$GPGGA,201548.000,3014.5529,N,09749.5808,W,1,07,1.5,225.6,M,-22.5,M,18.8,0000*78";
char *teststrs[2] = {strGPRMC, strGPGGA};

static void sendstring(TinyGPS &gps, const PROGMEM char *str)
{
  while (true)
  {
    char c = pgm_read_byte_near(str++);
    if (!c) break;
    gps.encode(c);
  }
  gps.encode('\r');
  gps.encode('\n');
}
#endif

// Function definitions ---------------------------------------------------------
// Atmel Tips and Tricks: 3.6 Tip #6 – Access types: Static
static unsigned long cpm_gen();
static bool gps_gen_filename(TinyGPS &gps, char *buf);
static bool gps_gen_timestamp(TinyGPS &gps, char *buf, unsigned long counts, unsigned long cpm, unsigned long cpb);
static char checksum(char *s, int N);
#if ENABLE_OPENLOG
static void setupOpenLog();
static bool loadConfig(char *fileName);
static void createFile(char *fileName);
#endif
static void gps_program_settings();
static float read_voltage(int pin);
static int availableMemory();
static unsigned long elapsedTime(unsigned long startTime);
#if ENABLE_100M_TRUNCATION
static void truncate_100m(char *latitude, char *longitude);
#endif

// Sleep mode -----------------------------------------------------------------
#if ENABLE_SLEEPMODE
#include <avr/sleep.h>
#include <avr/power.h>

volatile int f_wdt=1;

ISR(WDT_vect)
{
  if(f_wdt == 0)
  {
    f_wdt=1;
  }
  else
  {
  }
}

void enableSleepTimer(void)
{
  cli();
  wdt_reset();

  // Setup WDT
  // Clear the reset flag
  MCUSR &= ~(1<<WDRF);

  // Set WDCE (4 clock cycles updates)
  WDTCSR |= (1<<WDCE) | (1<<WDE);

  // Set new watchdog timeout prescaler value
  WDTCSR = 1<<WDP3; // 4.0 seconds

  // Enable the WD interrupt
  WDTCSR |= _BV(WDIE);

  sei();
}

void disableSleepTimer(void)
{
  cli();
  wdt_reset();

  // Setup WDT
  // Clear the reset flag
  MCUSR &= ~(1<<WDRF);

  // Keep old prescaler setting to prevent unintentional time-out
  WDTCSR |= (1<<WDCE) | (1<<WDE);

  // Disable the WD interrupt
  WDTCSR |= 0x00;

  sei();
}

void enterSleep(void)
{
  power_all_disable();
  set_sleep_mode(SLEEP_MODE_STANDBY); // keep oscillator active

  // Enable and enter sleep mode
  sleep_enable();
  sleep_mode();

  // The program will continue from here after the WDT timeout

  // Disable sleep and re-enable the peripherals
  sleep_disable();
  power_all_enable();
}
#endif

// Nano Settings --------------------------------------------------------------
static ConfigType config;
static DoseType dose;
#if ENABLE_OPENLOG
NanoSetup nanoSetup(OpenLog, config, dose, line, LINE_SZ);
#endif

// ****************************************************************************
// Setup
// ****************************************************************************
void setup()
{

#ifdef ENABLE_CUSTOM_FN
  pinMode(CUSTOM_FN_PIN, INPUT_PULLUP);
#endif

#ifdef GPS_LED_PIN
  pinMode(GPS_LED_PIN, OUTPUT);
#endif
#ifdef LOGALARM_LED_PIN
  pinMode(LOGALARM_LED_PIN, OUTPUT);
#endif
  pinMode(GEIGIE_TYPE_PIN, INPUT);

  Serial.begin(9600);

#ifndef ENABLE_SLEEPMODE
  // enable and reset the watchdog timer
  wdt_enable(WDTO_8S);
  wdt_reset();
#endif

#if ENABLE_OPENLOG
  // Load EEPROM settings
  nanoSetup.initialize();

  OpenLog.begin(9600);
  setupOpenLog();
  if (openlog_ready) {
	nanoSetup.loadFromFile("SAFECAST.TXT");
  }
#endif


#if ENABLE_HARDWARE_COUNTER
  // Start the Pulse Counter!
  hwc.start();
  prev_count = hwc.count();
#else
  // Create pulse counter
  interruptCounterSetup(INTERRUPT_COUNTER_PIN, TIME_INTERVAL);

  // And now Start the Pulse Counter!
  interruptCounterReset();
  prev_count = interruptCounterCount();
#endif

#if ENABLE_SOFTGPS
  gpsSerial.begin(9600);

  // Put GPS serial in listen mode
  gpsSerial.listen();

  // initialize and program the GPS module
  gps_program_settings();
#endif


#if ENABLE_EEPROM_DOSE
  EEPROM_readAnything(BMRDD_EEPROM_DOSE, dose);
#endif

  // setup analog reference to read battery and boost voltage
  analogReference(INTERNAL);

#if ENABLE_SLEEPMODE
  enableSleepTimer();
#endif

#if ENABLE_SSD1306
  display.begin(SSD1306_SWITCHCAPVCC, 0x3C);
  // show splashscreen logo
  display.display();
  
  delay(1000);
  // show 3nd splashscreen
  display.clearDisplay();

  display.setTextColor(WHITE);
  display.setTextSize(1);
  sprintf_P(strbuffer, PSTR("Geigie Nano %s"), NANO_VERSION);
  display.setCursor((128-((strlen(strbuffer)+1)*6))/2, 0);
  if (config.type == GEIGIE_TYPE_B) {
    display.print("b");
  } else {
    display.print("x");
  }
  display.print(strbuffer);
  
  display.setCursor(8, 8);
  int battery =((read_voltage(VOLTAGE_PIN)-30)*12.5);
  battery=(battery+20);
    if (battery < 0) battery=1;
    if (battery > 100) battery=100;
  sprintf_P(strbuffer, PSTR("Battery= %02d"), battery); 
  display.print(strbuffer);
  sprintf_P(strbuffer, PSTR("%%"));
  display.print(strbuffer);
    
  display.setCursor(55, 16);
  sprintf_P(strbuffer, PSTR("Alarm=%d"), config.alarm_level);
  display.print(strbuffer);
  sprintf_P(strbuffer, PSTR("CPM"));
  display.print(strbuffer);
  

  display.setCursor(8, 16);
  sprintf_P(strbuffer, PSTR("Mode =%d"), config.sensor_mode);
  display.print(strbuffer);

  display.setTextSize(1);
  display.setCursor(85, 8);
  sprintf_P(strbuffer, PSTR("#%04d"), config.device_id);
  display.print(strbuffer);

  display.setTextSize(1);
  if (strlen(config.user_name)) {
    display.setCursor((128-(strlen(config.user_name)*6))/2, 24); // textsize*8
    display.print(config.user_name);
  }
  display.display();
   delay(9000);
  
#endif

  //Serial.println(availableMemory());

}



// ****************************************************************************
// Main loop
// ****************************************************************************
void loop()
{
  bool gpsReady = false;

#if ENABLE_GEIGIE_SWITCH
  // Check geigie mode switch
  if (analogRead(GEIGIE_TYPE_PIN) > GEIGIE_TYPE_THRESHOLD) {
    config.type = GEIGIE_TYPE_B; // XGeigie;
  } else {
    config.type = GEIGIE_TYPE_X; // BGeigie
    digitalWrite(LOGALARM_LED_PIN, LOW);
  }
#endif

#if ENABLE_GEIGIE_SWITCH
  //Switch to bGeigie Xmode on low battery
    int battery = ((read_voltage(VOLTAGE_PIN)-30));
    if (battery < 1)  { 
       delay(1000);
       config.type = GEIGIE_TYPE_X; // BGeigie
  }
#endif

#if ENABLE_SLEEPMODE
  if(f_wdt == 1)
  {
    disableSleepTimer();
#endif

#if ENABLE_SOFTGPS
  // Put GPS serial in listen mode
  gpsSerial.listen();
#endif

  // For GPS_INTERVAL we work on parsing GPS sentences
  for (unsigned long start = millis(); (elapsedTime(start) < GPS_INTERVAL) and !IS_READY;)
  {
#if ENABLE_STATIC_GPS
    for (int i=0; i<2; ++i)
    {
      sendstring(gps, teststrs[i]);
    }
#else
#if ENABLE_SOFTGPS
    while (gpsSerial.available())
    {
      char c = gpsSerial.read();
#else
    while (Serial.available())
    {
      char c = Serial.read();
#endif

#if ENABLE_GPS_NMEA_LOG
      Serial.print(c); // uncomment this line if you want to see the GPS data flowing
#endif
      if (gps.encode(c)) // Did a new valid sentence come in?
        gpsReady = true;
    }
#endif
  }

#if ENABLE_SLEEPMODE
  // Will wakeup in 4 seconds from now
  enableSleepTimer();
#endif

#ifdef GPS_LED_PIN
  if ((gpsReady) || (gps_status == AVAILABLE)) {
   // digitalWrite(GPS_LED_PIN, HIGH);
  } else {
   // digitalWrite(GPS_LED_PIN, LOW);
  }
#endif

  // generate CPM every TIME_INTERVAL seconds
  if IS_READY {
      unsigned long cpm=0, cpb=0;

#ifndef ENABLE_SLEEPMODE
      // first, reset the watchdog timer
      wdt_reset();
#endif

      // obtain the count from the hardware
#if ENABLE_HARDWARE_COUNTER
      // obtain the count in the last bin
      COUNTER_TYPE this_count = hwc.count();
#else
      COUNTER_TYPE this_count = interruptCounterCount();
#endif

	  // Compute count in the previous bucket based on the difference
	  // between the prior count and the current count.  This algorithm
	  // is used instead of one that resets the hardware count, so that
	  // we don't have any windows in which we will miss interrupts.
	  // Note that because the counter counts up to the full value of
	  // COUNTER_TYPE before wrap, this math works even after
	  // the counter wraps.  For example, for a COUNTER_TYPE that
	  // is 32-bits, 3 - 0xfffffffe == 5
      cpb = this_count - prev_count;
	  prev_count = this_count;

      // insert count in sliding window and compute CPM
      shift_reg[reg_index] = cpb;     // put the count in the correct bin
      reg_index = (reg_index+1) % NX; // increment register index
      cpm = cpm_gen();                // compute sum over all bins

      // update the total counter
      total_count += cpb;
      uptime += TIME_INTERVAL/1000;

      // update max cpm
      if (cpm > max_count) max_count = cpm;

#if ENABLE_EEPROM_DOSE
      dose.total_count += cpb;
      dose.total_time += TIME_INTERVAL/1000;
      if (dose.total_time % BMRDD_EEPROM_DOSE_WRITETIME == 0) {
         EEPROM_writeAnything(BMRDD_EEPROM_DOSE, dose);
      }
#endif

      // set status of Geiger
      if (str_count < NX)
      {
        geiger_status = VOID;
        str_count++;
      } else if (cpm == 0) {
        geiger_status = VOID;
      } else {
        geiger_status = AVAILABLE;
      }

#if ENABLE_WAIT_GPS_FOR_LOG
      if ((!logfile_ready) && (gps_status == AVAILABLE))
#else
      if (!logfile_ready)
#endif
      {
         if (gps_gen_filename(gps, logfile_name)) {
           logfile_ready = true;

#if ENABLE_OPENLOG
#ifdef LOGALARM_LED_PIN
           //digitalWrite(LOGALARM_LED_PIN, HIGH);
#endif
           createFile(logfile_name);
           // print header to serial
           sprintf_P(strbuffer, PSTR(LOGFILE_HEADER));
           OpenLog.print(strbuffer);
           DEBUG_PRINT(strbuffer);
           sprintf_P(strbuffer, PSTR(NANO_VERSION));
           OpenLog.print(strbuffer);
           DEBUG_PRINT(strbuffer);

#ifdef ENABLE_LND_DEADTIME
           sprintf_P(strbuffer, PSTR("nano\n# deadtime=on\n"));
#else
           sprintf_P(strbuffer, PSTR("nano\n"));
#endif
           OpenLog.print(strbuffer);

#endif // ENABLE_OPENLOG
         }
      }

      // generate timestamp. only update the start time if
      // we printed the timestamp. otherwise, the GPS is still
      // updating so wait until its finished and generate timestamp
      memset(line, 0, LINE_SZ);
      gps_gen_timestamp(gps, line, shift_reg[reg_index], cpm, cpb);

      // Printout line
      Serial.println(line);

#if ENABLE_OPENLOG
      if ((logfile_ready) && (GEIGIE_TYPE_B == config.type)) {
#ifdef LOGALARM_LED_PIN
        //digitalWrite(LOGALARM_LED_PIN, HIGH);
#endif
        // Put OpenLog serial in listen mode
        OpenLog.listen();
        OpenLog.println(line);

#if ENABLE_DIAGNOSTIC
        dtostrf(read_voltage(VOLTAGE_PIN), 0, 1, strbuffer);
        OpenLog.print("$DIAG,");
        OpenLog.println(strbuffer);
#endif
      }
#ifdef LOGALARM_LED_PIN
      //digitalWrite(LOGALARM_LED_PIN, LOW);
#endif
#endif
  }



}

// ****************************************************************************
// Utility functions
// ****************************************************************************

/* calculate elapsed time. this takes into account rollover */
unsigned long elapsedTime(unsigned long startTime) {
  unsigned long stopTime = millis();

  if (startTime >= stopTime) {
    return startTime - stopTime;
  } else {
    return (ULONG_MAX - (startTime - stopTime));
  }
}

#if ENABLE_OPENLOG
/* wait for openlog prompt */
bool waitOpenLog(bool commandMode) {
  int safeguard = 0;
  bool result = false;

  while(safeguard < OPENLOG_RETRY) {
    safeguard++;
    if(OpenLog.available())
      if(OpenLog.read() == (commandMode ? '>':'<')) break;
    delay(10);
  }

  if (safeguard >= OPENLOG_RETRY) {
  } else {
    result = true;
  }

  return result;
}

/* setups up the software serial, resets OpenLog */
void setupOpenLog() {
  pinMode(resetOpenLog, OUTPUT);
  OpenLog.listen();

  // reset OpenLog
  digitalWrite(resetOpenLog, LOW);
  delay(100);
  digitalWrite(resetOpenLog, HIGH);

  if (!waitOpenLog(true)) {
    logfile_ready = true;
  } else {
    openlog_ready = true;
  }
}

/* create a new file */
void createFile(char *fileName) {
  int result = 0;
  int safeguard = 0;

  OpenLog.listen();

  do {
    result = 0;

    do {
#ifndef ENABLE_SLEEPMODE
      // reset the watchdog timer
      wdt_reset();
#endif


      OpenLog.print("append ");
      OpenLog.print(fileName);
      OpenLog.write(13); //This is \r

      if (!waitOpenLog(false)) {
        break;
      }
      result = 1;
    } while (0);

    if (0 == result) {
      // reset OpenLog
      digitalWrite(resetOpenLog, LOW);
      delay(100);
      digitalWrite(resetOpenLog, HIGH);

      // Wait for OpenLog to return to waiting for a command
      waitOpenLog(true);
    }
  } while (0 == result);

  //OpenLog is now waiting for characters and will record them to the new file
}
#endif

/* compute check sum of N bytes in array s */
char checksum(char *s, int N)
{
  int i = 0;
  char chk = s[0];

  for (i=1 ; i < N ; i++)
    chk ^= s[i];

  return chk;
}

/* compute cpm */
unsigned long cpm_gen()
{
   unsigned int i;
   unsigned long c_p_m = 0;

   // sum up
   for (i=0 ; i < NX ; i++)
   c_p_m += shift_reg[i];

#ifdef ENABLE_LND_DEADTIME
   //	 deadtime compensation (medcom international)
   c_p_m = (unsigned long)((float)c_p_m/(1-(((float)c_p_m*1.8833e-6))));
#endif
   return c_p_m;
}

/* generate log filename */
bool gps_gen_filename(TinyGPS &gps, char *buf) {
  int year = DEFAULT_YEAR;
  byte month = 0, day = 0, hour = 0, minute = 0, second = 0, hundredths = 0;
  unsigned long age;

  gps.crack_datetime(&year, &month, &day, &hour, &minute, &second, &hundredths, &age);
  if (TinyGPS::GPS_INVALID_AGE == age) {
    return false;
  }

  // Create the filename for that drive
  sprintf_P(buf, PSTR("%04d%02d%02d.log"),config.device_id, month, day);

  return true;
}

/* convert long integer from TinyGPS to string "xxxxx.xxxx" */
void get_coordinate_string(bool is_latitude, unsigned long val, char *buf)
{
  unsigned long left = 0;
  unsigned long right = 0;

  left = val/100000;
  right = (val - left*100000)/10;
  if (is_latitude) {
    sprintf_P(buf, PSTR("%04ld.%04ld"), left, right);
  } else {
    sprintf_P(buf, PSTR("%05ld.%04ld"), left, right);
  }
}

/* convert long integer from TinyGPS to float WGS84 degrees */
float get_wgs84_coordinate(unsigned long val)
{
  double result = 0.0;
  result = val/10000000.0;
  result = ((result-(int)result)/60.0)*100 + (int)result;
  return (float)result;
}

/* render measurement in big digit on display */
//set extra variable for hot spot mode is_hotspot ad Boolean
void render_measurement(unsigned long value5sec,unsigned long value, bool is_cpm, int offset)
{
  display.setCursor(0, offset);
  display.setTextSize(2);
  if (VOID == geiger_status) {
    display.setTextColor(BLACK, WHITE); // 'inverted' text
  } else {
    display.setTextColor(WHITE);
  }

  // Cleanup temp buffer
  memset(strbuffer1, 0, sizeof(strbuffer1));

// display 5 second fast update mode if alam level is higher as set level on sdcard. 
      if (value >config.alarm_level) {
          value= (value5sec*12); // display 5 seconds data on display
        } else {
      }


  // display in CPM
  if (is_cpm) {
    if(value >= 10000) {
	  dtostrf(((float)value)/1000.0, 4, 3, strbuffer);
      strncpy (strbuffer1, strbuffer, 3);
      if (strbuffer1[strlen(strbuffer1)-1] == '.') {
        strbuffer1[strlen(strbuffer1)-1] = 0;
      }
      display.print(strbuffer1);
      sprintf_P(strbuffer, PSTR("kCPM"));

      display.print(strbuffer);
    } else {
	  dtostrf((float)value, 0, 0, strbuffer);
      display.print(strbuffer);
      sprintf_P(strbuffer, PSTR(" CPM"));
      display.print(strbuffer);
    }
  } else {
    // display in Sievert/h
    if ((value/config.cpm_factor) >= 1000) {
	  dtostrf(((float)value)/config.cpm_factor/1000.0, 4, 2, strbuffer);
      strncpy (strbuffer1, strbuffer, 5);
      if (strbuffer1[strlen(strbuffer1)-1] == '.') {
        strbuffer1[strlen(strbuffer1)-1] = 0;
      }
      display.print(strbuffer1);
      sprintf_P(strbuffer, PSTR(" mS/h"));
      display.print(strbuffer);
    } else if ((value/config.cpm_factor) >= 10) {
	  dtostrf(((float)value)/config.cpm_factor/1.0, 4, 2, strbuffer);
      strncpy (strbuffer1, strbuffer, 5);
      if (strbuffer1[strlen(strbuffer1)-1] == '.') {
        strbuffer1[strlen(strbuffer1)-1] = 0;
      }
      display.print(strbuffer1);
      sprintf_P(strbuffer, PSTR(" uS/h"));
      display.print(strbuffer);
    } else {
	  dtostrf(((float)value)/config.cpm_factor/1.0, 4, 3, strbuffer);
      strncpy (strbuffer1, strbuffer, 6);
      if (strbuffer1[strlen(strbuffer1)-1] == '.') {
        strbuffer1[strlen(strbuffer1)-1] = 0;
      }
      display.print(strbuffer1);
      sprintf_P(strbuffer, PSTR(" uS/h"));
      display.print(strbuffer);
    }
  }
}
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

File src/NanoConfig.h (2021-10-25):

#ifndef _NANO_CONFIG_H_
#define _NANO_CONFIG_H_

//
// bGeigie Nano definitions
//

#define NANO_DEVICE_ID        0000
#define NANO_VERSION       "1.4.5"
#define NANO_HEADER        "BNRDD"
#define NANO_CPM_FACTOR        334
#define NANO_BQM2_FACTOR        37

//  
// Enable or Disable features
//

#define ENABLE_DEBUG             0
#define ENABLE_DIAGNOSTIC        0
#define ENABLE_SLEEPMODE         0
#define ENABLE_SSD1306           1
#define ENABLE_SOFTGPS           1
#define ENABLE_STATIC_GPS        0
#define ENABLE_HARDWARE_COUNTER  0
#define ENABLE_OPENLOG           1
#define ENABLE_WAIT_GPS_FOR_LOG  1
#define ENABLE_GPS_NMEA_LOG      0
#define ENABLE_100M_TRUNCATION   0
#define ENABLE_MEDIATEK          1
#define ENABLE_SKYTRAQ           0
#define ENABLE_EEPROM_DOSE       1
#define ENABLE_CUSTOM_FN         1 // enable custom function button
#define ENABLE_LND_DEADTIME      1 // enable dead-time compensation for LND7317
#define ENABLE_GEIGIE_SWITCH     1 // switch between bGeigie and xGeigie type
#define ENABLE_NANOKIT_PIN       1 // use the nano kit configuration
#define ENABLE_NANOPCBKIT_PIN    1 // use the nano pcb kit configuration

#if ENABLE_SSD1306 // high memory usage (avoid logs)
#undef ENABLE_DEBUG // disable debug log output
#endif

//
// Pins definition
//

#if ENABLE_NANOKIT_PIN
#if ENABLE_NANOPCBKIT_PIN
  #warning NANO PCB KIT with OLED screen used !
  #define OLED_SPI_MODE // SPI mode enabled
  #define OLED_CLK 10
  #define OLED_DATA 9
  #define OLED_DC 11
  #define OLED_CS 12
  #define OLED_RESET 13
  #define GPS_RX_PIN 8
  #define GPS_TX_PIN 7
  #define OPENLOG_RX_PIN 6
  #define OPENLOG_TX_PIN 5
  #define OPENLOG_RST_PIN 4
  #define LOGALARM_LED_PIN A4
  #define CUSTOM_FN_PIN 3
#else
  #warning NANO KIT with OLED screen used !
  #define OLED_SPI_MODE // SPI mode enabled
  #define OLED_CLK 7
  #define OLED_DATA 6
  #define OLED_DC 5
  #define OLED_CS 4
  #define OLED_RESET 3
  #define GPS_RX_PIN 8
  #define GPS_TX_PIN 9
  #define OPENLOG_RX_PIN 10
  #define OPENLOG_TX_PIN 11
  #define OPENLOG_RST_PIN 12
#endif  // ENABLE_NANOPCBKIT_PIN
#else
#if ENABLE_HARDWARE_COUNTER
  // Pin assignment for version 1.0.1
  #warning Hardware counter is used !
  #define OLED_RESET 4
  #define GPS_RX_PIN 6
  #define GPS_TX_PIN 7
  #define OPENLOG_RX_PIN 8
  #define OPENLOG_TX_PIN 9
  #define OPENLOG_RST_PIN 10
#else
  // Old Pin assignment for version 1.0.0
  #warning Interrupt counter is used !
  #define OLED_RESET 4
  #define GPS_RX_PIN 5
  #define GPS_TX_PIN 6
  #define OPENLOG_RX_PIN 7
  #define OPENLOG_TX_PIN 8
  #define OPENLOG_RST_PIN 9
#endif
#endif


// HardwareCounter pin
// the timer1 pin on the 328p is D5
#define HARDWARE_COUNTER_TIMER1 5

// InterruptCounter pin
// 0 = D2, 1 = D3
#define INTERRUPT_COUNTER_PIN 0

// bGeigie <-> xGeigie switch pin
#define GEIGIE_TYPE_PIN A5
#define GEIGIE_TYPE_THRESHOLD 500

// Voltage divider
// GND -- R2 --A0 -- R1 -- VCC
// https://en.wikipedia.org/wiki/Voltage_divider
#define VOLTAGE_PIN A0
#define VOLTAGE_R1 9100
#define VOLTAGE_R2 1000

#endif

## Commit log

2012-06-05 Fix latitude and longitude output format (6 digits)
    [bGeigieNano.ino]
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2012-06-06 Add a 15 hours log (using a fully charged 3.7V 850mAh Li-Ion battery)
2012-06-06 First running version (more than 15 hours using a 850mAh battery)
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2012-07-02 Add global pin definition and Mini Pro support (software serial for GPS instead of XBee socket)
2012-07-02 Fix missing SoftwareSerial initialization
    [bGeigieNano.ino]
2012-07-05 Update the sample log to match latest version
2012-07-06 Add EEPROM device id support (USE_EEPROM_ID) to be used with bGeigieConfigBurner
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2012-07-11 Fix log file name generator (don't generate if date is null)
    [bGeigieNano.ino]
2012-09-25 Update documentation diagram
    [bGeigieNanoKit.fzz]
2012-09-25 Add openlog component to diagram
    [bGeigieNanoKit.fzz]
2012-09-26 Update OLED screen to Adafruit 128x32 091" SPI
    [bGeigieNanoKit.fzz]
2012-09-27 Fix OpenLog GND pin connection
    [bGeigieNanoKit.fzz]
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2012-09-28 Update pin connections
    [bGeigieNanoKit.fzz]
2012-10-01 Configuration file for OpenLog
    [CONFIG.TXT]
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2012-10-02 Always printout the log on serial (BluetoothBee use case)
2012-10-02 Fix cpm factor to float
    [bGeigieNano.ino]
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2012-10-05 Update log filename to handle 4 digits device id
2012-10-05 Add config support to sensor type, shield, height and mode
2012-10-07 Fix Geiger type switch from bGeigie to xGeigie
    [bGeigieNano.ino]
2012-10-11 Add geigie type switch support Update battery indicator (3.5v to 4.3v)
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2012-10-11 Fix geigie switch and diagnotic options
    [bGeigieNano.ino]
2012-10-16 adding minimal first pass at hardware
    [bGeigieNanoKit.brd, bGeigieNanoKit.sch]
2012-10-17 updated hardware files using auto generated footprints
    [bGeigieNanoKit.brd, bGeigieNanoKit.sch]
2012-10-17 library updated with full module footprints. test components removed. board updated to use new library components.
    [bGeigieNanoKit.brd, bGeigieNanoKit.sch]
2012-10-19 updated library footprints with single/double sided options. preliminary component placement on board to verify fit.
    [bGeigieNanoKit.brd, bGeigieNanoKit.sch]
2012-10-24 full set of components added to library. initital placement of all components.
    [bGeigieNanoKit.brd, bGeigieNanoKit.sch]
2012-10-29 resize board to be better fit in case. did inital pass at routing.
    [bGeigieNanoKit.brd, bGeigieNanoKit.sch]
2012-10-30 fully routed board
    [bGeigieNanoKit.brd, bGeigieNanoKit.sch]
2012-10-31 cleaned up final routing
    [bGeigieNanoKit.brd, bGeigieNanoKit.sch]
2012-10-31 cleaning up libs and updating brd
    [bGeigieNanoKit.brd, bGeigieNanoKit.sch]
2012-10-31 smashing all parts and moving labels to be visable adding current limit resistor for charge led add lables to leds
    [bGeigieNanoKit.brd, bGeigieNanoKit.sch]
2012-11-06 adding v2 version of the board with a single LCD
    [bGeigieNanoKit_v2.brd, bGeigieNanoKit_v2.sch]
2012-11-06 gererating outputs for single OLED layout. changigng to toggle switch
    [bGeigieNanoKit.brd, bGeigieNanoKit.sch, bGeigieNanoKit_v2.brd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]
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2013-01-11 resolving pin conflict and fixing selector switch and vbatt inputs
    [NanoConfig.h]
2013-01-18 enabling GPS led lock intidator for pcb kit
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2013-02-12 adding HW readme with current location of development
2013-02-16 Fixed running time in bGiegie mode
    bGeigie mode was diplaying not the realtime but elapsed time
    [bGeigieNano.ino]
2013-02-16 File format fix
    Frmat fields was not correct according to the file format in Github
    [bGeigieNano.ino]
2013-02-16 Changed R5 and R9 to 4.7 k
    For decreasing the load on the IRover output to prevent lower CPM count.
    [bGeigieNanoKit.brd, bGeigieNanoKit.sch]
2013-03-04 V1.1.0
    Added Switch to XGeigie mode at 10% power and displays message.
    Shows battery status in % on second screen.
    Removed some code that seemed used in bGiegie for sleepmode only to get
    some more free memory for added functions.
2013-03-04 Error message Low Battery in Caps and reversed
    [bGeigieNano.ino]
2013-03-04 Red LOG LED and battery status change.
    Red LOG LED light up if GPS and Radiation data valid in bGeigiemode
    and battery status display change.
2013-03-05 XGeigie alarm setup
    XGeigie mode alarm setup taken from CPM level of SAFECAST.TXT
    Second splash screen Mode and Alarm info (Mode info not working yet)
    [NanoConfig.h, bGeigieNano.ino]
2013-03-06 LED alarm mode and battery status change.
    Alarm LED blicks in XGeigie mode if threshold is crossed. It now blick
    every 5 seconds.
    Some adjustments for the startup % battery status to have 100% when
    full changed
2013-03-21 Update Version for over 1k display bug fix
    [NanoConfig.h]
2013-04-01 LOG LED
    Fix for LOG LED/ GPS locked aand radiation data valid to be switch of
    if GPS or radiations data becomes unavaliable
    [bGeigieNano.ino]
2013-04-01 Higher than 100uS/h fix
    [bGeigieNano.ino]
2013-04-01 Display units small if over 1kCPM
    In bGiegieMode over 1k CPM display switches to smaller unit to allow
    more digits to be displayed.
    In xGiegieMode over 5k CPM display switches to smaller unit to allow
    more digits to be displayed.
2013-04-04 V1.1.4 fix high CPM
    [NanoConfig.h, bGeigieNano.ino]
2013-04-04 V1.1.5 uSv/H to mSv/h switch to display higer levels
    uSv/H to mSv/h switch to display higer levels
2013-04-04 V1.1.6 switched digit after decimal point in low and high rreading mode xGeigieNano
2013-04-12 V1.1.7 NS SD Card error message
    Displays "NO SD CARD" message if no SD card is present at startup. Also
    disables the the LOG light in bGeigiemode.
    [NanoConfig.h, bGeigieNano.ino]
2013-04-14 V1.1.8 bq/m2 display fixed by high radiation levels in xGeigie mode
    [NanoConfig.h, bGeigieNano.ino]
2013-04-16 V1.1.9 reverse display in xGeigie mode not working
    removed some mistaken test code.
    [NanoConfig.h, bGeigieNano.ino]
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2013-04-28 V1.2.0 NO GPS error reversed
    V1.2.0 NO GPS error reversed display in bGiegie Mode
    [NanoConfig.h, bGeigieNano.ino]
2013-05-02 Config and Safecast parameters chnage
    a parameter to adjust the disaply for time zone - can you add a task on
    Github to implement this. This could also be used to set the date/time
    for the LOG file so it makes more sense
    [CONFIG.TXT]
2013-05-06 Switched display sequence for more clear display
    Switched display sequence for more clear display
2013-05-06 V1.2.2
    Fixed xGeigie display mode
    [NanoConfig.h, bGeigieNano.ino]
2013-05-09 V1.2.3
    Switched duration and height distance
    [CONFIG old.TXT, CONFIG.TXT]
2013-05-09 Revert "V1.2.3"
    This reverts commit 668ce3222101854a211a2feaaed39e447b06664e.
    [CONFIG old.TXT, CONFIG.TXT]
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2013-07-05 V1.2.6
    Fixed number sateltites
    [NanoConfig.h, bGeigieNano.ino]
2013-07-14 V.1.2.7
    nbstat fixed again
    [NanoConfig.h, bGeigieNano.ino]
2013-07-16 Fixed nanoconfig.h
    Fix for 2013 ID
    [NanoConfig.h]
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2013-08-07 V1.2.8
    Changed serial baudrate to 14400 for communications with BLEbee (can
    reset if needed back to 9600)
    [NanoConfig.h, bGeigieNano.ino]
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2013-10-28 Fix imprecision issue with coordinates parsing
    [bGeigieNano.ino]
2013-11-05 V1.3.1
    If SD card out the GPS will be reset
    [NanoConfig.h, bGeigieNano.ino]
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2013-11-06 V1.3.1 fix
    Disabled LOCK LED when the GPS is reset
    [bGeigieNano.ino]
2013-11-11 V1.3.2
    Really 1.2.8 with added functionality of 1.3.0. to gt GPS reset
    working. GPS can be reset by removing SD card on startup. A message
    will be display "No SDcard/. GPS reset". After power down and power up
    the GPS module will be completly reset and will take time to lock for
    the first time.After that locking should acure fast.
    [NanoConfig.h, bGeigieNano.ino]
2014-01-07 Revert "Changed the log line format to comply with bGeigieMini standard."
    This reverts commit 4fbbef94e25989889c8bba96a1c2e9804324ab9b.
    [bGeigieNano.ino]
2014-01-30 Nano lasercut files
    .ai file with cutting instructions. Delete text before sending to
    lasercutter.
2014-05-08 Revised manual images May 2014
    5 revised photos showing audio connector as optional; one new photo
    showing new 1200mAh battery.
2015-10-16 Added V1.0r4 boards
    [bGeigieNanoKit V1.0r4.brd, bGeigieNanoKit V1.0r4.sch]
2017-03-24 Added V1.1r4 a,c,x boards
    [bGeigieNanoKit V1.1r4a.brd, bGeigieNanoKit V1.1r4a.sch, bGeigieNanoKit V1.1r4c.brd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]
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2017-05-24 Fixed V1.1r4a board for deleted trace and added gerber files. Added editable templates for CS6.
    [bGeigieNanoKit V1.1r4a.brd, bGeigieNanoKit V1.1r4x.brd]
2017-05-24 Fix for V1.1r4a boards
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2017-12-13 Moved indiction for 60s /5s to be in sync with display switching.
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2018-01-03 Added fix for display 4 digits in kCPM mode
    [bGeigieNano.ino]
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2018-06-02 Fix SDcard reading (Ray)
    [bGeigieNano.ino]
2018-06-07 Added newer board files and labled hex and zip of the Mac upload application.
    [bGeigieNanoKit V1.1r5a.GBL, bGeigieNanoKit V1.1r5a.GBO, bGeigieNanoKit V1.1r5a.GBP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]
2018-07-30 V1.4.2 test for fix for uS/h display in hot spot mode
    [NanoConfig.h, bGeigieNano.ino]
2018-08-02 V1.4.2 with display fix
    [bGeigieNano.ino]
2018-08-03 Display fix for not logging mode small display
    [NanoConfig.h, bGeigieNano.ino]
2019-01-07 Fixed schematic for V1.1.5 board.
2019-03-23 Updated wrong NanaoConfig.h (was for older boards) and cleanup.
    [NanoConfig.h]
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2021-06-30 Prevent lost interrupts; deal with floating point cast issues
    The way that the code was dealing with interrupts, there was a window
    in which interrupts would be lost. This change fixes that window by
    never resetting the hardware counter, and instead just allowing it
    to run continuously and then just sampling the 'difference' from
    the last time it was sampled.
    In order to do the necessary "wraparound" processing for the hardware
    counter, it is critical that the compiler knows the exact C data type
    of the counter so that unsigned subtraction is done using the
    appropriate number of bits. For this reason, I define a new type
    for the hardware counter and use that type uniformly every time
    the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
    [bGeigieNano.ino]
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2021-10-24 V1.4.4 fix by Ray
    [bGeigieNano.ino]

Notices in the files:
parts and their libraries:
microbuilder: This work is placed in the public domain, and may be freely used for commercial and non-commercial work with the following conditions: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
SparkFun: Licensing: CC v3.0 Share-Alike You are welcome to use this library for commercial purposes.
